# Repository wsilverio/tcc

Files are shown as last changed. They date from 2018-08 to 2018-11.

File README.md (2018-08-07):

# tcc

#### Desenvolvimento de Mesa de Luz Interativa para Experimento de Ciências para Crianças

#### Disposição do Projeto

- [tcc/changelog.md](changelog.md)
  - Registro de alterações
- [tcc/todo.md](todo.md)
  - Lista de tarefas
- [tcc/hardware](hardware/)
  - Arquivos de esquemático
  - Arquivos de leiaute e de produção (gerber)
  - Bibliotecas CAD
  - Cálculos
  - Datasheets
- [tcc/source](source/)
  - Códigos-fonte
  - Bibliotecas
  - Scripts
- [tcc/cad](cad/)
  - Arquivos CAD
  - Documentação da mecânica
- [tcc/documentos](documentos/)
  - Relatórios
  - Burocracia

------

Universidade Federal do Paraná, Setor de Tecnologia, Departamento de Engenharia Elétrica

Autores e Autora: Wendeurick Emerick Silverio, James Alexandre Baraniuk e Maristela Mitsuko Ono.

Curitiba 2018

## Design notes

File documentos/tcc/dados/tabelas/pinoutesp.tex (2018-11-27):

\begin{table}[H]
    \centering
    \caption[Pinagem do módulo ESP-12]{Pinagem do módulo ESP-12.
    \label{tab:pinoutesp}}
\begin{tabular}{|l|l|}
\hline
\textbf{Pino} & \textbf{Descrição} \\ \hline
$V_{CC}$ & Alimentação 3,3\ V \\ \hline
GPIO 13 & Também usada pela SPI \\ \hline
GPIO 12 & Também usada pela SPI \\ \hline
GPIO 14 & Também usada pela SPI \\ \hline
GPIO 16 & Deve ser conectada ao RESET no modo \emph{Deep Sleep} \\ \hline
$CH_{PD}$ & \emph{Chip enable}: (0) desabilitado; (1) habilitado \\ \hline
ADC & Entrada do ADC \\ \hline
RESET & \emph{Reset} externo: (0) - \emph{reset}; (1) - normal \\ \hline
TXD & Transmissão da UART \\ \hline
RXD & Recepção da UART \\ \hline
GPIO 4 & GPIO regular \\ \hline
GPIO 5 & GPIO regular \\ \hline
GPIO 0 & Modo \emph{flah} se em nível baixo durante a inicialização \\ \hline
GPIO 2 & Deve estar em nível alto durante a inicialização \\ \hline
GPIO 15 & Deve estar em nível baixo durante a inicialização e gravação \\ \hline
GND & Terra \\ \hline
\end{tabular}
    \fonte{\cite{book-esp}}
\end{table}

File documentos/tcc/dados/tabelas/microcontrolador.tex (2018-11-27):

\begin{table}[H]
    \centering
    \caption[Especificação do ESP8266]{Especificação do ESP8266.
    \label{tab:espec-microcontrolador}}
    \begin{tabular}{|l|l|}
    \hline
    Alimentação & 3,3\ V \\ \hline
    Consumo & $10\ \mu A - 170\ mA$ \\ \hline
    Memória Flash (externa) & 16\ MB máx. (512\ kB normal) \\ \hline
    CPU & Tensilica L106 32 bits \\ \hline
    \emph{Clock} & $80 - 160\ MHz$ \\ \hline
    RAM & $32\ kB - 80\ kB$ \\ \hline
    GPIOs & 17 (compartilhadas com outras funções) \\ \hline
    ADC & 1 canal (10 \emph{bits} de resolução) \\ \hline
    \emph{Wireless} & Estação, ponto de acesso ou ambos \\ \hline
    \end{tabular}
    \fonte{\cite{book-esp}}
\end{table}

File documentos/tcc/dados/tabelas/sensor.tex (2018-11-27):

\begin{table}[H]
    \centering
    \caption[Principais características do sensor TCRT5000]{Principais características do sensor TCRT5000.
    \label{tab:sensor}}
    \begin{tabular}{|l|l|l|l|l|l|l|}
        \hline
        \textbf{Parâmetro} & \textbf{Condição} & \textbf{Símb.} & \textbf{Mín.} & \textbf{Típ.} & \textbf{Máx.} & \textbf{Unidade} \\     \hline
        \emph{LED} - Corrente direta &  & $I_{F}$ &  & 60 &  & mA \\ \hline
        \emph{LED} - Queda direta de tensão & $I_{F} = 60\ mA$ & $V_{F}$ &  & 1,25 & 1,5 & V \\ \hline
        \emph{LED} - Comprimento de onda & $I_{F} = 100\ mA$ & $\lambda_{P}$ & 940 &  &  & nm \\ \hline
        Sensor - Corrente de coletor & \begin{tabular}[c]{@{}l@{}}$@5\ V$,\\ $I_{F} = 10\ mA$,\\ $D=12\ mm$\end{tabular} & $I_{C}$ & 0,5 & 1 & 2,1 & mA \\ \hline
        \begin{tabular}[c]{@{}l@{}}Sensor - Queda de tensão entre\\ coletor-emissor na saturação\end{tabular} & \begin{tabular}[c]{@{}l@{}}$I_{F} = 10\ mA$, \\ $I_{C}=0,1\ mA$,\\ $D=12\ mm$\end{tabular} & $V_{CE_{sat}}$ &  &  & 0,4 & V \\ \hline
    \end{tabular}
    \fonte{\citeonline{datasheet-sensor}}
\end{table}

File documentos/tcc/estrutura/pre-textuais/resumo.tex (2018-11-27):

% RESUMO--------------------------------------------------------------------------------

\begin{resumo}[RESUMO]
\begin{SingleSpacing}

% Não altere esta seção do texto--------------------------------------------------------
\imprimirautorcitacao. \imprimirtitulo. \imprimirdata. \pageref {LastPage} f. \imprimirprojeto\ – \imprimirprograma, \imprimirinstituicao. \imprimirlocal, \imprimirdata.\\
%---------------------------------------------------------------------------------------

O presente trabalho refere-se ao desenvolvimento do protótipo de uma matriz de LED que será parte da exposição interativa ``Luz, Ciência e Emoção'', idealizada pela arquiteta Dra. Maristela Mitsuko Ono e pelo engenheiro Dr. James Alexandre Baraniuk. A matriz, chamada de ``Mesa de Bolinhas'', se enquadra no setor artístico da exposição, que traz experimentos envolvendo os conceitos de luz trabalhados nos ensinos pré-escolar e fundamental, e proporcionará uma experiência tangível-visual impactante aos observadores, causando deslumbramento e entusiamos através da interação com arte e tecnologia.

O projeto conta com técnicas de \emph{software} e \emph{hardware} para endereçar 129 LEDs RGBs e controlar seus 387 canais de PWM, mapear 128 sensores reflexivos e submetê-los a rotinas de \emph{debouncing}, implementar máquina de estados finita em \emph{firmware}, desenvolver um teclado analógico com apenas uma GPIO, projetar um conversor de nível lógico não-inversor com um único transistor, entre outras funcionalidades.\\

\textbf{Palavras-chave}: Matriz de LED. Matriz de sensores. Arte generativa.

\end{SingleSpacing}
\end{resumo}

% OBSERVAÇÕES---------------------------------------------------------------------------
% Altere o texto inserindo o Resumo do seu trabalho.
% Escolha de 3 a 5 palavras ou termos que descrevam bem o seu trabalho

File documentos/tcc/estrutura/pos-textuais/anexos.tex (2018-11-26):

% ANEXO------------------------------------------------------------------------

\begin{anexosenv}
%\partanexos

%% Primeiro anexo---------------------------------------------------------------
%\chapter{Nome do anexo}     % edite para alterar o título deste anexo
%\label{chap:anexoA}
%
%Lembre-se que a diferença entre apêndice e anexo diz respeito à autoria do texto e/ou material ali colocado.

%Caso o material ou texto suplementar ou complementar seja de sua autoria, então ele deverá ser colocado como um apêndice. %Porém, caso a autoria seja de terceiros, então o material ou texto deverá ser colocado como anexo.

%Caso seja conveniente, podem ser criados outros anexos para o seu trabalho acadêmico. Basta recortar e colar este trecho %neste mesmo documento. Lembre-se de alterar o "label"{} do anexo.

%Organize seus anexos de modo a que, em cada um deles, haja um único tipo de conteúdo. Isso facilita a leitura e compreensão %para o leitor do trabalho. É para ele que você escreve.
%
%% Novo anexo-------------------------------------------------------------------
%\chapter{Nome do outro anexo}
%\label{chap:anexoB}
%
%conteúdo do outro anexo

\end{anexosenv}

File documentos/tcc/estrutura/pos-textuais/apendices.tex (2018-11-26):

% APÊNDICES--------------------------------------------------------------------

\begin{apendicesenv}
\partapendices

%\chapter{application.cpp} 
%\inputminted{cpp}{dados/algoritmos/application.cpp}

%\chapter{user_config.h} 
%\label{chap:user-config}
%\inputminted{cpp}{dados/algoritmos/user_config.h}

\chapter{plomodefs.h} 
\inputminted{cpp}{dados/algoritmos/plomodefs.h}

\chapter{plomotypes.h} 
\inputminted{cpp}{dados/algoritmos/plomotypes.h}

\chapter{tabmask8.h} 
\inputminted{cpp}{dados/algoritmos/tabmask8.h}

\chapter{sensors.h} 
\inputminted{cpp}{dados/algoritmos/sensors.h}

\chapter{hardware.h} 
\inputminted{cpp}{dados/algoritmos/hardware.h}

\chapter{application.cpp} 
\inputminted{cpp}{dados/algoritmos/application.cpp}

\chapter{hardware.cpp} 
\inputminted{cpp}{dados/algoritmos/hardware.cpp}

\chapter{sensors.cpp} 
\inputminted{cpp}{dados/algoritmos/sensors.cpp}

\end{apendicesenv}

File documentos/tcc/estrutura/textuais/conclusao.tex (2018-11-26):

% CONCLUSÃO--------------------------------------------------------------------

\chapter{CONCLUSÃO}
\label{chap:conclusao}

O principal objetivo deste trabalho era apresentar um protótipo funcional para a Mesa de Bolinhas. Embora não tenha sido atingido em sua totalidade, o projeto se encontra em uma etapa avançada. Entre os objetivos específicos apresentados, foram finalizadas as etapas do mapeamento da matriz de saída (LEDs), do mapeamento da matriz de entrada (sensores da matriz e do seletor de cores), do leiaute da placa de interface, do leiaute da placa de controle, do \emph{firmware} gerenciador da matriz de entrada, da montagem das placas de interface, sendo ainda pendente a montagem da placa de controle, a integração com a mecânica e a finalização das rotinas da máquina de estados finita.

Para o autor, o projeto serviu de grande aprendizado de técnicas e ferramentas não abordadas durante a graduação, tais como: projeto de leiaute de placa de circuito impresso a nível intermediário, programação do microcontrolador ESP8266, programação orientada a eventos temporais, implementação de fila (FIFO), implementação de técnica de \emph{debouncing} para múltiplas entradas, implementação de máquina de estados finita em \emph{software}, entre outras.

\section{TRABALHOS FUTUROS}
\label{sec:trabalhosFuturos}

Para que o projeto continue avançando, pretende-se, além de finalizar a montagem proposta neste trabalho, implementar novas funcionalidades, funções estas que não necessitam de alteração de \emph{hardware}, visto que já foram consideradas no projeto dos circuitos:

\begin{itemize}
    \item Gravação OTA (\emph{over-the-air}): com essa funcionalidade, o microcontrolador poderá ser reprogramado sem a necessidade do adaptador USB: a gravação será via Wi-Fi, dispensando a remoção do tampo acrílico todas as vezes que uma atualização for necessária;
    \item Protocolo ArtNet: permitirá que a mesa seja comandada remotamente através de programas de mapeamento de luz (via Wi-Fi, sobre a camada de UDP). Assim, a matriz poderá servir como tela para animações e exibição de textos e imagens;
    \item Fita de LED externa: foi implementado em \emph{hardware} uma saída para fitas de LED com suporte ao protocolo NRZ. Dessa forma, a mesa também poderá controlar outras instalações, sem a necessidade de um circuito dedicado
    
\end{itemize}

Além disso, o \emph{hardware} e o código serão documentados e disponibilizados à comunidade, para que o projeto possa ser estudado, replicado e modificado conforme suas necessidades.

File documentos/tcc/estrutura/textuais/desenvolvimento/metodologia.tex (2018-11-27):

% METODOLOGIA------------------------------------------------------------------

\chapter{DESENVOLVIMENTO}
\label{chap:metodologia}

Este capítulo aborda o desenvolvimento do \emph{hardware} do projeto, desde a concepção do projeto eletrônico, levantamento do circuito elétrico, até as técnicas de roteamento das placas de circuito impresso.

\section{CONCEPÇÃO DO PROJETO}
\label{sec:concepcao}

Com base no projeto arquitetônico e a partir do levantamento das tecnologias disponíveis e viáveis (sobretudo pelo custo e pela difusão no mercado), foram definidos os componentes e técnicas a serem utilizadas no projeto eletrônico, cujo diagrama geral é apresentado na \autoref{fig:diagramageral}.

\begin{figure}[H]
    \centering
    \caption{Diagrama geral do projeto eletrônico}
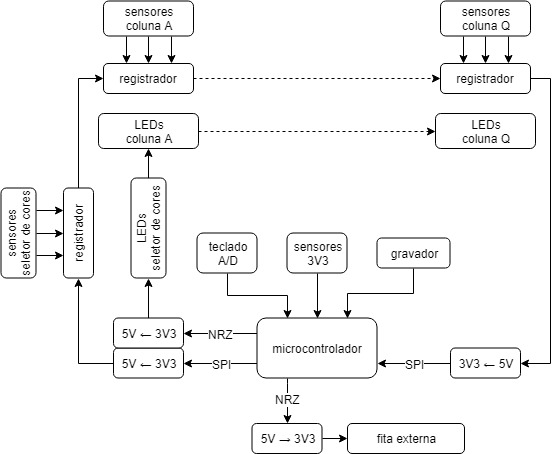
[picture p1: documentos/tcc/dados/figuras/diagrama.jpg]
    
    \fonte{(O AUTOR, 2018)}
    \label{fig:diagramageral}
\end{figure}

A partir do projeto arquitetônico (\autoref{fig:mesa-sup}), que é segmentado em duas partes: Matriz (interação) e Controle (seletor de cores), o projeto eletrônico também foi organizado em 3 subdivisões: Matriz, Interface e Controlador, apresentadas na \autoref{fig:subsecoes}. Dessa forma, pôde-se dar andamento ao projeto por meio de etapas, onde cada fase pode ser considerada um projeto íntegro por si só.

\begin{figure}[H]
    \centering
    \caption{As 3 subseções principais do projeto eletrônico}
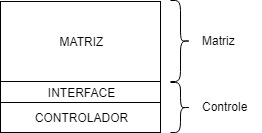
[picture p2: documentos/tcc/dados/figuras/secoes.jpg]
    
    \fonte{(O AUTOR, 2018)}
    \label{fig:subsecoes}
\end{figure}

As subdivisões têm funções bem definidas, apresentadas logo abaixo, e serão discutidas neste mesmo capítulo nos tópicos a seguir.

\begin{itemize}
    \item \textbf{Matriz:} é o setor que pode ser ``pintado com luz'', que contém os LEDs e os sensores de interação. É inteiramente comandada pelo Controlador, através da Interface;
    \item \textbf{Interface:} interliga as subseções Matriz e Controlador: captura e propaga o sinal dos sensores, através dos registradores de deslocamento, e forma a ligação sequencial do barramento dos LEDs;
    \item \textbf{Controlador:} processa todos os LEDs e sensores da mesa. Contém também os LEDs e os sensores do seletor de cores, a parte de processamento, os conversores de nível lógico e os periféricos de gravação e depuração.
\end{itemize}

%\textcolor{red}{TODO: especificações, tensão}

%\textcolor{red}{TODO: software}

\section{PROJETO DA MATRIZ}
\label{sec:matriz}

O projeto da Matriz foi concebido durante o Programa de Iniciação Científica do qual o autor participou. Nele, o desafio foi o de contemplar todas as 118 bolinhas de \emph{ping-pong} desta seção (e seus respectivos pares sensor-LED), visando robustez e o menor custo.

Para tal, foi definido que a matriz seria arranjada em 17 colunas verticais, conforme apresentado na \autoref{fig:placas-matriz-colunas}. Consequentemente, devido à disposição dos objetos (determinada pelo projeto arquitetônico), essas colunas poderiam conter 5, 6, 7 ou 8 bolinhas e, para abrangê-las da maneira mais proveitosa, as colunas foram combinadas por módulos (placas) de 2 ou 3 bolinhas.

Em geral, as empresas fabricantes de placas de circuito impresso consideram cada modelo de placa como um projeto, devido ao corte do painel, procedimento para os testes elétricos, etc. Assim, se utilizando de apenas 2 modelos de placa, foi possível reduzir o custo do projeto sem dispensar a robustez que as PCIs proporcionam.

\begin{figure}[H]
    \centering
    \caption{Disposição das placas da Matriz}
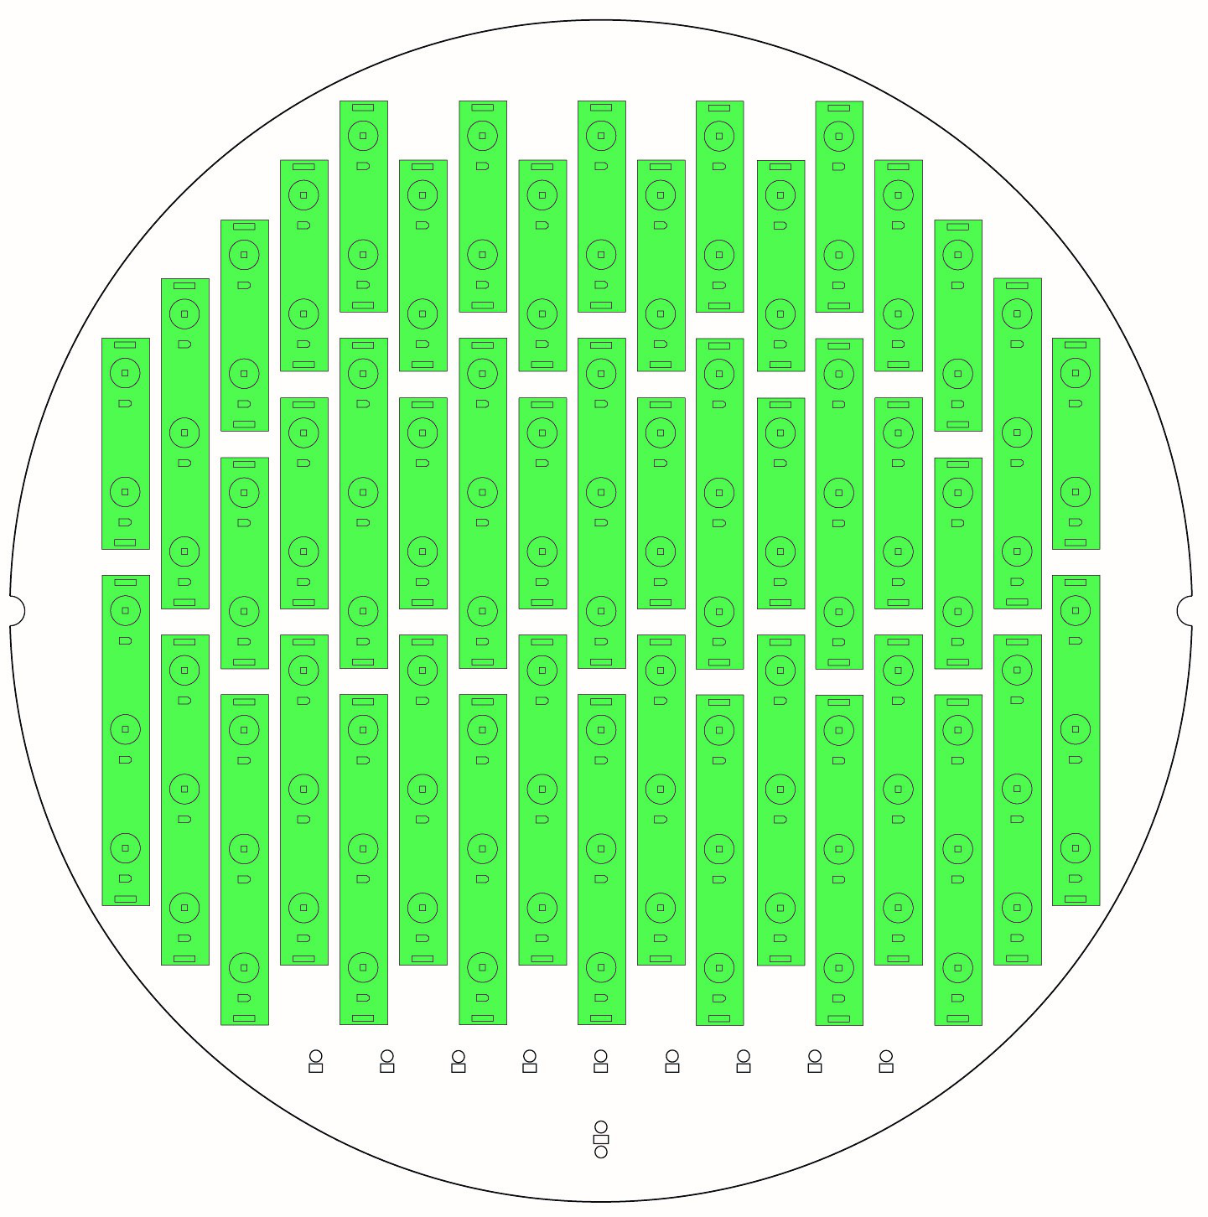
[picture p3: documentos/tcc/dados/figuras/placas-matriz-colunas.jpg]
    
    \fonte{adaptado de (MITSUKO, 2016)}
    \label{fig:placas-matriz-colunas}
\end{figure}

Uma vez definido que a matriz seria composta por placas com 2 ou 3 bolinhas, iniciaram-se os testes de conceito com o protótipo artesanal, apresentado na \autoref{fig:matriz-prototipo}, produzido no Laboratório de Corrosão de Placas do Departamento de Engenharia Elétrica da UFPR. Nesses ensaios, foram testados os conceitos de endereçamento do LED WS2812, a leitura do nível lógico dos sensores através dos registradores de deslocamento e também o modo de conexão entre as placas.

\begin{figure}[H]
    \centering
    \caption{Protótipo das placas da matriz}
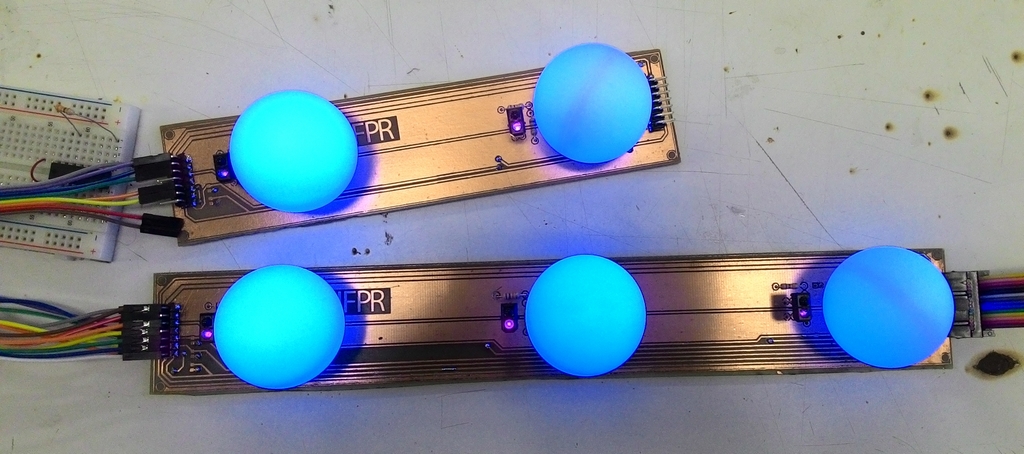
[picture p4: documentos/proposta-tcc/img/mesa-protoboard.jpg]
    
    \fonte{(O AUTOR, 2017)}
    \label{fig:matriz-prototipo}
\end{figure}

Todos os conceitos propostos foram validados e as 47 placas que compõem a matriz foram confeccionadas em produção industrial. A \autoref{fig:placa2} e a \autoref{fig:placa3} apresentam as faces superior e inferior dos módulos.

\begin{figure}[H]
    \centering
    \caption{Faces da PCI do módulo de 2 bolinhas}
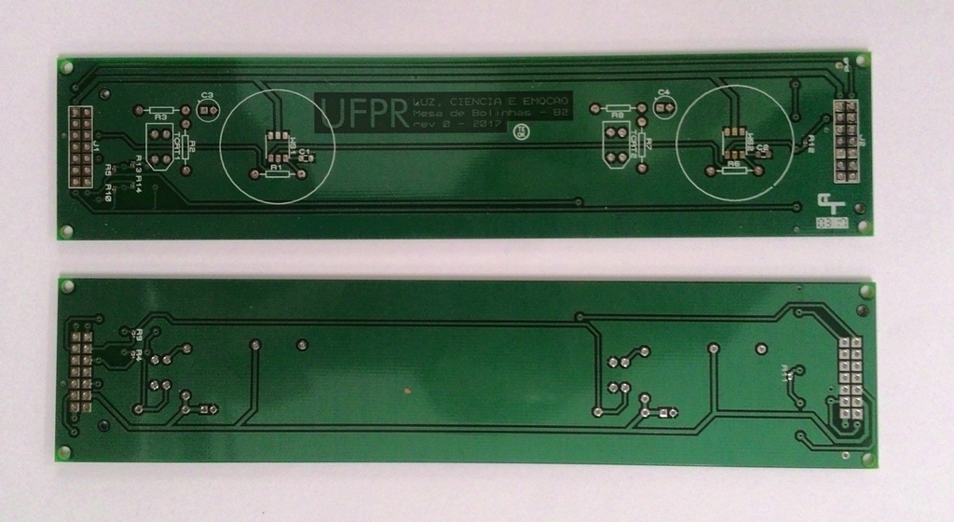
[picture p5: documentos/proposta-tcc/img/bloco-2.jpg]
    
    \fonte{(O AUTOR, 2017)}
    \label{fig:placa2}
\end{figure}

\begin{figure}[H]
    \centering
    \caption{Faces da PCI do módulo de 3 bolinhas}
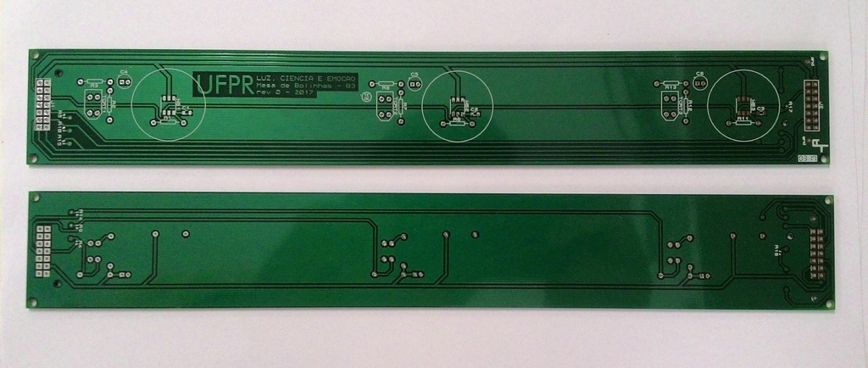
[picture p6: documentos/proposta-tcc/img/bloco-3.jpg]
    
    \fonte{(O AUTOR, 2017)}
    \label{fig:placa3}
\end{figure}

\section{PROJETO DA INTERFACE}
\label{sec:interface}

Como já brevemente introduzido pela \autoref{sec:concepcao} (Concepção do Projeto), a Interface tem a função de interligar as seções Matriz e Controlador. Contudo, deve-se atentar a algumas questões:

\begin{enumerate}[label=\Roman*.]
    \item Tanto o barramento dos sensores, quanto o barramento dos LEDs devem seguir a sequência da esquerda para a direita; de baixo para cima;
    \item Por integrar barramentos de frequências razoáveis - NRZ {@800\ kHz} e SPI {@4\ MHz} dos LEDs e sensores, respectivamente - deve-se evitar construir trilhas com quinas abruptas, em função da reflexão do sinal;
    %\item As trilhas de potência devem ser adequadas para suportarem a corrente no caso mais extremo.
\end{enumerate}

A questão (I) foi trabalhada visando a redução de custo, decidiu-se que Interface também seria um projeto modular, isto é, esta seção seria dividida em placas do mesmo modelo. Isso é em razão do valor das placas de circuito impresso ser calculado em função de sua área e que cada projeto possui um pedido mínimo. Em outras palavras, quanto maior a área de uma PCI, maior será o seu custo, e quanto mais modelos de placa, maior será a quantidade a ser adquirida, pois cada modelo possui um pedido mínimo para produção. Sendo assim, a Interface foi projetada para abranger todas as colunas da Matriz em duas ``metades'', como é apresentado na \autoref{fig:colunas}. No caso, uma placa teria a função de operar as primeiras 9 colunas (de A a I) e a outra, as 8 colunas restantes (de J a Q).

\begin{figure}[H]
    \centering
    \caption{Divisão das colunas para conexão com a Interface}
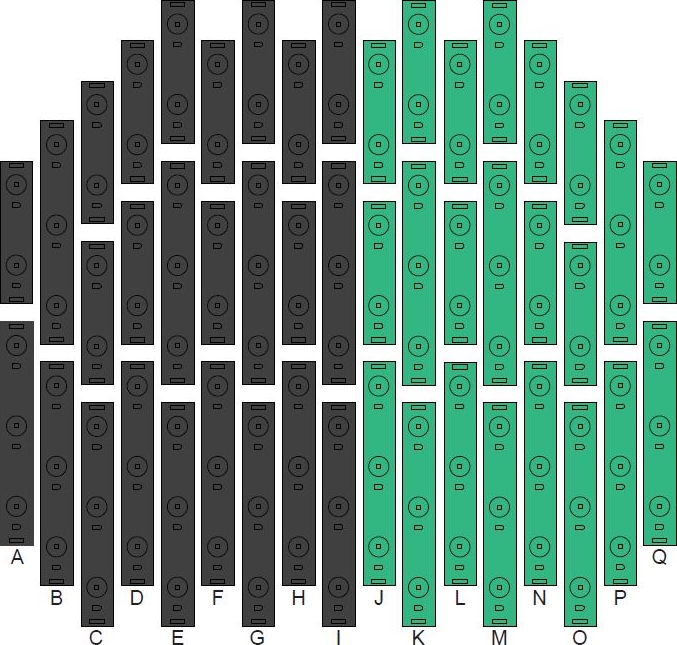
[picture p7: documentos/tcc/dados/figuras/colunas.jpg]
    
    \fonte{adaptado de (MITSUKO, 2016)}
    \label{fig:colunas}
\end{figure}

A \autoref{fig:diagrama-interface} apresenta o diagrama da formação do barramento dos sensores. Nele, cada coluna da Matriz é conectada a um registrador de deslocamento, em forma sequencial (A:1, ..., I:9; J:1, ..., Q:8). Nota-se também que o último registrador da segunda placa não possui conexão, dado que todas as colunas já foram abrangidas pelos registradores precedentes.

\begin{figure}[H]
    \centering
    \caption{Diagrama do barramento da Interface}
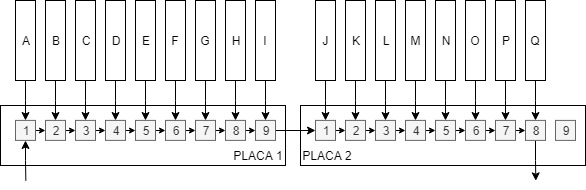
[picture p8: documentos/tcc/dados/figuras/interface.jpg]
    
    \fonte{(O AUTOR, 2018)}
    \label{fig:diagrama-interface}
\end{figure}

Esse direcionamento do barramento é dado por um resistor de {$0\ \Omega$}, como apresentado na \autoref{fig:direcionamento-shift} (componente ``R2''). Se montado, o sinal é diretamente conduzido ao conector de saída (``P11''), ignorando o último registrador (``U9'') que, neste caso, não seria montado.

\begin{figure}[H]
    \centering
    \caption{Direcionamento do barramento dos sensores}
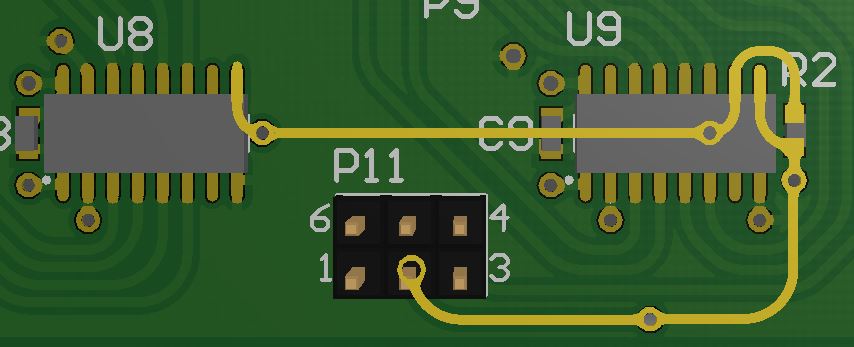
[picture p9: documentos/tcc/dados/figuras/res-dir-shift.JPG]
    
    \fonte{(O AUTOR, 2018)}
    \label{fig:direcionamento-shift}
\end{figure}

De iguais modos, o barramento dos LEDs foi projetado para seguir a mesma sequência (\autoref{fig:sentido-leds}) e o direcionamento entre a última coluna (``P9'') ou o conector de saída (``P11'') também é dado através de um resistor de {$0\ \Omega$} (``R1''), como apresentado na \autoref{fig:direcionamento-leds}.

\begin{figure}[H]
    \centering
    \caption{Sentido do barramento dos LEDs}
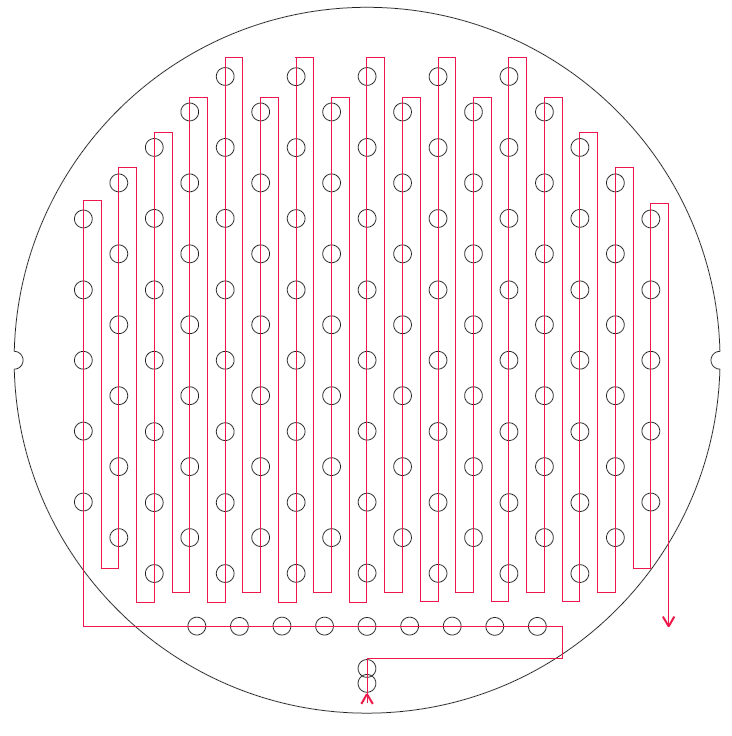
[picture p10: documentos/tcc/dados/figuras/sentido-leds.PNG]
    
    \fonte{adaptado de (MITSUKO, 2016)}
    \label{fig:sentido-leds}
\end{figure}

\begin{figure}[H]
    \centering
    \caption{Direcionamento do barramento dos LEDs}
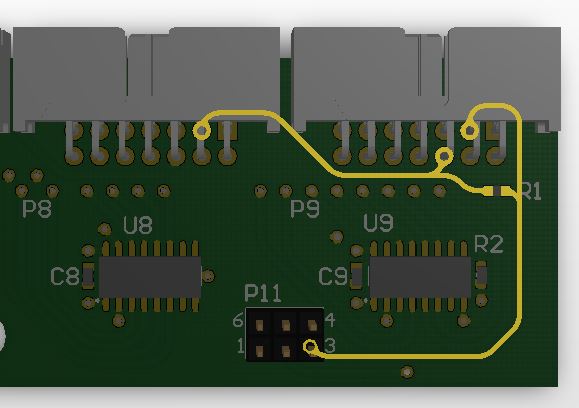
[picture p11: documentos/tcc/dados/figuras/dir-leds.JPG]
    
    \fonte{(O AUTOR, 2018)}
    \label{fig:direcionamento-leds}
\end{figure}

Já em relação à questão (II), sobre a possibilidade de reflexão de sinais devido à perturbação da capacitância e auto-indutância da trilha, seguiu-se a recomendação de leiaute de \cite{datasheet-ti}, apresentada na \autoref{fig:leiaute-ti}.

\begin{figure}[H]
    \centering
    \caption{Recomendação de leiaute para as trilhas de sinal}
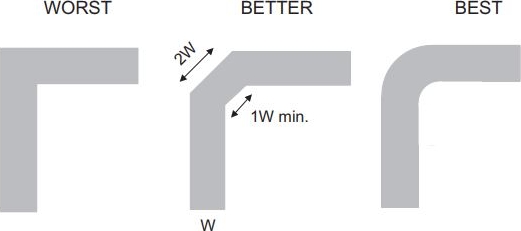
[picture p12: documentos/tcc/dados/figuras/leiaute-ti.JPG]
    
    \fonte{\citeonline{datasheet-ti}}
    \label{fig:leiaute-ti}
\end{figure}

Tal técnica foi aplicada não só nas trilhas de sinais, mas também em todas as ocasiões possíveis, como apresentado na \autoref{fig:trilhas-arredondadas}.

\begin{figure}[H]
    \centering
    \caption{Trilhas arredondadas}
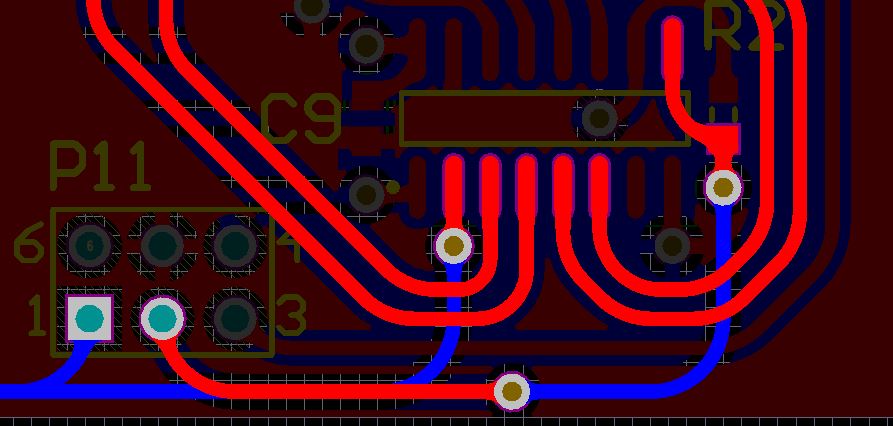
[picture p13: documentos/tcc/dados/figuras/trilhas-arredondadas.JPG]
    
    \fonte{(O AUTOR, 2018)}
    \label{fig:trilhas-arredondadas}
\end{figure}

Além disso, para evitar a propagação do ruído da parte de potência, a alimentação do circuito lógico (``VCC5V'') foi separada da alimentação dos LEDs (``VLED'') e da dos sensores (``VSENSOR''), conforme apresentado na \autoref{fig:interface-alimentacao}. Ademais, a conexão física entre as massas (terra) é feita somente em um único ponto, assim, o retorno da alimentação de potência ("GND\_MATRIX") permanece confinado, não circulando sobre o plano de terra ("GND"). Essa técnica é conhecida por \emph{``net-tie''} e está destacada na \autoref{fig:interface-nettie}.

\begin{figure}[H]
    \centering
    \caption{Separação das alimentações da Interface}
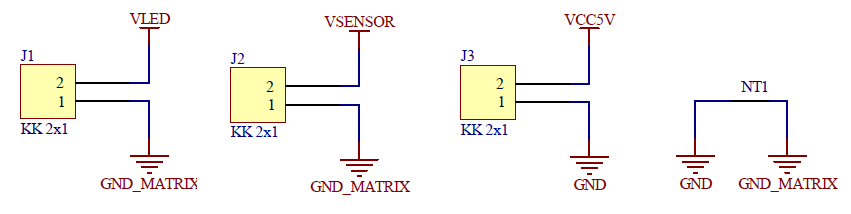
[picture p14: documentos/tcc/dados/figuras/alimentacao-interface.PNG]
    
    \fonte{(O AUTOR, 2018)}
    \label{fig:interface-alimentacao}
\end{figure}

\begin{figure}[H]
    \centering
    \caption{Separação física das massas}
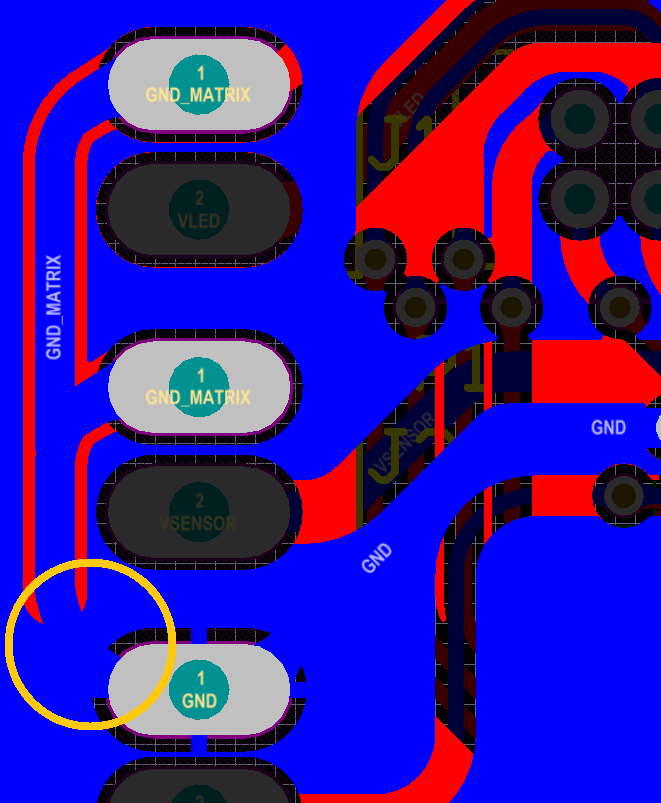
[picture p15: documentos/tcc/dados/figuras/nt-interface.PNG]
    
    \fonte{(O AUTOR, 2018)}
    \label{fig:interface-nettie}
\end{figure}

Por fim, a \autoref{fig:3d-interface} apresenta o modelo 3D da placa de interface. Trata-se de uma PCI face-dupla, {245\ mm} x {32,76\ mm}. Os conectores de alimentação (à esquerda da placa) são da série KK Molex\textsuperscript{\textregistered}, que impedem a inversão de polaridade na conexão com fonte de alimentação externa, e os conectores das colunas (parte superior da placa) são do padrão \emph{Latch-header}, recomendado para aplicações com limitação de espaço. Cada placa suporta até 9 colunas de até 8 sensores, e as PCIs podem ser ligadas em série para compartilharem o mesmo barramento.

\begin{figure}[H]
    \centering
    \caption{Modelo 3D da Interface}
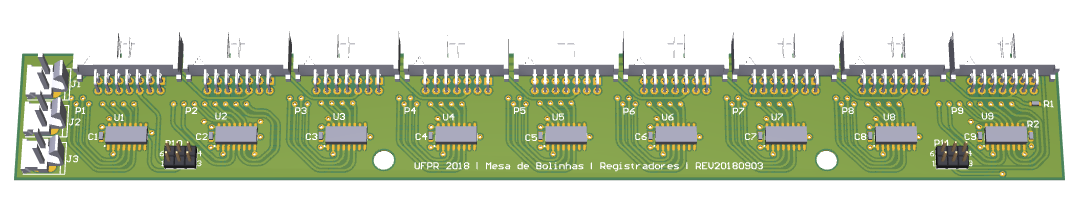
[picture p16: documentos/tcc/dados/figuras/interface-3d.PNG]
    
    \fonte{(O AUTOR, 2018)}
    \label{fig:3d-interface}
\end{figure}

\section{PROJETO DO CONTROLADOR}
\label{sec:controlador}

O Controlador é responsável por comandar os eventos de interação, através da Interface, da seção Matriz. Ademais, engloba também o seletor de cores, circuito de gravação, teclado para depuração e suporte para um barramento externo. A \autoref{fig:diagrama-controlador} apresenta seu diagrama simplificado.

\begin{figure}[H]
    \centering
    \caption{Diagrama da seção Controlador}
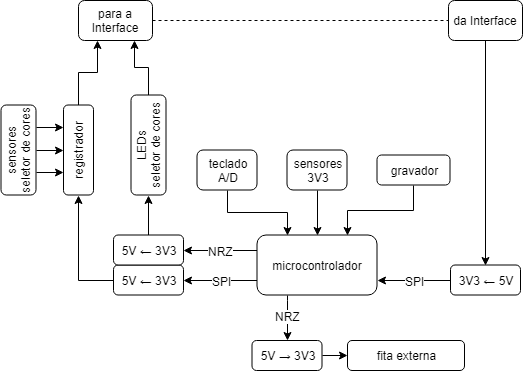
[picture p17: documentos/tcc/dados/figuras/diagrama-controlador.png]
    
    \fonte{(O AUTOR, 2018)}
    \label{fig:diagrama-controlador}
\end{figure}

\subsection{ALIMENTAÇÃO  E CONVERSÃO DE NÍVEL LÓGICO}
\label{subsec:alimentacao}

Da mesma forma que na Interface, a alimentação do Controlador também foi dividida, separando os circuitos de potência (``VLED'') e lógico (``VCC5V''), inclusive com \emph{net-tie} isolando fisicamente as massas. Porém, diferente da Matriz, onde a quantidade de LEDs e sensores é muito maior que a do seletor de cores do Controlador, esses circuitos compartilham a mesma alimentação de potência neste projeto. A \autoref{fig:alimentacao-controlador} apresenta o circuito de entrada de alimentação.

Como o microcontrolador operar em {3,3\ V}, houve a necessidade de incluir um regulador para a faixa especificada. Por se tratar de um circuito de carga simples, isto é, de baixo consumo, optou-se por um regulador linear de saída fixa (componente ``U2''). Para protegê-lo da descarga das capacitâncias conectadas à sua saída (por exemplo, o capacitor ``C23''), foi incluído um diodo de \emph{bypass} (``D27'') para desviar a corrente reversa sobre regulador, no caso da fonte externa ser desconectada e a tensão de saída resultar em um potencial mais alto que o de entrada. Esse diodo também possui a função de proteger o regulador caso o desenvolvedor queira alimentar a placa diretamente através do circuito de gravação, a ser discutido mais adiante.

\begin{figure}[H]
    \centering
    \caption{Entrada de alimentação do Controlador}
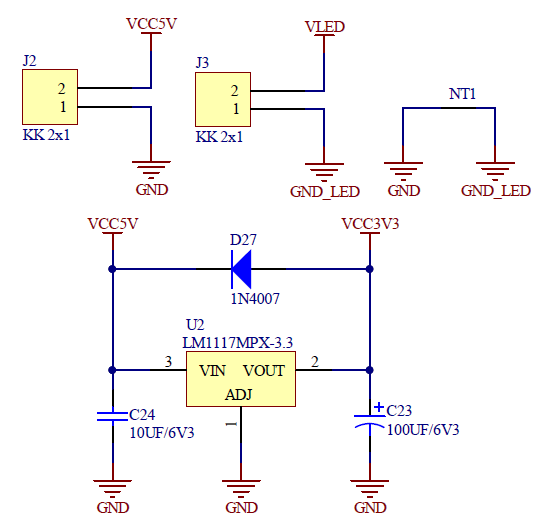
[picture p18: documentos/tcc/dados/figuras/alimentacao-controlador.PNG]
    
    \fonte{(O AUTOR, 2018)}
    \label{fig:alimentacao-controlador}
\end{figure}

\subsection{SELETOR DE CORES}
\label{subse:seletor}

O seletor de cores forma a primeira etapa dos barramentos, seja dos LEDs endereçáveis ou dos registradores de deslocamento. É composto por 10 sensores reflexivos e 11 LEDs endereçáveis, como apresentado na \autoref{fig:seletor-cores}, e a \autoref{fig:diagrama-seletor-cores} apresenta seu diagrama.

\begin{figure}[H]
    \centering
    \caption{Vista do seletor de cores}
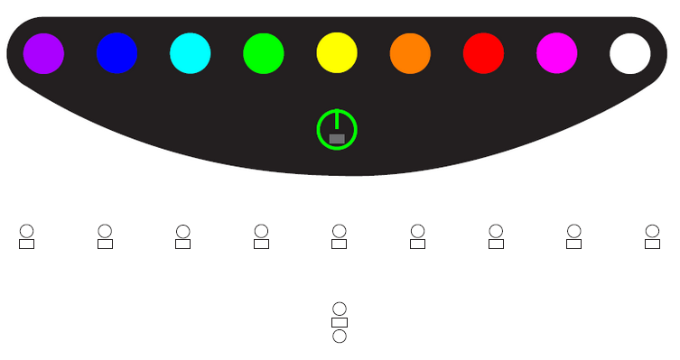
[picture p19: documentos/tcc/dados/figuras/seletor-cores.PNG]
    
    \fonte{adaptado de (MITSUKO, 2016)}
    \label{fig:seletor-cores}
\end{figure}

\begin{figure}[H]
    \centering
    \caption{Vista do seletor de cores}
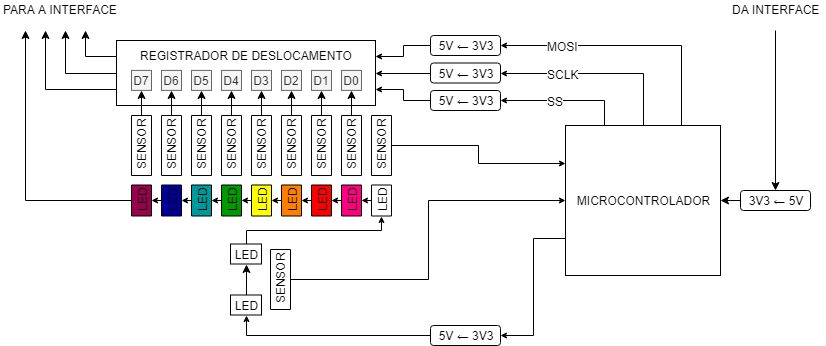
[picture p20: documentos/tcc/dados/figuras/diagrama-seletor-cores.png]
    
    \fonte{(O AUTOR, 2018)}
    \label{fig:diagrama-seletor-cores}
\end{figure}

Assim como feito com as colunas da Matriz, por meio das placas da Interface, o registrador de deslocamento é responsável por coletar os níveis lógicos de 8 dos 10 sensores do seletor de cores, restando 2 sensores fora do barramento. Assim, optou-se por conectá-los diretamente aos pinos do microcontrolador, visto que haviam GPIOs livres.

Devido aos LEDs e registradores de deslocamento serem alimentados em {5\ V}, enquanto que o microcontrolador é alimentado em {3,3\ V}, foi necessário adequar os sinais dos barramentos através de conversores de nível lógico. Essa conversão se deu de duas formas, nos seguintes sinais:

\begin{itemize}
    \item De {3,3\ V} para {5\ V}:
        \begin{itemize}
            \item Saída de dados do barramento NRZ (LEDs WS2812)
            \item Saída de dados do barramento SPI (MOSI)
            \item Saída de clock do barramento SPI (SCLK)
            \item Sinal de seleção de periférico do barramento SPI (SS)
        \end{itemize}
    \item De {5\ V} para {3,3\ V}:
        \begin{itemize}
            \item Entrada de dados do barramento SPI (MISO)
        \end{itemize}
\end{itemize}

Os conversores de nível de {3,3\ V} para {5\ V} foram projetados na topologia não-inversora, com transistor NPN operando nas regiões de corte e saturação: mantêm-se base e coletor polarizados - base em {3,3\ V} e coletor em {5\ V} - enquanto que a polarização da junção base-emissor ($V_{BE}$) é dada pela aplicação do sinal no emissor.

A \autoref{fig:3v3-5v} apresenta o esquemático do conversor para o sinal de \emph{clock} do barramento SPI. Nota-se que, quando o sinal ``ESP\_CLOCK'' (saída SCLK do microcontrolador ESP8266) vai a 1-lógico ({3,3\ V}), não há diferença de potencial entre a base e o emissor ({$V_{BE}=0\ V$}), portanto, o transistor está em corte, logo a saída ``SHIFT\_CLK'' (entrada de \emph{clock} do \emph{shift-register}) vai a {5\ V} (1-lógico).

No caso da aplicação de {0\ V} (0-lógico) por ``ESP\_CLOCK'', a junção base-emissor estará diretamente polarizada, o que, neste caso, levará o transistor à saturação. Com isso, a tensão em ``SHIFT\_CLK'' será a diferença de potencial entre coletor e emissor ($V_{CE}$) somada à queda de tensão sobre o \emph{mosfet} interno da GPIO do microcontrolador, resultando em um potencial relativamente próximo a {0\ V} (0-lógico).

Cabe aqui ressaltar inclusão do diodo de \emph{Baker clamping} para minimizar os efeitos das capacitâncias parasitas do transistor.

\begin{figure}[H]
    \centering
    \caption{Conversor de nível lógico da linha de \emph{clock} do barramento SPI}
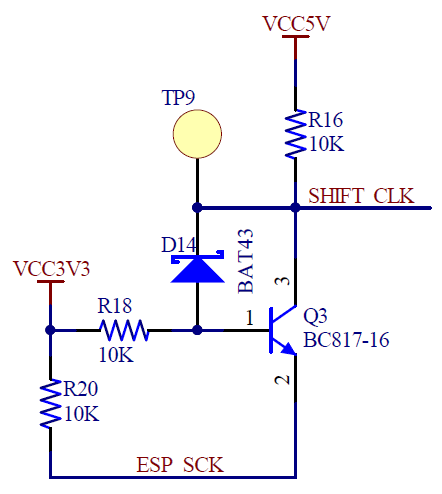
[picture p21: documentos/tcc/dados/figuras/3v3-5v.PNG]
    
    \fonte{(O AUTOR, 2018)}
    \label{fig:3v3-5v}
\end{figure}

Já para a situação de transformação de {5\ V} para {3,3\ V}, como é o caso do retorno do sinal dos registradores de deslocamento das placas de interface (sinal MISO), a implementação do conversor de nível lógico foi dada por um simples divisor resistivo, como apresentado na \autoref{fig:5v-3v3}.

\begin{figure}[H]
    \centering
    \caption{Conversor de nível lógico da linha MISO do barramento SPI}
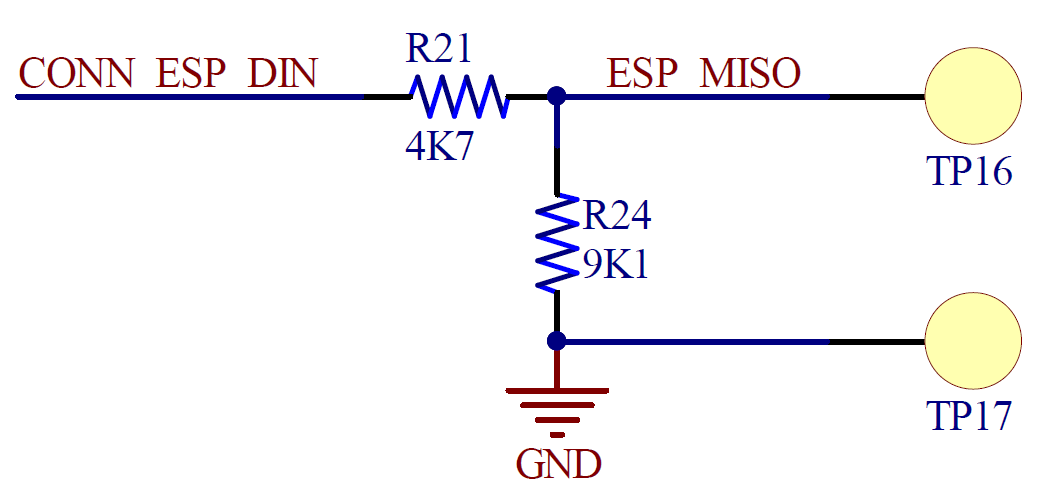
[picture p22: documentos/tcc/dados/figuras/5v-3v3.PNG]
    
    \fonte{(O AUTOR, 2018)}
    \label{fig:5v-3v3}
\end{figure}

Quando aplicado {5\ V} (1-lógico) em ``CONN\_ESP\_DIN'' (entrada de dados do conector, linha MISO do barramento SPI), a tensão em ``ESP\_MISO'' (linha MISO do microcontrolador) será aproximadamente {3,3\ V} (1-lógico), dado pela \autoref{eq:5v-3v3}. De mesmo modo, quando aplicado {0\ V} na entrada do conversor, não haverá queda de tensão sobre o resistor de saída (''`R24``), portanto a tensão em ``ESP\_MISO'' também será {0\ V} (0-lógico).

\begin{equation}
    V = {5\ V} \cdot \frac{9100\ \Omega}{9100\ \Omega+4700\ \Omega} = 3,297\ V
    \label{eq:5v-3v3}
\end{equation}

\subsection{GRAVADOR}
\label{subsec:gravador}

O microcontrolador ESP8266 possui alguns modos de operação, entre eles, o modo normal e o de gravação via UART, que são determinados pelo estado de alguns pinos durante a inicialização do sistema (\emph{boot}), como brevemente introduzido na \autoref{sec:microcontrolador}.

Além de fornecer uma via para a comunicação serial com um adaptador USB, o circuito apresentado a seguir (\autoref{fig:circuito-gravador}) também tem a função de forçar o microcontrolador a entrar em modo de gravação conforme os comandos de \emph{``reset''} e \emph{``data terminal ready''} (DTR) do adaptador. Dessa forma, não há a necessidade de uma operação manual para determinar os estados dos pinos de programação para carregar um novo \emph{firmware} no microcontrolador. Para tal, basta somente que o adaptador disponha de uma linha DTR, como o exemplo apresentado na \autoref{fig:ftdi}. Cabe aqui ressaltar que, assim como citado na \autoref{subsec:alimentacao}, todo o circuito de {3,3\ V} pode ser alimentado diretamente pelo adaptador USB (desde que seja {3,3\ V}), sem a necessidade de uma fonte externa. Isso simplifica o desenvolvimento e a depuração do projeto, quando não houver a necessidade de testar o restante do circuito.

\begin{figure}[H]
    \centering
    \caption{Exemplo de adaptador serial-USB com linha DTR}
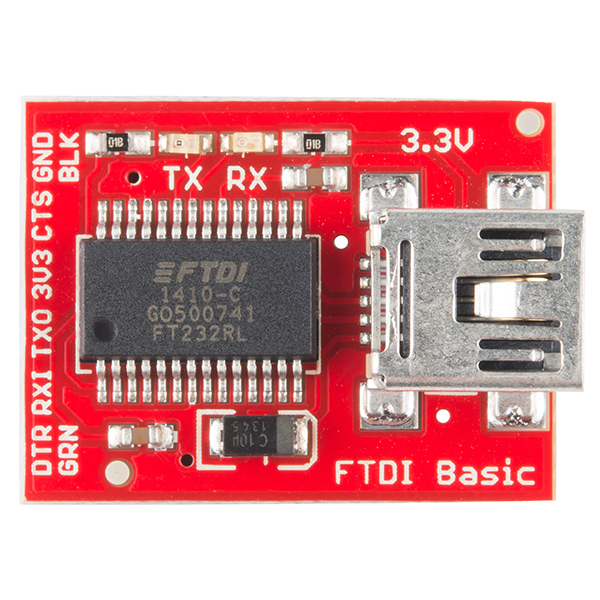
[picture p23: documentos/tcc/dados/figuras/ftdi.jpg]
    
    \fonte{\citeonline{adaptador-usb}}
    \label{fig:ftdi}
\end{figure}

Sobretudo, para que o microcontrolador entre em modo de gravação, o pino ``GPIO 0'' deve estar em 0-lógico durante a inicialização. Se estiver em 1-lógico durante o \emph{reset}, o ESP8266 inicializa em modo normal, executando o programa armazenado na memória interna.

\begin{figure}[H]
    \centering
    \caption{Esquemático do circuito de gravação}
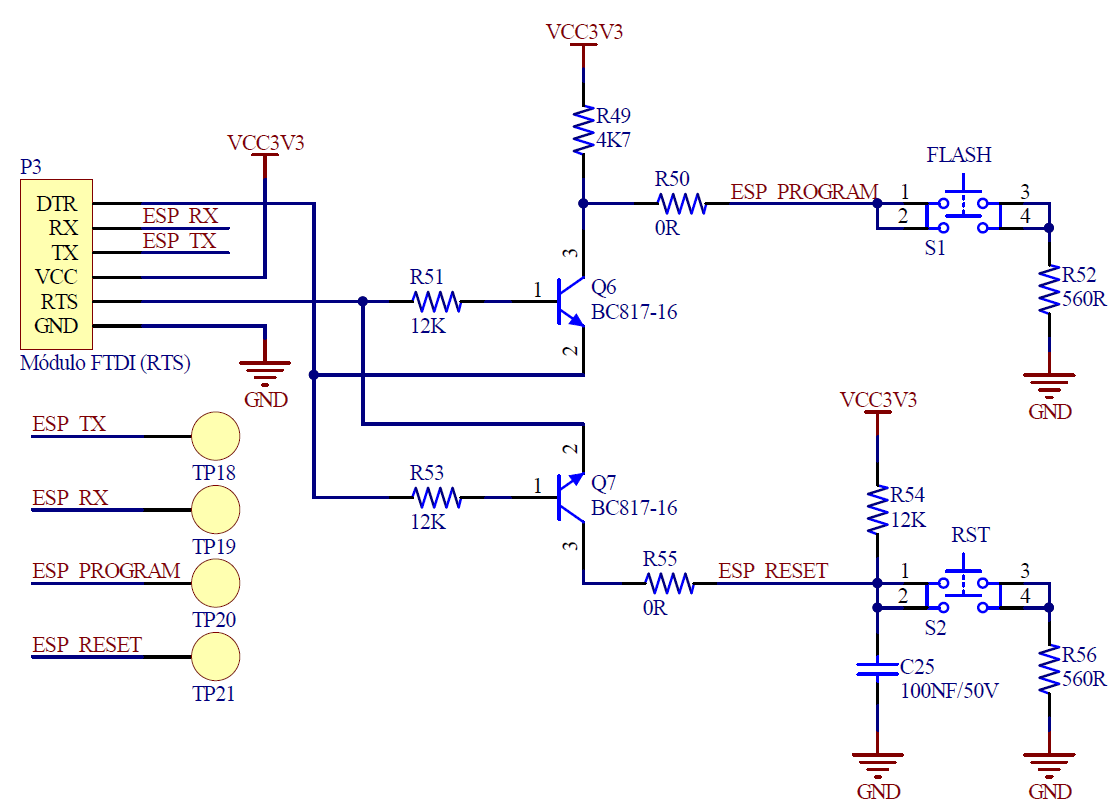
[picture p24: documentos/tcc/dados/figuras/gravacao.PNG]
    
    \fonte{(O AUTOR, 2018)}
    \label{fig:circuito-gravador}
\end{figure}

A \autoref{tab:gravador} apresenta os estados dos pinos do microcontrolador em função dos níveis do adaptador USB, através do circuito da \autoref{fig:circuito-gravador}. Contudo, se o desenvolvedor não dispor de um adaptador USB com sinal DTR, ainda há a possibilidade de pôr o microcontrolador em modo de gravação de maneira manual, através dos botões ``S1'' e ``S2''.

\input{./dados/tabelas/gravacao}

\subsection{TECLADO AD}
\label{subsec:tecladoad}

O ``Teclado AD'' (ou teclado analógico) tem a função de servir como interface durante as etapas de desenvolvimento/depuração. Com apenas um único pino do microcontrolador é possível ler diversas teclas, desde que seja um pino com função Conversor Analógico-Digital. A \autoref{fig:tecladoad} apresenta o esquemático do circuito.

\begin{figure}[H]
    \centering
    \caption{Esquemático do circuito do teclado analógico}
    
    \fonte{(O AUTOR, 2018)}
    \label{fig:tecladoad}
\end{figure}

Seu funcionamento se dá por meio da combinação de uma cadeia de resistores. Através da Lei de Ohm, pelas combinações série-paralelo, é possível estimar qual botão está sendo pressionado, limitando-se a um botão por vez.

A \autoref{tab:tecladoad} apresenta os valores de tensão e as unidades estimadas pelo conversor interno do microcontrolador, um ADC de 10 \emph{bits} de resolução, com faixa de operação de {0\ V} a {1\ V}.

\input{./dados/tabelas/tecladoad}

\subsection{PROJETO DA PCI DO CONTROLADOR}
\label{subsec:pcicontrol}

Em sua totalidade, não há um padrão de repetição de funcionalidades como nos outros setores (Interface e Matriz), então a placa do Controlador não foi projetada de maneira modular, senão em placa única que, inclusive, resultou em uma PCI relativamente grande (500 mm x 90 mm), a ser discutida na \autoref{chap:analise-resultados}.A \autoref{fig:controlador-top} apresenta a visão da face superior do modelo 3D da placa, e a \autoref{fig:controlador-bottom} apresenta a visão da face inferior.

\begin{figure}[H]
    \centering
    \caption{Visão superior do modelo 3D da placa do Controlador}
    
    \fonte{(O AUTOR, 2018)}
    \label{fig:controlador-top}
\end{figure}

\begin{figure}[H]
    \centering
    \caption{Visão inferior do modelo 3D da placa do Controlador}
    
    \fonte{(O AUTOR, 2018)}
    \label{fig:controlador-bottom}
\end{figure}

Assim como nos projetos anteriores, a placa do Controlador também foi projetada utilizando-se de técnicas para evitar a reflexão dos sinais, separação das alimentações dos circuitos de potência e utilização de conectores que impedem inversão de polaridade. Além disso, com exceção dos sensores e conectores, todos os componentes são de montagem em superfície (SMD), como apresentado na \autoref{fig:controlador-smd}.

\begin{figure}[H]
    \centering
    \caption{Visão inferior do modelo 3D da placa do Controlador - detalhe para os componentes SMDs}
    
    \fonte{(O AUTOR, 2018)}
    \label{fig:controlador-smd}
\end{figure}

%\section{PROJETO DO \emph{FIRMWARE}}
%\label{sec:firmware}

%\subsection{\emph{DEBOUNCE}}
%\label{subsec:debounce}

%\subsection{MÁQUINA DE ESTADOS FINITA}
%\label{subsec:fsm}

%\textcolor{red}{TODO: citar a referencia gang  of 4}

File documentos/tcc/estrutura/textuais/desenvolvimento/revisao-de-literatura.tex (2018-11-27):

% REVISÃO DE LITERATURA--------------------------------------------------------

\chapter{REVISÃO TEÓRICA}
\label{chap:fundamentacaoTeorica}

Este capítulo aborda alguns conceitos dos principais componentes e ferramentas utilizadas, bem como a especificação do projeto.

\section{PROJETO ARQUITETÔNICO}
\label{sec:matrizLed}

O projeto arquitetônico definiu a quantidade e a disposição de cada objeto. Ao todo, são 128 sensores e 129 pontos de luz, dispostos sob um tampo acrílico de {1 m} de diâmetro, conforme apresentado na \autoref{fig:tampo}.

\begin{figure}[H]
    \centering
    \caption{Disposição dos objetos na Mesa de Bolinhas}
    
    \fonte{(MITSUKO, 2016)}
    \label{fig:tampo}
\end{figure}

A arquiteta também especifica que o funcionamento da mesa deve ser orientado a eventos, provenientes das seções Controle e Matriz (\autoref{fig:mesa-sup}):

\begin{itemize}[noitemsep]
    \item A mesa sai do modo ocioso ao manter-se a mão sobre a bolinha \emph{Power} por mais de {1 s}: acende-se o seletor de cores e a mesa passa a interpretar os demais comandos;
    \item Escolhe-se uma cor ao manter-se a mão sobre uma determinada bolinha do seletor de cores por mais de {1 s};
    \item Ao passar a mão sobre uma determinada bolinha da seção Matriz, a mesma deve responder com a última cor escolhida;
    \item Uma bolinha da seção Matriz pode ser apagada se a ``cor'' escolhida tiver sido a da bolinha \emph{Power};
    \item Ao manter-se a mão por mais de {3 s} sobre a bolinha \emph{Power}, todas as bolinhas da seção Matriz devem ser apagadas; e
    \item Ao manter-se a mão por mais de {5 s} sobre a bolinha \emph{Power}, a mesa entra em modo ocioso: as bolinhas do seletor de cores são apagadas e a mesa passa a ignorar os comandos sobre a Matriz.
\end{itemize}

A partir da especificação acerca do funcionamento, notam-se alguns desafios do ponto de vista do eletrônico/lógico, tais como:

\begin{itemize}
    \item A disposição dos objetos e o tamanho da mesa;
    \item A capacidade de comandar individualmente 129 \emph{LEDs} coloridos (\emph{RGB}), ou seja $129 \times 3 = 387$ canais de cor;
    \item A capacidade de interpretar os níveis lógicos dos 128 sensores;
    \item A capacidade de responder, simultaneamente, aos comandos temporais provenientes de cada sensor.
\end{itemize}

A seleção dos componentes e das ferramentas foi baseada na especificação e nos desafios acima citados e será discutida a seguir nas demais seções deste capítulo.

\section{SENSOR}
\label{sec:sensor}

A função do sensor é identificar a posição de um objeto, no caso, a mão do espectador, sobre o tampo acrílico, e para manter-se centrado nos objetivos do projeto arquitetônico, a definição do tipo de sensor foi baseada em dois pontos essenciais:

\begin{enumerate}[label=\Roman*.]
    \item O elemento principal do projeto é a luz que flui da bolinha de \emph{ping-pong};
    \item A exposição pode ser levada a diversos lugares e ser instalada nos mais variados ambientes, como museus, escolas, saguões, etc.
\end{enumerate}

A questão (I) implica que o sensor não deve irradiar ondas eletromagnéticas dentro do espectro visível, que vai de {400 nm} a {700 nm} \cite{fundafisica}. Já a questão (II) implica que a instalação será submetida a locais com diferentes graus de iluminação, portanto os sensores devem ser imunes à variação luminosa do ambiente.

Assim sendo, optou-se pelo sensor óptico reflexivo \emph{TCRT5000L}, apresentado na \autoref{fig:sensor}, cujas características relevantes para o projeto são apresentadas na \autoref{tab:sensor}.

\begin{figure}[H]
    \centering
    \caption{Sensor TCRT5000}
    
    \fonte{\citeonline{datasheet-sensor}}
    \label{fig:sensor}
\end{figure}

\input{./dados/tabelas/sensor}

Trata-se de um sensor reflexivo infravermelho ($\lambda_{P}$), ou seja, opera fora do espectro visível, o que contorna a implicação da questão (I) apresentada anteriormente. Além disso, diferentemente de um sensor passivo, por exemplo um LDR, o TCRT5000 opera irradiando luz e, ademais, também contém filtro óptico embutido, absorvendo somente comprimentos de onda próximas a ($\lambda_{P}$). Essa duas características contornam a implicação da questão (II).

A saída transistorizada permite que o sensor seja interpretado de forma lógica. Sua aplicação (\autoref{fig:sensoraplicacao}) vai desde sensoriamento de \emph{encoders} e posições de ``fim de curso'' até detecção de papéis, cartões, fitas, etc. Foi escolhida a variante ``L'' (\emph{TCRT5000\textbf{L}}) por ser a versão com terminais estendidos.

\begin{figure}[H]
    \centering
    \caption{Aplicação do sensor TCRT5000}
    
    \fonte{\citeonline{datasheet-sensor}}
    \label{fig:sensoraplicacao}
\end{figure}

\section{REGISTRADORES DE DESLOCAMENTO}
\label{sec:registradores}

A necessidade de interpretar individualmente os 128 sensores implica na mesma quantidade de entradas do circuito de processamento. Então, optou-se por lidar com entradas virtuais, através de um barramento serial, por meio de registradores de deslocamento. Dessa forma, com poucas GPIOs, o microcontrolador pode interpretar os níveis lógicos de todos os sensores conectados ao barramento.

Devido sua grande difusão no mercado, o registrador de deslocamento escolhido foi o 74HC165. A \autoref{fig:shift-register} apresenta o diagrama funcional do circuito integrado.

\begin{figure}[H]
    \centering
    \caption{Diagrama funcional do 74HC165}
    
    \fonte{\citeonline{datasheet-shift-register}}
    \label{fig:shift-register}
\end{figure}

Trata-se de um registrador de deslocamento com 8 entradas em paralelo ($D_{N}$) e saídas complementares ($Q_{7}$ e $\overline{Q_{7}}$) em serial. Basicamente, seu funcionamento (\autoref{fig:shift-temporal}) constitui-se na captura instantânea do nível lógico de suas entradas (borda de descida da Entrada Assíncrona de Carga Paralela, $\overline{P_{L}}$) e na transmissão desses valores através de deslocamento ordenado ($D_{7} \rightarrow D_{0}$) na saída serial ($Q_{7}$), nos eventos de borda de subida na entrada de \emph{clock} ($C_{P}$).

\begin{figure}[!htb]
    \centering
    \caption{Diagrama temporal do 74HC165}
    
    \fonte{\citeonline{datasheet-shift-register}}
    \label{fig:shift-temporal}
\end{figure}

%\section{TECLADO ADC}
%\label{sec:tecladoAD}

\section{LED}
\label{sec:led}

Para formar a matriz de saída, optou-se pelo LED WS2812S (\autoref{fig:ws2812}), um dispositivo em encapsulamento SMD5050 com controlador interno, o WS2811: um \emph{driver} especial para LEDs, com 3 saídas de 8 \emph{bits} de resolução, ou seja, pode-se gerar até 16777216 cores do padrão RGB. Esse controlador é muito utilizado em fitas de LEDs endereçáveis (\autoref{fig:strip}), pois permite a conexão de vários controladores em um mesmo barramento serial (protocolo NRZ), podendo-se controlar cada LED individualmente.

O fato de possuir um controlador embutido no próprio encapsulamento implica diretamente sobre o valor do LED, custando um pouco mais que o dobro do valor médio de outros LEDs RGBs mais simples. Apesar disso, o custo acaba sendo compensado pelos benefícios que o \emph{driver} proporciona.

\begin{figure}[!htb]
    \centering
    \caption{Vista aproximada do LED WS2812 e seu controlador interno}
    
    \fonte{\citeonline{adafruit}}
    \label{fig:ws2812}
\end{figure}

O modelo do LED já havia sido selecionada durante o Programa de Iniciação Científica que o autor participou, já sendo utilizado no circuito da matriz. No projeto aqui proposto, eles serão utilizados no seletor de cores, discutido no \autoref{chap:metodologia}.

\begin{figure}[H]
    \centering
    \caption{Fita de LED endereçável utilizando o WS2812}
    
    \fonte{\citeonline{adafruit}}
    \label{fig:strip}
\end{figure}

\section{BAKER CLAMP}
\label{sec:backerclamp}

Segundo \citeonline{theartofelectronics}, os mesmos efeitos que limitam o desempenho de amplificadores lineares em altas frequências (a combinação de capacitância de junção, capacitância de retorno e capacitância parasita) também impõem limitações de velocidade em circuitos digitais de alta frequência. A \autoref{fig:tjb} apresenta um amplificador ``emissor comum'', que pode atuar como uma chave inversora quando operado em corte e saturação, alimentado por uma fonte de pulsos com tempos de subida e descida extremamente curtos, e a \autoref{fig:curvatjb} apresenta uma curva típica sobre a carga ($R_{C}$) desse tipo de amplificador ao considerar as componentes parasitas. 

\begin{figure}[H]
    \centering
    \caption{Representação de uma chave inversora com TJB}
    
    \fonte{\cite{theartofelectronics}}
    \label{fig:tjb}
\end{figure}

\begin{figure}[H]
    \centering
    \caption{Forma de onda da chave inversora com TJB}
    
    \fonte{\cite{theartofelectronics}}
    \label{fig:curvatjb}
\end{figure}

Nota-se que, assim que a fonte estabelece o pulso em nível baixo, o transistor leva um certo tempo ($t_r$) para sair da saturação e alcançar o estado de corte. Esse comportamento deriva-se do acúmulo de carga ($C_{cb}$) entre o coletor e a base. Dependendo das características físicas do transistor e da aplicação, esse tempo de subida pode vir a prejudicar o desempenho da finalidade do circuito, como é o caso do conversor de nível lógico elaborado para a Mesa de Bolinhas (discutido no \autoref{chap:metodologia}).

Para mitigar tal efeito, \citeonline{theartofelectronics} propõem a inclusão de um diodo de \emph{clamping} (também conhecido por  ``Baker \emph{clamp}''), entre a base e o coletor do TJB (\autoref{fig:bakerclamp}). Esse diodo irá desviar a corrente de base quando o transistor estiver se aproximando da saturação e evitará sua saturação, uma vez que a queda direta de tensão do diodo, no caso um diodo Schottky, é menor que a da junção coletor-base. Dessa forma, o TJB pode entrar em corte mais rapidamente, pois o mesmo não chega a entrar no ponto de saturação profunda.

\begin{figure}[H]
    \centering
    \caption{Chave inversora com o diodo de ``Baker \emph{clamping}''}
    
    \fonte{\cite{theartofelectronics}}
    \label{fig:bakerclamp}
\end{figure}

\section{MICROCONTROLADOR}
\label{sec:microcontrolador}

O ESP8266 é o microcontrolador de entrada para a família de 32 bits da fabricante chinesa Espressif Systems. Produzido em escala a partir de 2014, essa família ganhou espaço na área de Internet das Coisas por ser um microcontrolador de baixo custo, de baixo consumo e com suporte à rede 802.11 (\emph{Wi-Fi}). A \autoref{tab:espec-microcontrolador} apresenta as principais especificações do microcontrolador e a \autoref{fig:esp-funcional} apresenta seu diagrama funcional. Cabe aqui ressaltar que toda a parte de radio-frequência é implementada por \emph{hardware}, simplificando o desenvolvimento de aplicações com comunicação sem fio.

\input{./dados/tabelas/microcontrolador}

\begin{figure}[!htb]
    \centering
    \caption{Diagrama funcional do ESP8266}
    
    \fonte{\citeonline{datasheet-esp}}
    \label{fig:esp-funcional}
\end{figure}

Embora a comunicação sem fio não fizesse parte das especificações do projeto arquitetônico original, a equipe concordou com a possibilidade de implementá-la em uma aplicação futura. Esse foi o ponto decisivo para a escolha do ESP8266. Assim, a Mesa de Bolinhas poderá ganhar novas funcionalidades sem haver a necessidade de alteração no \emph{hardware}. Isso será discutido na \autoref{sec:trabalhosFuturos}.

Entre os diversos módulos que incluem o ESP8266, optou-se pelo ESP-12, por ser o que dispõe a maior quantidade de GPIOs (9 ao todo). A \autoref{fig:esp-12} apresenta sua placa. Convém salientar que este módulo já conta com memória \emph{Flash} (4\ MB) e antena \emph{microstrip}.

\begin{figure}[H]
    \centering
    \caption{Módulo ESP-12}
    
    \fonte{\cite{book-esp}}
    \label{fig:esp-12}
\end{figure}

Por serem compartilhados entre aplicações do usuário e funcionalidades internas, alguns pinos possuem certas particularidades. Os resistores  \emph{pull-up/pull-down} (\autoref{fig:esp-12}) garantem o nível lógico de alguns pinos, porém outros necessitam de uma atenção especial, sobretudo os que definem o modo de funcionamento: operação normal ou modo de gravação, que será discutido no \autoref{chap:metodologia}. A \autoref{tab:pinoutesp} apresenta a pinagem do módulo ESP-12 e também a função interna cada pino.

\input{./dados/tabelas/pinoutesp}

\section{\emph{FRAMEWORK}}
\label{sec:framework}

Sming é um \emph{framework} de código aberto, nativo para a família de microcontroladores ESP8266, desenvolvido na linguagem {C++} e com foco em alta eficiência em desempenho e em uso de memória.

Diferente de outros \emph{frameworks} baseados em laço-infinito, a estrutura do Sming é baseada em eventos temporais: as tarefas do usuário são escaladas em uma tabela de tempo. Isso o aproxima de uma das funcionalidades de um Sitema Operacional de Tempo Real, embora não haja, obviamente, um gerenciamento de recursos. Porém, o fato de poder-se escalar as tarefas em uma janela de tempo simplifica a implementação da especificação deste projeto, uma vez que, basicamente, sua funcionalidade também é baseada em eventos temporais, como apresentado no começo do capítulo (\autoref{sec:matrizLed}).

Por tratar-se de uma plataforma de código aberto, este \emph{framework} conta com uma vasta contribuição da comunidade, com uma API de \emph{hardware} robusta e diversas bibliotecas nativas, tais como \emph{bootloader}, sistema de arquivos (SPIFFS), atualização sem fio de \emph{firmware} (OTA) e uma extensa pilha assíncrona de rede (TCP, UDP, \emph{WebSockets}, etc). Esses recursos são úteis para a continuidade do projeto, discutida na \autoref{sec:trabalhosFuturos}.

%\section{FIFO}
%\label{sec:fifo}

%\textcolor{red}{TODO: revisão teórica FIFO}

\section{DEBOUNCE}
\label{sec:debounce}

Embora o funcionamento do sensor (\autoref{sec:sensor}) seja aparentemente simples - isto é, o transistor vai à saturação ao detectar um objeto; ou o transistor permanece em corte se não houver detecção - podem haver disparos falsos devido à oscilação do sinal durante a interação com a mesa. Essa oscilação é conhecida como \emph{bouncing}: trepidação do nível lógico durante a mudança de estado. A \autoref{fig:switch-bounce} apresenta um exemplo dessa oscilação, quando uma chave física passou do nível lógico alto para o baixo, ao ser pressionada.

\begin{figure}[H]
    \centering
    \caption{Oscilação do sinal de uma chave ao ser pressionada}
    
    \fonte{\citeonline{switch-debounce}}
    \label{fig:switch-bounce}
\end{figure}

Ainda que a Mesa de Bolinhas não conte com botões físicos, o efeito \emph{bouncing} pode vir a ocorrer em razão do limiar de detecção do sensor: o transistor de saída pode ficar operando, ainda que brevemente, no limite da interpretação do seu nível lógico. Para contornar tal situação, assim como nos casos de chaves físicas, será implementado um procedimento de \emph{debouncing}. \citeonline{debounceguide} cita diversas técnicas, desde descarte de tempo, filtros RC (resistor e capacitor), técnicas com \emph{latches} (\autoref{fig:srdebouncer}), entre outros, inclusive táticas via \emph{software}.

\begin{figure}[H]
    \centering
    \caption{Exemplo de circuito de \emph{debounce} com \emph{latches}}
    
    \fonte{\citeonline{debounceguide}}
    \label{fig:srdebouncer}
\end{figure}

No caso da Mesa de Bolinhas, não conviria implementar os modelos de  \emph{debouncing} por \emph{hardware}, pois implicaria diretamente no custo do projeto, não só pelo custo dos componentes, mas também pela área de placa ocupada, e também na complexidade do leiaute da PCI. Então, optou-se por implementar uma técnica de contorno via \emph{firmware}. Com isso, não há necessidade de adicionar componentes auxiliares ao circuito dos sensores e registradores de deslocamento. Trata-se de uma técnica baseada em ``histerese temporal'', onde a referência virtual altera-se de estado somente quando o nível de seu respectivo sensor já estiver estabilizado durante N milissegundos. A implementação dessa técnica será desenvolvida no \autoref{chap:metodologia}.

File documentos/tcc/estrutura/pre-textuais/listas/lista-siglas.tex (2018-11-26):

% LISTA DE ABREVIATURAS E SIGLAS----------------------------------------------------------
\begin{siglas}
    \item[ADC] do inglês \emph{Analog to Digital Converter}
    \item[API] do inglês \emph{Application Programming Interface}
    \item[CPU] do inglês \emph{Central Processing Unit}
    \item[FIFO] do inglês \emph{First In, First Out}
    \item[FSM] do inglês \emph{Finite-state Machine}
    \item[GPIO] do inglês \emph{General Purpose Input/Output}
    %\item[IC] Iniciação Científica
    %\item[IV] Radiação Infravermelha
    \item[LDR] do inglês \emph{Light Dependent Resistor}
    \item[LED] do inglês \emph{Light Emitting Diode}
    \item[MISO] do inglês \emph{Master Input Slave Output, or Master In Slave Out}
    \item[MOSI] do inglês \emph{Master Output Slave Input, or Master Out Slave In}
    \item[MuMa] Museu de Arte Municipal
    \item[NRZ] do inglês \emph{Non-return-to-zero}
    \item[OTA] do inglês \emph{Over-the-air}
    \item[PCI] Placa de Circuito Impresso
    \item[PIBIC] Programa Institucional de Bolsas de Iniciação Científica
    \item[PWM] do inglês \emph{Pulse Width Modulation}
    \item[RAM] do inglês \emph{Random Access Memory}
    \item[RGB] Sistema de cores aditivas, do inglês \emph{Red}, \emph{Green} e \emph{Blue}
    \item[SCLK] do inglês \emph{Serial Clock}
    \item[SMD] do inglês \emph{Surface Mounting Device}
    \item[SPIFFS] do inglês \emph{SPI Flash File System}
    \item[SS] do inglês \emph{Slave Select}
    \item[TCP] do inglês \emph{Transmission Control Protocol}
    \item[TJB] Transistor de Junção Bipolar
    %\item[TTL] do inglês \emph{Transistor-Transistor Logic}
    \item[UART] do inglês \emph{Universal Asynchronous Receiver-Transmitter}
    \item[UDP] do inglês \emph{User Datagram Protocol}
    \item[UFPR] Universidade Federal do Paraná
    \item[UNESCO] Organização das Nações Unidas para a Educação, a Ciência e a Cultura
    \item[USB] do inglês \emph{Universal Serial Bus}
\end{siglas}

% OBSERVAÇÕES-----------------------------------------------------------------------------
% Altere a lista acima para definir os acrônimos e siglas utilizados neste trabalho

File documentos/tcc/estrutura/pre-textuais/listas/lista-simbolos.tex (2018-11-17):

% LISTA DE SÍMBOLOS------------------------------------------------------------

\begin{simbolos}
    \item[$ \Omega $] Unidade de medida da resistência elétrica
    \item[$ \lambda $] Comprimento de onda
\end{simbolos}

% OBSERVAÇÕES-------------------------------------------------------------------
% Altere a lista acima para definir os símbolos utilizados no trabalho

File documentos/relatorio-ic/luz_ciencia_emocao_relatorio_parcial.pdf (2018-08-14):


MINISTERIO DA EDUCAÇ ´ | AÕ
UNIVERSIDADE FEDERAL DO PARANÁ
PRO-REITORIA DE PESQUISA E P ´ | OS-GRADUAÇ ´ | AÕ
COORDENADORIA DE INICIAÇ AO CIENT ˜ | ÍFICA E INTEGRAÇ AO ACAD ˜ | EMICA ˆ
PROGRAMA DE INICIAÇ AO CIENT ˜ | ÍFICA E EM DESENVOLVIMENTO
TECNOLOGICO E INOVAÇ ´ | AÕ

## Wendeurick Emerick Silverio

### RELATORIO PARCIAL ´

INICIAÇ AO CIENT ˜ | ÍFICA:
PIBIC CNPq ( ), PIBIC CNPq Açoes Afirmativas ( ), PIBIC UFPR TN ( ), PIBIC Fundaç ˜ | aõ
Araucaria ( ), PIBIC Volunt ´ | aria (x), PIBIC Aç ´ | oes Afirmativas Volunt ˜ | aria ( ) ou PIBIC EM. ´

01/08/2016 a 31/12/2016

## Desenvolvimento de Matriz de LED Interativa em Plataforma de Hardware Livre

Relatorio apresentado ´ | a Coordenadoria de `
Iniciaçao Cient ˜ | ífica e Integraçao Acad ˜ | emica ˆ
da Universidade Federal do Parana por ´
ocasiao da conclus ˜ | ao das atividades de ˜
Iniciaçao Cient ˜ | ífica - Edital 2016/2017.

Orientador: James Alexandre Baraniuk / Departamento de Engenharia Eletrica ´

Projeto de pesquisa: Luz, Ciencia e Emoç ˆ | ao: Exposiç ˜ | ao Interativa para Crianç as / ˜
2016019080
| CURITIBA
| 2017

## Sumario ´

1 RESUMO | 2
2 INTRODUÇ AO | 3 ˜
3 MATERIAIS E METODOS | 5 ´
4 CONCLUSOES/CONSIDERAÇ ˜ | OES FINAIS | 10 ˜
5 REFERENCIAS | 11 ˆ

## 1 RESUMO

Inspirada na proclamaçao do Ano Internacional da Luz pela Oganizaç ˜ | ao das Naç ˜ | oes ˜
Unidas, a exposiçao interativa “Luz, Ci ˜ | encia e Emoç ˆ | ao” prop ˜ | oe mais de vinte experimentos ˜
tendo a luz como tema principal. O seguinte trabalho apresenta o desenvolvimento de um desses experimentos.
Assim, o relatorio parcial aborda a elaboraç ´ | ao e a prototipagem do circuito da matriz de ˜
LED interativa chamada “Mesa de Bolinhas”, proposta pela arquiteta Dra. Maristela Mitsuko Ono.

## 2 INTRODUÇ AÕ

A luz exerce um papel essencial no nosso cotidiano e esta presente das mais diversas ´
formas: iluminaçao, medicina, pesquisas cient ˜ | íficas, geraçao de energia, telecomunicaç ˜ | | oes, ˜
educaçao, arte, cultura e etc. Em 2013, a Assembleia Geral das Naç ˜ | oes Unidas proclamou ˜
o ano de 2015 como o Ano Internacional da Luz e das Tecnologias Baseadas na Luz [1],
a fim de reconhecer tal importancia para a vida dos cidad ˆ | aos e para o desenvolvimento ˜
futuro da sociedade mundial. No ano da celebraçao, a UNESCO promoveu uma s ˜ | erie de ´
eventos por varios pa ´ | íses [2], com o intuito de destacar que o aumento da consciencia ˆ
mundial e o fortalecimento do ensino da ciencia e das tecnologias da luz s ˆ | ao essenciais para ˜
abordar os desafios futuros e atuais, tais como o desenvolvimento sustentavel, a energia ´
e as comunicaçoes, assim como para melhorar a qualidade de vida dos pa ˜ | | | íses menos
desenvolvidos e dos em desenvolvimento.
Baseada em tal iniciativa, a exposiçao “Luz, Ci ˜ | encia e Emoç ˆ | ao” traz experimentos envol- ˜
vendo os conceitos de luz trabalhados nos ensinos pre-escolar e fundamental, cada um com ´
seu grau de impressao aos sentidos. A exposiç ˜ | ao proporciona uma experi ˜ | encia tang ˆ | ível-
visual impactante aos observadores, causando deslumbramento e entusiasmo atraves da ´ arte e interaçao. ˜
Um dos experimentos que forma parte da area art ´ | ística da exposiçaõ e a “Mesa de ´
Bolinhas”, uma matriz de LED (Diodo Emissor de Luz, sigla em ingle) interativa, elaborada ˆ
pela arquiteta Dra. Maristela Mitsuko Ono. A mesa, de 1m de diametro, ˆ | e composta por mais ´
de 100 bolinhas de ping-pong, cada uma correspondente a um par LED-sensor reflexivo. Ela permite que o visitante “pinte com luz” ao passar a mao sobre a mesa. A vista superior ˜ do projeto e apresentada na Figura 1. ´

Figura 1: Vista superior da mesa


Fonte: (MITSUKO, 2016)

Partindo do pressuposto que a instalaçao pode ser montada em outras exposiç ˜ | oes e ˜
que serao fornecidos materiais de apoio, tanto aos professores quanto aos alunos, de modo ˜ que possam realizar experimentos similares em suas escolas, foi optado por escrever seu firmware na linguagem de programaçaõ Wiring (Arduino) [3], plataforma aberta criada para
abstrair as complicaçoes da eletr ˜ | onica embarcada a fim de expandir a computaç ˆ | ao f ˜ | ísica
para as areas al ´ | em da engenharia, permitindo, assim, que pessoas de ´ | areas n ´ | ao-t ˜ | ecnicas ´
possam focar em seus objetivos [4].

## 3 MATERIAIS E METODOS ´

A primeira etapa foi testar o conceito de mapeamento, tanto do LED quanto do sensor reflexivo. Para este, utilizou-se o sensor TCRT5000 - par LED infravermelho e fototransistor -em conjunto com o registrador de deslocamento 74HC165 (protocolo SPI - Serial Peripheral Interface), e para aquele, o LED WS2812 - LED RGB (8 bits por cor) endereçavel (protocolo ´ NRZ - non return to zero). A Figura 2 apresenta o prototipo deste conceito, montado em ´ placa perfurada, com 6 pares LED-sensor reflexivo.

Figura 2: Primeiro prototipo - teste do conceito ´


Fonte: (O AUTOR, 2016)

Validado o conceito do mapeamento, elaborou-se a distribuiçao dos circuitos. Optou-se ˜
por faze-lo de forma modular: os 118 sensores reflexivos da seç ˆ | ao matriz foram separados ˜
em 17 colunas verticais em blocos de 2 e 3, cada uma a ser controlada por um registrador de deslocamento de 8 bits. A Figura 3 apresenta as 4 combinaçoes utilizadas, separadas ˜ por cor, descritas na lista a seguir. Essas configuraçoes s ˜ ao importantes pois definem a ˜ quantidade de bits a serem usados pelo registrador de deslocamento referente a tal coluna.
- Configuraçao “3/2” (verde): 1 bloco de 3 pares, 1 bloco de 2 pares ˜

– bloco “3”: bits{0, 1, 2}
– bloco “2”: bits{3, 4}
- Configuraçao “3/3” (amarela): 2 blocos de 3 pares ˜

– bloco “3”: bits{0, 1, 2}
– bloco “3”: bits{3, 4, 5}

- Configuraçao “3/2/2” (azul): 1 bloco de 3 pares, 2 blocos de 2 pares ˜

– bloco “3”: bits{0, 1, 2}

– bloco “2”: bits{3, 4}

– bloco “2”: bits{5, 6}

- Configuraçao “3/3/2” (violeta): 2 blocos de 3 pares, 1 bloco de 2 pares ˜

– bloco “3”: bits{0, 1, 2}

– bloco “3”: bits{3, 4, 5}

– bloco “2”: bits{6, 7}

Figura 3: Agrupamento dos blocos


Fonte: Adaptado (MITSUKO, 2016)


De maneira artesanal, foram feitas placas de circuito impresso para testar esse conceito modular. As Figuras 4, 5 e 6 apresentam os prototipos. ´

Figura 4: Prototipo dos blocos ´

Fonte: (O AUTOR, 2017)

Figura 5: Teste dos blocos

Fonte: (O AUTOR, 2017)


Figura 6: Conexao entre os blocos ˜

Fonte: (O AUTOR, 2017)

Atraves de ´ jumpers seletores, elege-se a configuraçao descrita na lista anterior. As- ˜ sim, o sinal do sensor pode ser direcionado a entrada do bit desejado no registrador de ` deslocamento.

Figura 7: Jumpers seletores

Fonte: (O AUTOR, 2017)


Validados esses conceitos, o projeto foi enviado a uma empresa de confecçao de placas ˜ de circuito impresso. Ao todo, sao 23 placas de 2 pares e 24 de 3 pares. As Figuras 8 e 9 ˜ apresentam as placas confeccionadas pela empresa.

Figura 8: Duas faces da placa de 2 pares

Fonte: (O AUTOR, 2017)

Figura 9: Duas faces da placa de 3 pares

Fonte: (O AUTOR, 2017)

4 CONCLUSOES/CONSIDERAÇ ˜ | OES FINAIS ˜

Os conceitos da seçao matriz foram validados e suas placas foram produzidas. As ˜
proximas etapas s ´ | ao a montagem dos componentes dessas placas, a elaboraç ˜ | ao e monta- ˜
gem do circuito da seçao controle e o ˜ | firmware do projeto.

## 5 REFERENCIAS ˆ

## Referencias ˆ

[1] United Nations. 68/221. International Year of Light and Light-based Technologies, 2015.
2014. URL: http://www.light2015.org/dam/About/Resources/Resolution/
Resolution_EN.pdf (acesso em 18/02/2017).
[2] UNESCO. International Year of Light. 2015. URL: http://www.light2015.org/
Home/Event-Programme.html (acesso em 18/02/2017).
[3] Arduino. URL: https://www.arduino.cc/ (acesso em 18/02/2017).
[4] Hernando Barragan. “Wiring: Prototyping Physical Interaction Design”. Diss. de mes- ´ trado. Interaction Design Institute Ivrea, jun. de 2004.

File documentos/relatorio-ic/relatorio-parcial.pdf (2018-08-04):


MINISTERIO DA EDUCAC¸ ´ | AO˜
UNIVERSIDADE FEDERAL DO PARANA´
PRO-REITORIA DE PESQUISA E P ´ | OS-GRADUAC¸ ´ | AO˜
COORDENADORIA DE INICIAC¸ AO CIENT ˜ | ´IFICA E INTEGRAC¸ AO ACAD ˜ | EMICA ˆ
PROGRAMA DE INICIAC¸ AO CIENT ˜ | ´IFICA E EM DESENVOLVIMENTO
TECNOLOGICO E INOVAC¸ ´ | AO˜

## Wendeurick Emerick Silverio

### RELATORIO PARCIAL ´

INICIAC¸ AO CIENT ˜ | ´IFICA:
PIBIC CNPq ( ), PIBIC CNPq Ac¸oes Afirmativas ( ), PIBIC UFPR TN ( ), PIBIC Fundac¸ ˜ | ao˜
Araucaria (x), PIBIC Volunt ´ | aria ( ), PIBIC Ac¸ ´ | oes Afirmativas Volunt ˜ | aria ( ) ou PIBIC EM. ´

01/01/2017 a 31/07/2017

## Desenvolvimento de Matriz de LED Interativa em Plataforma de Hardware Livre

Relatorio apresentado ´ | a Coordenado- `
| | ria de Iniciac¸ao Cient ˜ | ´ıfica e Integrac¸ao˜

### Academica da Universidade Federal ˆ

do Parana por ocasi ´ | ao da conclus ˜ | ao˜
das atividades de Iniciac¸ao Cient ˜ | ´ıfica
- Edital 2016/2017.

Orientador: James Alexandre Baraniuk / Departamento de Engenharia Eletrica ´

Projeto de pesquisa: Luz, Ciencia e Emoc¸ ˆ | ao: Exposic¸ ˜ | ao Interativa para Crianc¸ as / ˜
2016019080
| CURITIBA
| 2017

## Sumario ´

1 RESUMO | 2
2 INTRODUC¸ AO | 3 ˜
3 REVISAO DA LITERATURA | 4 ˜
4 MATERIAIS E METODOS | 5 ´
5 REFERENCIAS | 6 ˆ

## 1 RESUMO

O seguinte trabalho apresenta o desenvolvimento de um dos vinte experimentos que
possuem a luz como tema principal, reunidos na exposic¸ao interativa ”Luz, Ci ˜ | encia e Emoc¸ ˆ | ao”, ˜
no Museu Municipal de Arte (MuMA), em Curitiba, Parana. O projeto engloba a elaborac¸ ´ | | ao˜
do circuito e software embarcado de uma matriz de LED interativa, chamada ”Mesa de Bolinhas”.

## 2 INTRODUC¸ AO˜

## 3 REVISAO DA LITERATURA ˜

## 4 MATERIAIS E METODOS ´

## 5 REFERENCIAS ˆ

## Referencias ˆ

[1] Shahin Farahani. ZigBee Wireless Networks and Transceivers. Corporate Drive, Suite 400, Burlington: Newnes, 2008. ISBN: 978-0-7506-8393-7.
[2] LAN/MAN Standards Committee. IEEE Std 802.11-2012 (Revision of IEEE Std 802.11-2007). Part 11: Wireless LAN Medium Access Control (MAC) and Physical Layer (PHY) Specifications. IEEE Computer Society. 3 Park Avenue New York, NY 10016-5997, mar. de 2012.
[3] Stefania Sesia. LTE – The UMTS Long Term Evolution. The Atrium Southern Gate Chichester, West Sussex: Wiley, 2011. ISBN: 9780470660256.
[4] Favero Santos, Bernardo Leite e Andre Mariano. “2.4 GHz CMOS Digitally Programmable Power Amplifier for Power Back-off Operation”. Em: (fev. de 2016). LASCAS2016, Florianopolis-SC, Brasil. ´
[5] Edson Leonardo Dos Santos. “Amplificador De Potencia CMOS De Baixo Consumo ˆ
Com Controle De Ganho”. Programa de pos-graduac¸ ´ | ao em engenharia el ˜ | etrica. Diss. ´
de mestrado. UFPR, jul. de 2015.
[6] Patrick Reynaert. RF Power Amplifiers For Mobile Communications. Netherlands: Springer, 2006. ISBN: 1-4020-5116-6.
[7] Steve C. Cripps. RF Power Amplifiers for Wireless Communications. 685 Canton Street: Artech House, 1999. ISBN: 1-59693-018-7.

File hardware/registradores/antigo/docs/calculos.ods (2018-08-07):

 | Index | Qtde
Arduino 1 | 0 | 5 | Total pinos | 67 | Corrente Opto | 0.0605
 | 1 | 6 | Total Optos | 63
 | 2 | 7
 | 3 | 7 | Corrente Optos | 3.8115
 | 4 | 8 | Corrente LED 5mm | 0.01
 | 5 | 7
 | 6 | 8
 | 7 | 7
 | 8 | 8
 | Serial | 2 | Total Corrente | 3.8215
 | LED DBG | 1
 | BOT DBG | 1
Arduino 2 | 9 | 7 | Total pinos | 70
 | 10 | 8 | Total Optos | 65
 | 11 | 7
 | 12 | 8 | Corrente Optos | 3.9325
 | 13 | 7 | Corrente LED 5mm | 0.01
 | 14 | 7
 | 15 | 6
 | 16 | 5
 | Controle | 10
 | Serial | 2 | Total Corrente | 3.9425
 | WS2812 | 1
 | LED DBG | 1
 | BOT DBG | 1

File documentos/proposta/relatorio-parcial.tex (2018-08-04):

\documentclass[a4paper,12pt]{article}
\usepackage[utf8]{inputenc}
\usepackage[brazil]{babel}
\usepackage[margin = 2cm]{geometry}
\usepackage{amsmath}
\usepackage{graphicx}
\usepackage{subfigure}
\usepackage{listings}
\usepackage{amssymb}
\usepackage{array}
\usepackage{indentfirst}
\usepackage{textcomp}
\usepackage{pdfpages}
\usepackage[backend=biber, sorting=none]{biblatex}
\usepackage{helvet}
\usepackage{palatino}
%\usepackage[table,xcdraw]{xcolor}

\usepackage{caption}
% \usepackage{floatrow}
\usepackage[capposition=top]{floatrow}

% aspas
\usepackage{csquotes}
\MakeOuterQuote{"}

\renewcommand{\familydefault}{\sfdefault}

\bibliography{bibliografia.bib}

%aspell --lang=pt_BR --master=pt_BR --mode=tex -c relatorio-parcial.tex

\begin{document}

  \begin{titlepage}
    \begin{center}
    \begin{minipage}[t]{0.74\textwidth}
    \vspace{0pt}
    \begin{center}
     UNIVERSIDADE FEDERAL DO PARANÁ \\
     SETOR DE TECNOLOGIA \\
     DEPARTAMENTO DE ENGENHARIA ELÉTRICA
    \end{center}
    \end{minipage}\\[1.5cm]

    {{WENDEURICK EMERICK SILVERIO\\GRR20134722}}\\[3cm]

    {\Large{Proposta do Projeto de Graduação}}\\[1cm]
    {\Large \textbf{Desenvolvimento de Mesa de Luz Interativa para Experimento de Ciências para Crianças}}\\[2.5cm]

      \hspace{.45\textwidth} %posiciona a minipage
       \begin{minipage}{.5\textwidth}
       Plano do Trabalho de Conclusão de Curso, apresentado como requisito parcial para a obtenção do grau de Engenheiro Eletricista, no programa de graduação em Engenharia Elétrica (ênfase em Eletrônica e Telecomunicações) da Universidade Federal do Paraná.\\
       \\
       Orientador: Prof. Dr. James Alexandre Baraniuk
       
      \end{minipage}
      \\[6.5cm]

      {\textbf{CURITIBA}}\\
      {2018}

    \end{center}
  \end{titlepage}

  \tableofcontents

  \clearpage
  \section{Contextualização e Resumo}
  
  A luz exerce um papel essencial no nosso cotidiano e está presente das mais diversas formas: iluminação, medicina, pesquisas científicas, geração de energia, telecomunicações, educação, arte, cultura e etc. A Assembleia Geral das Nações Unidas proclamou o ano de 2015 como o Ano Internacional da Luz e das Tecnologias Baseadas na Luz \cite{resolucao-onu}, a fim de reconhecer tal importância para a vida dos cidadãos e para o desenvolvimento futuro da sociedade mundial. No ano da celebração, a UNESCO promoveu uma série de eventos por vários países \cite{eventos-unesco}, com o intuito de destacar que o aumento da consciência mundial e o fortalecimento do ensino da ciência e das tecnologias da luz são essenciais para abordar os desafios futuros e atuais, tais como o desenvolvimento sustentável, a energia e as comunicações, assim como para melhorar a qualidade de vida dos países menos desenvolvidos e dos em desenvolvimento.
  
  Baseada em tal iniciativa, a exposição "Luz, Ciência e Emoção", idealizada pela arquiteta Dra. Maristela Mitsuko Ono e pelo engenheiro Dr. James Alexandre Baraniuk, traz experimentos envolvendo os conceitos de luz trabalhados nos ensinos pré-escolar e fundamental, cada um com seu grau de impressão aos sentidos. A exposição proporciona uma experiência tangível-visual impactante aos observadores, causando deslumbramento e entusiasmo através da arte e interação.
  
  O trabalho aqui proposto trata-se do desenvolvimento do \emph{hardware} e \emph{firmware} embarcado de um dos mais de 20 experimentos dessa exposição. A \textbf{Mesa de Bolinhas}, que se enquadra na área artística da mostra, é uma matriz de \emph{LEDs} interativa, elaborada pela arquiteta Dra. Maristela Mitsuko Ono, composta por mais de 100 bolinhas de ping-pong, cada uma correspondente a um par LED-sensor reflexivo. Ela permite que o visitante "pinte com luz" ao passar a mão sobre a mesa. Sua vista superior do projeto é apresentada na Figura \ref{fig:mesa-sup}.
  	
  \begin{figure}[H]
    \caption{Vista superior da mesa}
    \label{fig:mesa-sup}
    \centering
    
    \floatfoot{Fonte: (MITSUKO, 2016)}
  \end{figure}	

  \clearpage
  
  \section{Proposta de Trabalho}
  
  \subsection{Título}
  
  \emph{Desenvolvimento de Mesa de Luz Interativa para Experimento de Ciências para Crianças}.
  
  \subsection{Objetivos}
  \subsubsection{Objetivo Geral}
  
  Desenvolver o \emph{hardware} e o \emph{firmware} embarcado da "Mesa de Bolinhas", apresentando o protótipo funcional do projeto. Serão 128 LEDs programáveis, controlados por seus respectivos sensores de presença.
  
  \subsubsection{Objetivos Específicos}
  \begin{itemize}
      \item Desenvolvimento de uma matriz mapeável, onde cada \emph{LED} possa ser controlado individualmente;
      \item Desenvolvimento de uma matriz de entrada, onde cada sensor reflexivo possa ser lido individualmente;
      \item \emph{Software} microcontrolado que gerencie a interface humano-máquina;
      \item Leiaute e montagem das Placas de Circuito Impresso (PCI);
      \item Integração da eletrônica com a mecânica do projeto.
  \end{itemize}
  
  \subsection{Público Alvo}
  A serventia do projeto é destinada ao mesmo público alvo da exposição: crianças e adolescentes dos ensinos fundamental e médio. Além disso, o projeto pode ser de interesse de designers e artistas, uma vez que abrange áreas de tecnologia, interação e arte generativa.
  
  \subsection{Diferencial do Projeto}
  Além de ser uma matriz interativa autônoma, a Mesa de Bolinhas terá uma interface que possibilitará o controle através de outros dispositivos (computador, por exemplo). Isso possibilitará a integração com programas de \emph{led-mapping} e geradores de visuais.
  
  Tratando-se de uma proposta inovadora, pretende-se solicitar a patente do projeto.
  
  \subsection{Metodologia de desenvolvimento do estudo}
  A metodologia se dará por meio de protótipos, servindo de prova de conceito. Logo após, passa-se à implementação e execução do projeto.
  
\subsection{Recursos necessários}

Os materiais (mesa, tampa acrílica e demais partes mecânicas) já foram adquiridos pelo curso de Engenharia Elétrica, através do prof. James Baraniuk, e estão no Laboratório de Eficiência Energética. O projeto encontra-se sem o dispositivo eletrônico, cuja proposta deste trabalho é de desenvolvê-lo e integrá-lo à parte mecânica. Para isso, serão necessários:

\begin{itemize}
    \item \emph{Software CAD} para o leiaute das placas;
    \item Material para fabricação dos protótipos (PCIs, LEDs programáveis (WS2812) e demais componentes eletrônicos);
    \item Plataforma de desenvolvimento (microcontrolador da família ESP8266);
\end{itemize}

\subsection{Resultados fundamentais a serem atingidos}
Protótipo funcional da Mesa de Bolinhas, montagem das PCIs e integração com a mecânica do projeto.

\subsection{Contribuição esperada para a ênfase}
A nível geral, o projeto contribui no quesito integração com a área artística e de design. A nível técnico, o projeto trará recursos/implementações de mapeamento de \emph{pixels}, sistema de \emph{debouncing} para vários sensores, implementação de \emph{software} desenvolvido em topologia de Máquina de Estados Finita e etc.

\subsection{Cronograma a ser seguido indicando os marcos para avaliação, seguindo o cronograma divulgado pela Comissão Permanente do TCC}

\begin{table}[H]
\begin{tabular}{|l|c|c|c|c|}
\hline
\textbf{Atividade/Mês}        & \textbf{Agosto} & \textbf{Setembo} & \textbf{Outubro} & \textbf{Novembro} \\ \hline
\textbf{Atividade 1}          & X               & X                &                  &                   \\ \hline
\textbf{1ª Avaliação}         &                 & X                &                  &                   \\ \hline
\textbf{Atividade 2}          &                 & X                & X                &                   \\ \hline
\textbf{Banca}                &                 &                  & X                &                   \\ \hline
\textbf{Atividade 3}          &                 &                  & X                & X                 \\ \hline
\textbf{Entrega do Relatório} &                 &                  &                  & X                 \\ \hline
\textbf{Apresentação Final}   &                 &                  &                  & X                 \\ \hline
\end{tabular}
\end{table}

\begin{itemize}
    \item Atividade 1: desenvolvimento da seção "Matriz" 
    \item Atividade 2: desenvolvimento da seção "Controle"
    \item Atividade 3: finalização e integração com a mecânica
\end{itemize}

\subsection{Importância do Projeto para a formação dos autores}
Para o aluno, o conhecimento aqui adquirido é de fundamental importância para sua formação e interdisciplinaridade, uma vez que abrange resolução de problemas no campo da engenharia eletrônica / sistemas embarcados e o intercâmbio com outras áreas.

Para os idealizadores, o projeto passará a ser parte da exposição "Luz, Ciência e Emoção", proporcionando uma experiência tangível-visual impactante aos observadores, causando deslumbramento e entusiasmo através da arte e interação, não só das crianças e adolescente, mas também de pessoas que se interessem pela integração entre tecnologia, arte e design.

\subsection{Bibliografia a ser utilizada}

\begin{itemize}
    \item GAMMA, Erich et al. \textbf{Design Patterns}: Elements of Reusable Object-Oriented Software. 10. ed. Mountain View: Addison-Wesley Professional, 1994. 416 p.
    
    \item WAGNER, Ferdinand et al. \textbf{Modeling Software with Finite State Machines}. 1. ed. Boston: Auerbach Publications, 2006. 390 p.
\end{itemize}

 \clearpage

  \clearpage
  \section{Referências}
  \printbibliography

\end{document}

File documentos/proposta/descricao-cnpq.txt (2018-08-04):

James Alexandre Baraniuk
COORDENADOR(A)
OUTRA
Divulgação Científica

Título do Projeto:luz, ciência e emoção: exposição interativa para crianças

Resumo: De modo a comemorar o ano internacional da luz, o presente projeto propõe o desenvolvimento e a montagem de uma exposição interativa com experimentos de luzes, a ser visitada por estudantes na faixa etária de 4 a 10 anos de idade. Serão desenvolvidos 4 conjuntos de experimentos voltados à faixa etária de 4 a 6 anos de idade, 4 experimentos para a faixa de 7 a 10 anos de idade e 2 experimentos que contemplem as duas faixas etárias. A exposição será composta por experimentos interativos que causem deslumbramento e entusiasmo, que envolvam conceitos de luz trabalhados no ensino pré-escolar e fundamental, tendo todo o cuidado nos aspectos de segurança, de modo a não oferecerem riscos às crianças. Os conceitos a serem trabalhados na exposição envolvem os principais temas encontrados nos livros de ciências destinados a esta faixa etária: fontes de luz; propagação da luz, características da luz, reflexão da luz, características dos materiais e olho humano. A exposição será concebida para o recebimento de visitas de grupos de crianças provenientes de escolas do município, que serão acompanhadas por monitores que explicarão os princípios e curiosidades relacionados a cada experimento, sendo estimado um tempo de visita de 2 horas para cada grupo. Optamos pela realização de um pequeno número de experimentos de modo a explorar por mais tempo e com maior interação cada tema. Para o projeto da exposição serão considerados os pressupostos de que a mesma possa ser desmontada e montada em outros municípios, que seja oferecido material de apoio em texto e em vídeo, tanto para o professor quanto para os estudantes, de modo que possam realizar experimentos similares em suas escolas. Estes materiais de apoio serão disponibilizados em portal de recursos educacionais abertos (REA, 2015). A exposição será montada em sala de evento a ser selecionada, da própria UFPR ou da Prefeitura Municipal, em local que permita o fácil acesso e o estacionamento de ônibus com as crianças visitantes, devendo permanecer aberta por um período mínimo de 4 meses, podendo ser ampliado. A atividade de monitoria será realizada por meio de monitores bolsistas do curso de graduação de Engenharia Elétrica e por monitores bolsistas de colégios de ensino médio do município. Os professores participantes do projeto possuem vasta experiência em projetos de integração entre a universidade e escolas, domínio em eletrônica para o desenvolvimento de protótipos interativos, contando também com uma profissional da área de design para auxiliar na elaboração das atividades. Acreditamos que a realização desta exposição despertará o interesse de visita por várias escolas do município, podendo, ao final de uma temporada, ser remontada em outro município que tenha interesse em realizar o evento. 

Integrantes: James Alexandre Baraniuk - Coordenador / Maristela Mitsuko Ono - Integrante / Ivan Eidt Colling - Integrante / Ewaldo Luiz de Mattos Mehl - Integrante.

Financiador(es): Conselho Nacional de Desenvolvimento Científico e Tecnológico - Auxílio financeiro.

Instituição/UF/País: Universidade Federal do Paraná - PR - Brasil
Vigência: 12/12/2015-31/12/2017

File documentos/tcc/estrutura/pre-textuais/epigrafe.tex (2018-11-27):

% EPÍGRAFE---------------------------------------------------------------------

\renewcommand{\epigraphname}{EPÍGRAFE}

\begin{epigrafe}

\textit{Gosto que tudo seja real e que tudo esteja certo;\\
E gosto porque assim seria, mesmo que eu não gostasse.\\
Por isso, se morrer agora, morro contente,\\
Porque tudo é real e tudo está certo.\\
(CAEIRO, Alberto (Fernando Pessoa), 1915).}

\end{epigrafe}

% OBSERVAÇÕES------------------------------------------------------------------
% Altere o texto para inserir a epígrafe do seu trabalho

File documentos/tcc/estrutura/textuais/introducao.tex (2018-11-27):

% INTRODUÇÃO-------------------------------------------------------------------

\chapter{INTRODUÇÃO}
\label{chap:introducao}

  A luz exerce um papel essencial no nosso cotidiano e está presente das mais diversas formas: iluminação, medicina, pesquisas científicas, geração de energia, telecomunicações, educação, arte, cultura, etc. A Assembleia Geral das Nações Unidas proclamou o ano de 2015 como o Ano Internacional da Luz e das Tecnologias Baseadas na Luz \cite{resolucao-onu}, a fim de reconhecer tal importância para a vida dos cidadãos e para o desenvolvimento futuro da sociedade mundial. No ano da celebração, a UNESCO promoveu uma série de eventos por vários países \citeonline{eventos-unesco}, com o intuito de destacar que o aumento da consciência mundial e o fortalecimento do ensino da ciência e das tecnologias da luz são essenciais para abordar os desafios futuros e atuais, tais como o desenvolvimento sustentável, a energia e as comunicações, assim como para melhorar a qualidade de vida dos países menos desenvolvidos e dos em desenvolvimento.
  
  Baseada em tal iniciativa, a exposição Luz, Ciência e Emoção, idealizada pela arquiteta Dra. Maristela Mitsuko Ono e pelo engenheiro Dr. James Alexandre Baraniuk, traz experimentos envolvendo os conceitos de luz trabalhados nos ensinos pré-escolar e fundamental, cada um com seu grau de impressão aos sentidos. A (\autoref{fig:expo}) apresenta uma parte da mostra que ocorreu entre março e junho de 2017, no Museu de Arte Municipal, em Curitiba.
  
  \begin{figure}[H]%[!htb]
    \centering
    \caption{Parte da exposição ``Luz, Ciência e Emoção'', no MuMa}
    
    \fonte{(UFPR, 2017)}
    \label{fig:expo}
\end{figure}
  
  Dentre outros projetos que participou durante o Programa de Iniciação Científica \footnote{Projeto de Pesquisa: Luz, Ciência e Emoção: Exposição Interativa para Crianças (PIBIC Voluntária: 2016019080)}, o autor trabalhou na seção Matriz da Mesa de Bolinhas (\autoref{fig:mesa-sup}), projeto este que ocupará uma posição de destaque dentro da área artística da mostra. Trata-se de uma matriz de \emph{LEDs} interativa, composta por mais de 100 bolinhas de \emph{ping-pong}, cada uma sobre um correspondente par \emph{LED}-sensor reflexivo. Ela permite que o espectador ``pinte com luz'' ao passar a mão sobre a mesa, proporcionando uma experiência tangível-visual impactante, causando deslumbramento e entusiasmo através da arte e interação.
  
  O trabalho aqui proposto trata do desenvolvimento do \emph{hardware} e \emph{firmware} embarcado da seção Controle da mesa. Tal setor é responsável pela identificação e tratamento dos sinais de entrada e pelo acionamento da matriz de saída.

\begin{figure}[H]%[!htb]
    \centering
    \caption{Vista superior da mesa de Bolinhas}
    
    \fonte{(MITSUKO, 2016)}
    \label{fig:mesa-sup}
\end{figure}

\section{JUSTIFICATIVA}
\label{sec:justificativa}

  Sendo parte da exposição Luz, Ciência e Emoção, espera-se que o projeto fomente o envolvimento com a arte generativa e com as tecnologias envolvendo luz. Além de poder ser prestigiado durante a mostra, trata-se também de um projeto de código e \emph{hardware} abertos, que serão disponibilizados à comunidade para que possam ser estudados e adaptados às suas necessidades.

  Ademais, temas pouco explorados durante a graduação serão implementados, tais como técnica de contorno (\emph{debounce}, identificação de comandos reais sob contextos com ruído), padrão de \emph{design} em \emph{software} (FSM, máquina de estados finita) e geração de múltiplos canais de PWM.

\section{OBJETIVOS}
\label{sec:objetivos}

\subsection{OBJETIVO GERAL}
Finalizar o \emph{hardware} (seção Controle) e desenvolver o \emph{firmware} embarcado da Mesa de Bolinhas, apresentando um protótipo funcional do projeto.

\subsubsection{OBJETIVOS ESPECÍFICOS}
  \begin{itemize}
      \item Mapeamento da matriz de saída, onde cada \emph{LED} possa ser controlado individualmente;
      \item Mapeamento da matriz de entrada, onde cada sensor possa ser lido individualmente;
      \item \emph{Software} microcontrolado que gerencie a interface humano-máquina;
      \item Leiaute e montagem das Placas de Circuito Impresso;
      \item Integração da eletrônica com a mecânica do projeto.
  \end{itemize}

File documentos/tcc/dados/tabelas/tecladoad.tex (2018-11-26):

\begin{table}[H]
    \centering
    \caption[Valores de tensão e unidades do teclado analógico]{Valores de tensão e unidades do teclado analógico.
    \label{tab:tecladoad}}
\begin{tabular}{|c|c|c|}
\hline
\textbf{Chave} & \textbf{Tensão (V)} & \textbf{Valor ADC} \\ \hline
\textbf{S3} & 0,94 & 960 \\ \hline
\textbf{S4} & 0,54 & 551 \\ \hline
\textbf{S5} & 0,37 & 379 \\ \hline
\textbf{S6} & 0,27 & 279 \\ \hline
\end{tabular}
    \fonte{(O AUTOR, 2018)}
\end{table}

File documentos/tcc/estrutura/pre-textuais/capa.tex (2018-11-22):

% CAPA---------------------------------------------------------------------------------------------------

% ORIENTAÇÕES GERAIS-------------------------------------------------------------------------------------
% Caso algum dos campos não se aplique ao seu trabalho, como por exemplo,
% se não houve coorientador, apenas deixe vazio.
% Exemplos: 
% \coorientador{}
% \departamento{}

% DADOS DO TRABALHO--------------------------------------------------------------------------------------
\titulo{Desenvolvimento de Mesa de Luz Interativa para Experimento de Ciências para Crianças}
\titleabstract{Title in English}
\autor{Wendeurick Emerick Silverio}
\autorcitacao{SILVERIO, Wendeurick} % Sobrenome em maiúsculo
\local{Curitiba}
\data{2018}

% NATUREZA DO TRABALHO-----------------------------------------------------------------------------------
% Opções: 
% - Trabalho de Conclusão de Curso (se for Graduação)
% - Dissertação (se for Mestrado)
% - Tese (se for Doutorado)
% - Projeto de Qualificação (se for Mestrado ou Doutorado)
\projeto{Trabalho de Conclusão de Curso}

% TÍTULO ACADÊMICO---------------------------------------------------------------------------------------
% Opções:
% - Bacharel ou Tecnólogo (Se a natureza for Trabalho de Conclusão de Curso)
% - Mestre (Se a natureza for Dissertação)
% - Doutor (Se a natureza for Tese)
% - Mestre ou Doutor (Se a natureza for Projeto de Qualificação)
\tituloAcademico{Engenheiro Eletricista}

% ÁREA DE CONCENTRAÇÃO E LINHA DE PESQUISA---------------------------------------------------------------
% Se a natureza for Trabalho de Conclusão de Curso, deixe ambos os campos vazios
% Se for programa de Pós-graduação, indique a área de concentração e a linha de pesquisa
\areaconcentracao{}
\linhapesquisa{}

% DADOS DA INSTITUIÇÃO-----------------------------------------------------------------------------------
% Se a natureza for Trabalho de Conclusão de Curso, coloque o nome do curso de graduação em "programa"
% Formato para o logo da Instituição: \logoinstituicao{<escala>}{<caminho/nome do arquivo>}
\instituicao{Universidade Federal do Paraná}
\departamento{DELT - Departamento de Engenharia Elétrica}
\programa{Curso de Engenharia Elétrica}
\logoinstituicao{0.2}{dados/figuras/logo-instituicao.jpg} 

% DADOS DOS ORIENTADORES---------------------------------------------------------------------------------
\orientador{Dr. James Alexandre Baraniuk}
%\orientador[Orientadora:]{Nome da orientadora}
\instOrientador{DELT - Departamento de Engenharia Elétrica}

\coorientador{}
%\coorientador[Coorientadora:]{Nome da coorientadora}
\instCoorientador{}

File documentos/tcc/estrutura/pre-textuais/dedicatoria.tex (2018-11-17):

% DEDICATÓRIA------------------------------------------------------------------

\renewcommand{\dedicatorianame}{DEDICATÓRIA}

\begin{dedicatoria}

À memória de Thiago Borges Fonseca. 

\end{dedicatoria}

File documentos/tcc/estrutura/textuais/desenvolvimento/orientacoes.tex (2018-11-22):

% ORIENTAÇÕES GERAIS------------------------------------------------------------

% SOBRE AS ILUSTRAÇÕES----------------------------------------------------------
\chapter{SOBRE AS ILUSTRAÇÕES}
\label{chap:apSobreIlust}

A seguir exemplifica-se como inserir ilustrações no corpo do trabalho. As ilustrações serão indexadas automaticamente em suas respectivas listas. A numeração sequencial de figuras, tabelas e equações também ocorre de modo automático.

Referências cruzadas são obtidas através dos comandos \verb|\label{}| e \verb|\ref{}|. Sendo assim, não é necessário por exemplo, saber que o número de certo capítulo é \ref{chap:fundamentacaoTeorica} para colocar o seu número no texto. Outra forma que pode ser utilizada é esta: \autoref{chap:fundamentacaoTeorica}, facilitando a inserção, remoção e manejo de elementos numerados no texto sem a necessidade de renumerar todos esses elementos.

% FIGURAS-----------------------------------------------------------------------
\chapter{FIGURAS}
\label{chap:figuras}

Exemplo de como inserir uma figura. A \autoref{fig:figura-exemplo1} aparece automaticamente na lista de figuras. Para saber mais sobre o uso de imagens no \LaTeX{} consulte literatura especializada \cite{Goossens2007}.

Os arquivos das figuras devem ser armazenados no diretório de "/dados".

\begin{figure}[!htb]
    \centering
    \caption{Exemplo de Figura}
    
    \fonte{\citeonline{IRL2014}}
    \label{fig:figura-exemplo1}
\end{figure}

% QUADROS E TABELAS---------------------------------------------------------------
\chapter{QUADROS E TABELAS}
\label{chap:tabelas}

Exemplo de como inserir o 
%\autoref{qua:quadro-exemplo1} e a \autoref{tab:tabela-exemplo1}. Ambos aparecem automaticamente nas suas respectivas listas. Para saber mais informações sobre a construção de tabelas no \LaTeX{} consulte literatura especializada \cite{Mittelbach2004}.

Ambos os elementos (Quadros e Tabelas) devem ser criados em arquivos separados para facilitar manutenção e armazenados no diretório de "/dados".

%\input{./dados/quadros/quadro1}

A diferença entre quadro e tabela está no fato que um quadro é formado por linhas horizontais e verticais. Deve ser utilizado quando o conteúdo é majoritariamente não-numérico. O número do quadro e o título vem acima do quadro, e a fonte, deve vir abaixo. E Uma tabela é formada apenas por linhas verticais. Deve ser utilizada quando o conteúdo é majoritariamente numérico. O número da tabela e o título vem acima da tabela, e a fonte, deve vir abaixo, tal como no quadro.

\input{./dados/tabelas/tabela1}

% EQUAÇÕES-----------------------------------------------------------------------
\chapter{EQUAÇÕES}
\label{chap:equacoes}

Exemplo de como inserir a \autoref{eq:equacao-exemplo1} e a Eq. \ref{eq:equacao-exemplo2} no corpo do texto \footnote{Deve-se atentar ao fato de a formatação das equações ficar muito boa esteticamente.}. Observe que foram utilizadas duas formas distintas para referenciar as equações.

\begin{equation}
    X(s) = \int\limits_{t = -\infty}^{\infty} x(t) \, \text{e}^{-st} \, dt
    \label{eq:equacao-exemplo1}
\end{equation}

\begin{equation}
    F(u, v) = \sum_{m = 0}^{M - 1} \sum_{n = 0}^{N - 1} f(m, n) \exp \left[ -j 2 \pi \left( \frac{u m}{M} + \frac{v n}{N} \right) \right]
    \label{eq:equacao-exemplo2}
\end{equation}

% ALGORITMOS-----------------------------------------------------------------------
\chapter{ALGORITMOS}
\label{chap:algoritmos}

Exemplo de como inserir um algoritmo. Para inserção de algoritmos utiliza-se o pacote {\ttfamily algorithm2e} que já está devidamente configurado dentro do template.

Os algoritmos devem ser criados em arquivos separados para facilitar manutenção e armazenados no diretório de "/dados".\\
\\

\input{./dados/algoritmos/algoritmo1}

% SOBRE AS LISTAS--------------------------------------------------------------------
\chapter{SOBRE AS LISTAS}
\label{chap:apSobreLista}

Para construir listas de "\textit{bullets}"{} ou listas enumeradas, inclusive listas aninhadas, é utilizado o pacote \verb|paralist|.

Exemplo de duas listas não numeradas aninhadas, utilizando o comando \verb|\itemize|. Observe a indentação, bem como a mudança automática do tipo de "\textit{bullet}"{} nas listas aninhadas.

\begin{itemize}
    \item item não numerado 1
    \item item não numerado 2
    \begin{itemize}
        \item subitem não numerado 1
        \item subitem não numerado 2
        \item subitem não numerado 3
    \end{itemize}
    \item item não numerado 3
\end{itemize}

Exemplo de duas listas numeradas aninhadas, utilizando o comando \verb|\enumerate|. Observe a numeração progressiva e indentação das listas aninhadas.

\begin{enumerate}
    \item item numerado 1
    \item item numerado 2
    \begin{enumerate}
        \item subitem numerado 1
        \item subitem numerado 2
        \item subitem numerado 3
    \end{enumerate}
    \item item numerado 3
\end{enumerate}

% SOBRE AS CITAÇÕES E CHAMADAS DE REFERÊNCAS----------------------------------------------
\chapter{SOBRE AS CITAÇÕES E CHAMADAS DE REFERÊNCAS}
\label{chap:apSobreCita}

Citações são trechos de texto ou informações obtidas de materiais consultadss quando da elaboração do trabalho. São utilizadas no texto com o propósito de esclarecer, completar e embasar as ideias do autor. Todas as publicações consultadas e utilizadas (por meio de citações) devem ser listadas, obrigatoriamente, nas referências bibliográficas, para preservar os direitos autorais. São classificadas em citações indiretas e diretas.

% CITAÇÕES INDIRETAS-----------------------------------------------------------------------
\chapter{CITAÇÕES INDIRETAS}
\label{chap:citacoesLivres}

É a transcrição, com suas próprias palavras, das idéias de um autor, mantendo-se o sentido original. A citação indireta é a maneira que o pesquisador tem de ler, compreender e gerar conhecimento a partir do conhecimento de outros autores. Quanto à chamada da referência, ela pode ser feita de duas maneiras distintas, conforme o nome do(s) autor(es) façam parte do seu texto ou não. Exemplo de chamada fazendo parte do texto:\\
\\Enquanto \citeonline{Maturana2003} defendem uma epistemologia baseada na biologia. Para os autores, é necessário rever \ldots.\\

A chamada de referência foi feita com o comando \verb|\citeonline{chave}|, que produzirá a formatação correta.

A segunda forma de fazer uma chamada de referência deve ser utilizada quando se quer evitar uma interrupção na sequência do texto, o que poderia, eventualmente, prejudicar a leitura. Assim, a citação é feita e imediatamente após a obra referenciada deve ser colocada entre parênteses. Porém, neste caso específico, o nome do autor deve vir em caixa alta, seguido do ano da publicação. Exemplo de chamada não fazendo parte do texto:\\
\\Há defensores da epistemologia baseada na biologia que argumentam em favor da necessidade de \ldots \cite{Maturana2003}.\\

Nesse caso a chamada de referência deve ser feita com o comando \verb|\cite{chave}|, que produzirá a formatação correta.

% CITAÇÕES DIRETAS-----------------------------------------------------------------------
\chapter{CITAÇÕES DIRETAS}
\label{chap:citacoesLiterais}

É a transcrição ou cópia de um parágrafo, de uma frase, de parte dela ou de uma expressão, usando exatamente as mesmas palavras adotadas pelo autor do trabalho consultado.

Quanto à chamada da referência, ela pode ser feita de qualquer das duas maneiras já mencionadas nas citações indiretas, conforme o nome do(s) autor(es) façam parte do texto ou não. Há duas maneiras distintas de se fazer uma citação direta, conforme o trecho citado seja longo ou curto.

Quando o trecho citado é longo (4 ou mais linhas) deve-se usar um parágrafo específico para a citação, na forma de um texto recuado (4 cm da margem esquerda), com tamanho de letra menor e espaçamento entrelinhas simples. Exemplo de citação longa:
\\\begin{citacao}
    Desse modo, opera-se uma ruptura decisiva entre a reflexividade filosófica, isto é a possibilidade do sujeito de pensar e de refletir, e a objetividade científica. Encontramo-nos num ponto em que o conhecimento científico está sem consciência. Sem consciência moral, sem consciência reflexiva e também subjetiva. Cada vez mais o desenvolvimento extraordinário do conhecimento científico vai tornar menos praticável a própria possibilidade de reflexão do sujeito sobre a sua pesquisa \cite[p.~28]{Silva2000}.
\end{citacao}

Para fazer a citação longa deve-se utilizar os seguintes comandos:
\begin{verbatim}
\begin{citacao}
<texto da citacao>
\end{citacao}
\end{verbatim}

No exemplo acima, para a chamada da referência o comando \verb|\cite[p.~28]{Silva2000}| foi utilizado, visto que os nomes dos autores não são parte do trecho citado. É necessário também indicar o número da página da obra citada que contém o trecho citado.

Quando o trecho citado é curto (3 ou menos linhas) ele deve inserido diretamente no texto entre aspas. Exemplos de citação curta:\\
\\A epistemologia baseada na biologia parte do princípio de que "assumo que não posso fazer referência a entidades independentes de mim para construir meu explicar" \cite[p.~35]{Maturana2003}.\\
\\A epistemologia baseada na biologia de \citeonline[p.~35]{Maturana2003} parte do princípio de que "assumo que não posso fazer referência a entidades independentes de mim para construir meu explicar".

% DETALHES SOBRE AS CHAMADAS DE REFERÊNCIAS---------------------------------------------------------
\chapter{DETALHES SOBRE AS CHAMADAS DE REFERÊNCIAS}
\label{chap:referUtilizadas}

Outros exemplos de comandos para as chamadas de referências e o resultado produzido por estes:\\
\\\citeonline{Maturana2003} \ \ \  \verb|\citeonline{Maturana2003}|\\
\citeonline{Barbosa2004} \ \ \   \verb|\citeonline{Barbosa2004}|\\
\cite[p.~28]{Silva2000} \ \ \  \verb|\cite[p.~28]{Silva2000}|\\
\citeonline[p.~33]{Silva2000} \ \ \   \verb|\citeonline[p.~33]{v}|\\
\cite[p.~35]{Maturana2003} \ \ \   \verb|\cite[p.~35]{Maturana2003}|\\
\citeonline[p.~35]{Maturana2003} \ \ \   \verb|\citeonline[p.~35]{Maturana2003}|\\
\cite{Barbosa2004,Maturana2003} \ \ \   \verb|\cite{Barbosa2004,Maturana2003}|\\

% SOBRE AS REFERÊNCIAS BIBLIOGRÁFICAS-------------------------------------------------------
\chapter{SOBRE AS REFERÊNCIAS BIBLIOGRÁFICAS}
\label{chap:apSobreRefer}

A bibliografia é feita no padrão \textsc{Bib}\TeX{}. As referências são colocadas em um arquivo separado. Neste template as referências são armazenadas no arquivo "base-referencias.bib".

Existem diversas categorias documentos e materiais componentes da bibliografia. A classe abn\TeX{} define as seguintes categorias (entradas):

\begin{verbatim}
@book
@inbook
@article
@phdthesis
@mastersthesis
@monography
@techreport
@manual
@proceedings
@inproceedings
@journalpart
@booklet
@patent
@unpublished
@misc
\end{verbatim}

Cada categoria (entrada) é formatada pelo pacote \citeonline{abnTeX22014d} de uma forma específica. Algumas entradas foram introduzidas especificamente para atender à norma \citeonline{NBR6023:2002}, são elas: \verb|@monography|, \verb|@journalpart|,\verb|@patent|. As demais entradas são padrão \textsc{Bib}\TeX{}. Para maiores detalhes, refira-se a \citeonline{abnTeX22014d}, \citeonline{abnTeX22014b}, \citeonline{abnTeX22014c}.

% NOTAS DE RODAPÉ--------------------------------------------------------------------------
\chapter{NOTAS DE RODAPÉ}
\label{chap:notasRodape}

As notas de rodapé pode ser classificadas em duas categorias: notas explicativas\footnote{é o tipo mais comum de notas que destacam, explicam e/ou complementam o que foi dito no corpo do texto, como esta nota de rodapé, por exemplo.} e notas de referências. A notas de referências, como o próprio nome ja indica, são utilizadas para colocar referências e/ou chamadas de referências sob certas condições.

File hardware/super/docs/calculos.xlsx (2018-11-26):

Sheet: Vin min 74HC165
Vcc | Vin
2 | 1.5
4.5 | 3.15
6 | 4.2
VIN | 1.500 | 3.150 | 4.200 | 3.495
VCC | 2 | 4.5 | 6 | 5

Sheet: Divisor TCRT5000
Vcc | 5
Vout | 3.3
Vhmin | 2.475
Vlmax | 0.825
Rsup | 10000
Rinf | 18000
Vout | 3.214285714

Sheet: Teclado ADC
S3 | 0.94 | 959.6379863
S4 | 0.54 | 550.955666
S5 | 0.37 | 378.708495
S6 | 0.27 | 278.5279435
 |  |  | 3.3
 |  |  | 430 | 397.1580817 | 0.9380625477
 |  |  | 1000 | 390.0647948 | 0.5385685885
 |  |  | 1000 | 379.0633609 | 0.3701940323
 |  |  | 1000 | 359.6958175 | 0.2722658294
 |  |  | 1000
 |  |  | 2200

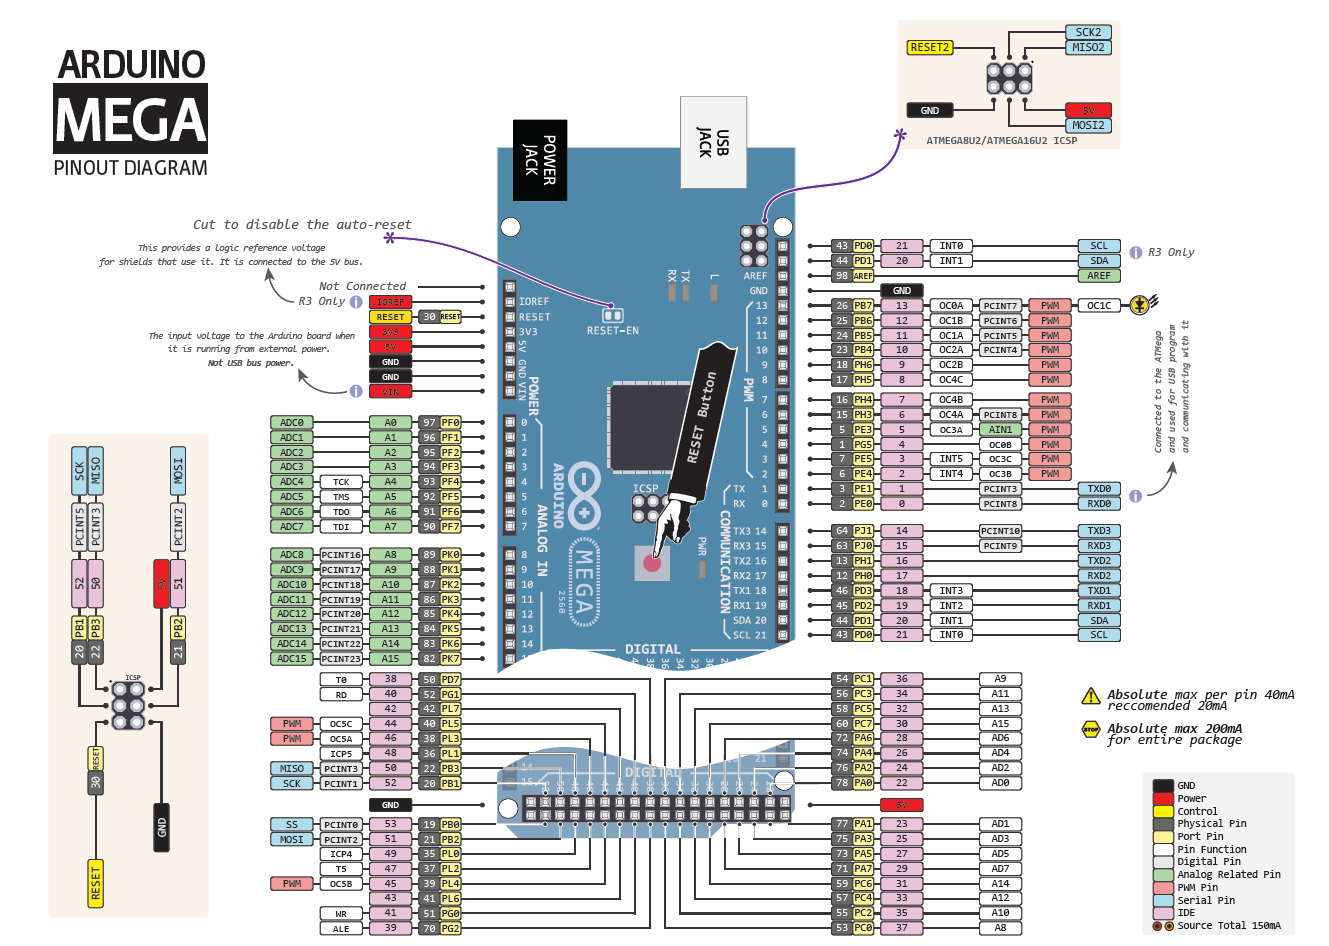
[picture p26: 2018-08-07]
hardware/datasheets/Arduino Mega Pinout.png

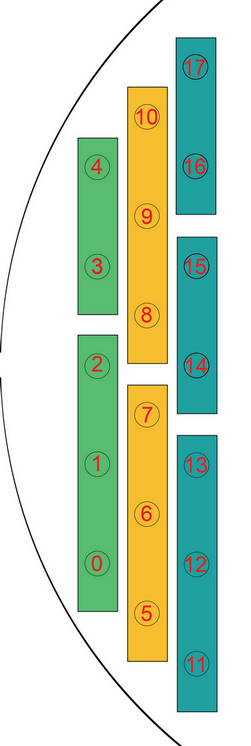
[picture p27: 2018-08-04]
documentos/proposta/img/mesa-leds.png

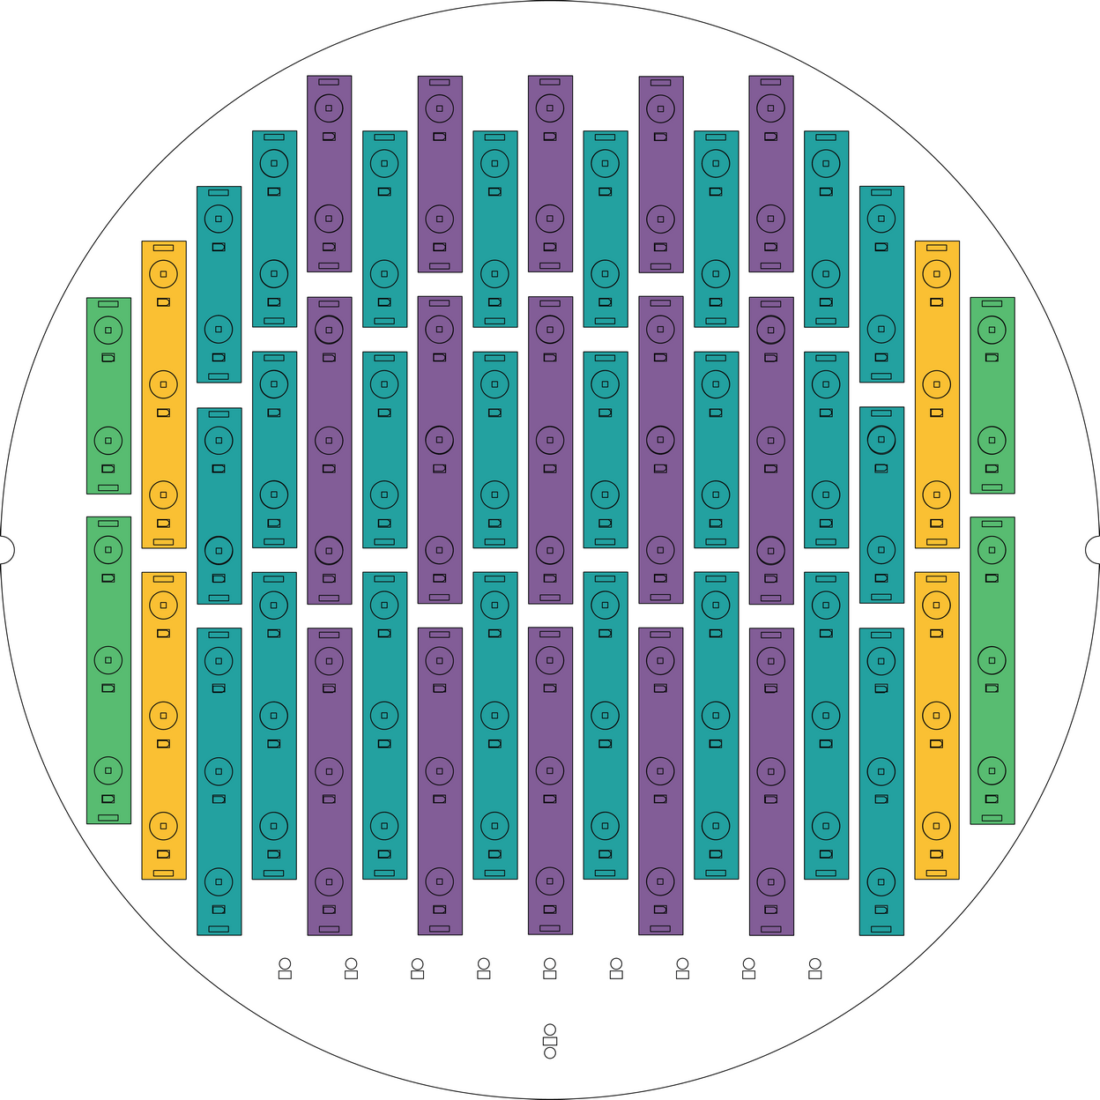
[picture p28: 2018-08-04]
documentos/proposta/img/mesa-placas.png

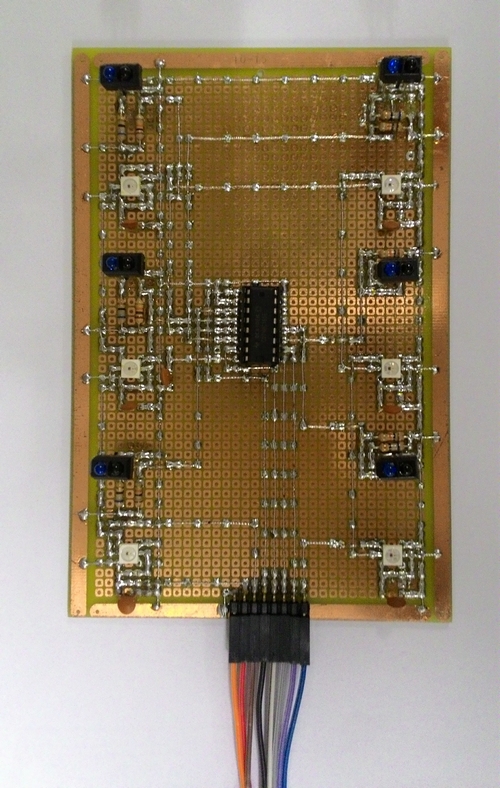
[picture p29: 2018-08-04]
documentos/proposta/img/p-proto-circ.jpg

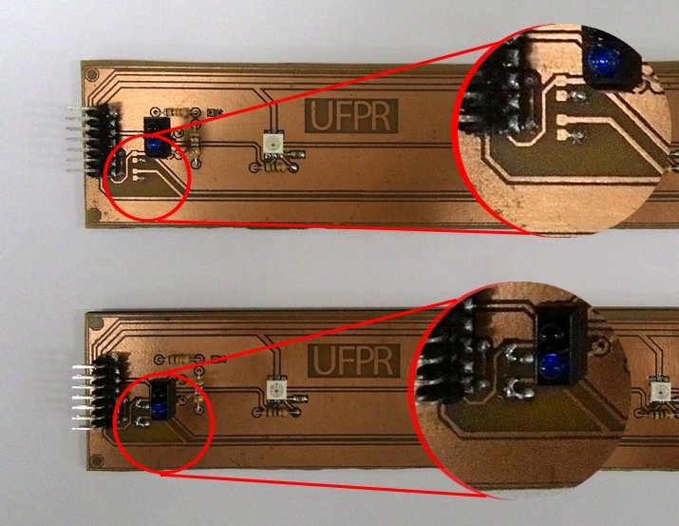
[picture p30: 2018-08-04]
documentos/proposta/img/mesa-jumpers.jpg

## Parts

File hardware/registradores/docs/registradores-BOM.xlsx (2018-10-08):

Comment | Description | Designator | Footprint | LibRef | Quantity
100NF/50V |  | C1, C2, C3, C4, C5, C6, C7, C8, C9 | CAP SMD 0603-N | CAP. CER., 100NF, 50V, SMD, 0603-N | 9
KK 2x1 |  | J1, J2, J3 | MOLEX KK 396 2 PINOS VERTICAL MACHO | KK Molex 2x1 Vertical Macho | 3
NT0603 |  | NT1 | RES SMD 0603-N | NET TIE SMD 0603 | 1
LATCH 7x2 | Header, 14-Pin, Dual row | P1, P2, P3, P4, P5, P6, P7, P8, P9 | Shrouded Header Latch 2x7 90º Male | LATCH 7x2 Macho Horizontal | 9
Header 3x2 | Header, 6-Pin, Dual row, Horizontal, Male | P10, P11 | HEADER 3X2 HORIZONTAL MACHO | Header 3x2 Horizontal Macho | 2
RES-US, 0R, SMD, 0603-N |  | R1, R2 | RES SMD 0603-N | RES-US, 0R, SMD, 0603-N | 2
74HC165D | 8-Bit Parallel-Load Shift Registers | U1, U2, U3, U4, U5, U6, U7, U8, U9 | SOIC16_N | 74HC165D | 9

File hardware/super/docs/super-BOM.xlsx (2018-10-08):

Comment | Description | Designator | Footprint | LibRef | Quantity
100NF/6V3 |  | C1, C2, C3, C4, C5, C6, C7, C8, C9, C10, C11, C12, C26 | CAP SMD 0603-N | CAP. CER., 100NF, 6V3, SMD, 0603-N | 13
10UF/6V3 |  | C13, C14, C15, C16, C17, C18, C19, C20, C21, C22, C24, C27 | CAP SMD 0603-N | CAP. CER., 2U2F, 6V3, SMD, 0603-N, CAP. CER., 2U2F, 6V3, SMD, 0603-N, CAP. CER., 2U2F, 6V3, SMD, 0603-N, CAP. CER., 2U2F, 6V3, SMD, 0603-N, CAP. CER., 2U2F, 6V3, SMD, 0603-N, CAP. CER., 2U2F, 6V3, SMD, 0603-N, CAP. CER., 2U2F, 6V3, SMD, 0603-N, CAP. CER., 2U2F, 6V3, SMD, 0603-N, CAP. CER., 2U2F, 6V3, SMD, 0603-N, CAP. CER., 2U2F, 6V3, SMD, 0603-N, CAP. CER., 10UF, 6V3, SMD, 0603-N, CAP. CER., 10UF, 6V3, SMD, 0603-N | 12
100UF/6V3 |  | C23 | CAP ALUM SMD 6.6MM | CAP. ALUM., 100UF, 6V3, SMD 6.6MM | 1
100NF/50V |  | C25 | CAP SMD 0603-N | CAP. CER., 100NF, 50V, SMD, 0603-N | 1
WS2812 | Intelligent control LED integrated light source | D1, D2, D3, D4, D5, D6, D7, D8, D9, D10, D11 | WS2812 | WS2812 | 11
BAT43 | Schottky Diode | D12, D13, D14, D15, D16 | MELF-D3516-1406 | DIODO SCHOTTKY BAT43 SMD MINIMELF | 5
TCRT5000L | Long lead version - Reflective Optical Sensor with Transistor Output | D17, D18, D19, D20, D21, D22, D23, D24, D25, D26 | TCRT5000L | TCRT5000L | 10
1N4007 | 1 Amp General Purpose Rectifier | D27 | DIODE SMA | DIODO 1N4007 SMD SMA DO-214AC | 1
KK 3x1 | KK 3x1 Molex 396 | J1 | MOLEX KK 396 3 PINOS HORIZONTAL MACHO | KK MOLEX 3X1 HORIZONTAL MACHO | 1
KK 2x1 | KK 2x1 Molex 396 | J2, J3 | MOLEX KK 396 2 PINOS VERTICAL MACHO | KK MOLEX 2X1 VERTICAL MACHO | 2
NT0603 |  | NT1 | RES SMD 0603-N | NET TIE SMD 0603 | 1
Header 3x2 | Header, 6-Pin, Dual row, Vertical, Male | P1, P2 | HEADER 3X2 VERTICAL MACHO | HEADER 3X2 VERTICAL MACHO | 2
FTDI (RTS) (3V3) | Header, 6-Pin, Horizontal, Male | P3 | HEADER 6X1 HORIZONTAL MACHO | HEADER MÓDULO FTDI (RTS) 6X1 H-M | 1
TRANSISTOR BC817-16 NPN SMD SOT23 | 45V NPN SMALL SIGNAL TRANSISTOR IN SOT23 | Q1, Q2, Q3, Q4, Q5, Q6, Q7 | SOT23-3N | TRANSISTOR BC817-16 NPN SMD SOT23 | 7
RES-US, 150R, 5%, SMD, 1206-N |  | R1, R2, R3, R4, R5, R6, R7, R8, R9, R10, R11 | RES SMD 1206-N | RES-US, 150R, 5%, SMD, 1206-N | 11
RES-US, 10K, 5%, SMD, 1206-N |  | R12, R13, R14, R15, R16, R17, R18, R19, R20, R22, R23, R25, R26, R27, R28 | RES SMD 1206-N | RES-US, 10K, 5%, SMD, 1206-N | 15
RES-US, 4K7, 5%, SMD, 1206-N |  | R21, R49 | RES SMD 1206-N | RES-US, 4K7, 5%, SMD, 1206-N | 2
RES-US, 9K1, 5%, SMD, 1206-N |  | R24 | RES SMD 1206-N | RES-US, 9K1, 5%, SMD, 1206-N | 1
RES-US, 68R, 5%, SMD, 1206-N |  | R29, R31, R33, R35, R37, R39, R41, R43, R45, R47 | RES SMD 1206-N | RES-US, 68R, 5%, SMD, 1206-N | 10
RES-US, 10K, 5%, SMD, 0805-N |  | R30, R32, R34, R36, R38, R40, R42, R44, R46, R48 | RES SMD 0805-N | RES-US, 10K, 5%, SMD, 0805-N | 10
RES-US, 0R, SMD, 0603-N |  | R50, R55 | RES SMD 0603-N | RES-US, 0R, SMD, 0603-N | 2
RES-US, 12K, 5%, SMD, 1206-N |  | R51, R53, R54 | RES SMD 1206-N | RES-US, 12K, 5%, SMD, 1206-N | 3
RES-US, 560R, 5%, SMD, 0805-N |  | R52, R56 | RES SMD 0805-N | RES-US, 560R, 5%, SMD, 0805-N | 2
RES-US, 1K, 1%, SMD, 0805-N |  | R57, R59, R60 | RES SMD 0805-N | RES-US, 1K, 1%, SMD, 0805-N | 3
RES-US, 100K, 1%, SMD, 0805-N |  | R58 | RES SMD 0805-N | RES-US, 100K, 1%, SMD, 0805-N | 1
RES-US, 2K2, 1%, SMD, 0805-N |  | R61 | RES SMD 0805-N | RES-US, 2K2, 1%, SMD, 0805-N | 1
MICRO CHAVE SMD 5X5MM | Tactile Micro Switch, SMD, 5x5mm | S1, S2, S3, S4, S5, S6 | TACTILE_SWITCH_SMD_5.2MM | MICRO CHAVE SMD 5X5MM | 6
TEST POINT 1.5MM |  | TP1, TP2, TP3, TP4, TP5, TP6, TP7, TP8, TP9, TP10, TP11, TP12, TP13, TP14, TP15, TP16, TP17, TP18, TP19, TP20, TP21, TP22, TP23, TP24 | TP-1.5MM | TEST POINT 1.5MM | 24
74HC165D | 8-Bit Parallel-Load Shift Registers | U1 | SOIC16_N | 74HC165D | 1
REG. LINEAR 3V3 SMD SOT-223 LM1117MPX-3.3 | 3V3 800-mA Low-Dropout Linear Regulator | U2 | SOT223-4N - LM1117 | REG. LINEAR 3V3 SMD SOT-223 LM1117MPX-3.3 | 1
ESP-12 Breakout |  | U3 | ENCAIXE ESP12-E ADAPTER | ESP-12 BREAKOUT | 1

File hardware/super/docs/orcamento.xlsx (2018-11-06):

Projeto | Mesa de Bolinhas - Super | Empresa | Localização | Contato | Prazo prod. | Qtde placas | Valor unitário | Adicional (?) | Sub-total | IPI | Frete | Valor total | Comentários
Versão | REV20181027 | RSCAD | Belenzinho -SP | pci@rscad.com.br
Dimensão (mm x mm) | 500 x 90 | VB Circuitos | São Paulo - SP | vbcircuitos@vbcircuitos.com.br |  |  |  |  |  |  |  |  | Não informou tamanho máximo
Tipo | FR4 dupla-face | NV Tecnologia | São Paulo - SP | nvtecnologia@plugnet.com.br ; altair@nvtecnologia.com.br |  | 5 | R$240.00 | R$0.00 | R$1200.00 | 0% | R$0.00 | R$1200.00
Espessura placa (mm) | 1.6 | TEC-CI | São Paulo - SP | vendas@tec-ci.com.br |  | 5 | R$148.10 | R$206.00 | R$946.50 |  |  | R$946.50
Espessura cobre (oz) | 1 | Digicart | Nova Trento - SC | vendas@digicart.com.br |  |  |  |  | R$0.00 |  |  | R$0.00
 |  | Circuitel | Pinhais - PR | vendas@circuitel.com.br |  |  |  |  | R$0.00 |  |  | R$0.00
 |  | Griffus | Cotia - SP | gvendas@griffus.com.br |  |  |  |  | R$0.00 |  |  | R$0.00
 |  | Tecnel | Taboão da Serra - SP | vendas@tecneleletronica.com.br |  | 5 | R$240.00 | R$0.00 | R$1200.00 | 0% | R$0.00 | R$1200.00
 |  | Rossi-Plac | São Paulo - SP | vendas@rossiplac.com |  |  |  |  | R$0.00 |  |  | R$0.00
 |  | Stick | Belo Horizonte - MG | stick@stick.ind.br |  | 1 | R$602.36 | R$0.00 | R$602.36 | 0% | R$0.00 | R$602.36
 |  | Cirvale | Sta Rita do Sapucaí - MG | orcamento@cirvale.com.br |  |  |  |  | R$0.00 |  |  | R$0.00
 |  | WF | Presidente Prudente - SP | wf@wf.ind.br |  |  |  |  | R$0.00 |  |  | R$0.00 | 292x393
 |  | Luchtec | Guarulhos - SP | contato@luchtec.com.br |  |  |  |  | R$0.00 |  |  | R$0.00
 |  | Printcir | Taboão da Serra - SP | print@printcir.com.br |  |  |  |  | R$0.00 |  |  | R$0.00
 |  | RB (Circuitel) | Pinhais - PR | vendas1@rbcircuitos.com.br |  |  |  |  | R$0.00 |  |  | R$0.00
 |  | UTFPR | Curitiba - PR | castaldo@utfpr.edu.br |  |  |  |  | R$0.00 |  |  | R$0.00 | 250x180
 |  | Casa do Circuito | Caxias do Sul - RS | franciele@casadocircuito.com.br |  | 4 | R$107.16 | R$100.00 | R$528.64 | 10% | R$0.00 | R$581.50

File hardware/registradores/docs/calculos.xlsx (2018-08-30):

 | qtde | I (A) | I sub-total
WS2812 | 128 | 0.06 | 7.68 | 3.84 | I VLED (A)
TCRT5000-P | 128 | 0.05560705882 | 7.12 | 3.56 | I VSENSOR (A)
 |  | Total mesa: | 14.80
TCRT5000-P
Vcc (V) | 5
Vf LED (V) | 1.25
Res LED | 68
I LED (A) | 0.05514705882 | 55.14705882 | mA
Vce sat (V) | 0.4
Res Coletor (Ohms) | 10000
I transistor (A) | 0.00046 | 0.46 | mA
Total TCRT5000 | 0.05560705882 | 55.607 | mA

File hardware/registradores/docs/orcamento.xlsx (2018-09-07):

Projeto | Mesa de Bolinhas - Registradores |  | Empresa | Localização | Prazo prod. | Qtde placas | Valor unitário | Adicional (?) | Sub-total | IPI | Frete | Valor total | Comentários
Versão | REV20180906 | ok | RSCAD | Belenzinho -SP |  | 8 |  |  | R$0.00 |  |  | R$700.00 | Tudo incluso
Dimensão (mm x mm) | 254 x 32.766 | ok | VB Circuitos | São Paulo - SP |  |  |  |  | R$0.00 |  |  | R$0.00
Tipo | FR4 dupla-face | ok | NV Tecnologia | São Paulo - SP |  |  |  |  | R$0.00 |  |  | R$0.00
Espessura placa (mm) | 1.6 | ok | TEC-CI | São Paulo - SP | 10 | 5 | R$98.08 | R$75.00 | R$565.40 |  | R$41.00 | R$606.40
Espessura cobre (oz) | 1 | ok | Digicart | Nova Trento - SC | 10 | 5 | R$31.90 | R$85.00 | R$244.50 | 20% |  | R$293.40
Menor pista (mil) | 20 | ok | Circuitel | Pinhais - PR |  |  |  |  | R$0.00 |  |  | R$0.00
Menor isolação (mil) | 15 | ok | Griffus | Cotia - SP |  |  |  |  | R$0.00 |  |  | R$0.00
Diâmetro do menor furo (mil) | 28 | ok | Tecnel | Taboão da Serra - SP |  | 20 | R$60.00 | R$0.00 | R$1200.00 |  |  | R$1200.00
 |  | ok | Rossi-Plac | São Paulo - SP |  |  |  |  | R$0.00 |  |  | R$0.00
 |  | ok | AMR Eletrônica | São Paulo - SP |  |  |  |  | R$0.00 |  |  | R$0.00 | Address not found
 |  | ok | Stick | Belo Horizonte - MG |  |  |  |  | R$0.00 |  |  | R$0.00
 |  | ok | Cirvale | Sta Rita do Sapucaí - MG | 12 | 3 | R$100.00 |  | R$300.00 | 10% |  | R$330.00
 |  | ok | WF | Presidente Prudente - SP | 7 |  |  |  | R$800.00 |  |  | R$800.00 | Acho que são 10 placas
 |  | ok | Luchtec | Guarulhos - SP | 13 | 5 | R$86.00 | R$90.00 | R$520.00 |  | R$25.00 | R$545.00
 |  | ok | RCI | Osasco - SP |  |  |  |  | R$0.00 |  |  | R$0.00 | Address not found
 |  | ok | Printcir | Taboão da Serra - SP |  |  |  |  | R$0.00 |  |  | R$0.00
 |  | ok | RB (Circuitel) | Pinhais - PR | 5 | 4 | R$75.00 | R$180.00 | R$480.00 | 0% | R$35.00 | R$515.00
https://curtacircuitos.com.br/

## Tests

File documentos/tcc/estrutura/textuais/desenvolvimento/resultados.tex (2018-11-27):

% RESULTADOS-------------------------------------------------------------------

\chapter{ANÁLISE E DISCUSSÃO DOS RESULTADOS}
\label{chap:analise-resultados}

Devido à complexidade dos circuitos, as placas desta etapa do projeto não foram produzidas como protótipos artesanais, como foi feito com as PCIs da Matriz durante o Programa de Iniciação Científica. As placas aqui projetadas possuem uma grande quantidade de vias (furos metalizados que interligam as faces), trilhas e isolação (separação mínima entre as trilhas) muito pequenas, o que tornaria inviável sua fabricação no Laboratório de Corrosão por falta de material adequado. Portanto, os projetos dessas PCIs foram enviados diretamente para a fabricação industrial.

A \autoref{fig:pci-interface} apresenta a placa de circuito impresso da Interface, já com seus componentes montados. Foi fabricada por uma empresa da região de Nova Trento, em Santa Catarina, a de orçamento mais acessível entre as quase 20 empresas contatadas. Trata-se de uma produção industrial, inclusive com a garantia de integridade por meio de testes elétricos.

\begin{figure}[H]
    \centering
    \caption{Placa de circuito impresso da Interface}
    
    \fonte{(O AUTOR, 2018)}
    \label{fig:pci-interface}
\end{figure}

Com relação à placa de circuito impresso da seção de controle, após contatar mais de 20 empresas, somente cerca de 3 delas teriam capacidade de produzir PCIs com tamanhas dimensões (500 mm x 90 mm), sendo que os valores ultrapassavam os R\$1000,00. Então, decidiu-se reprojetar a placa do Controlador, na verdade, separá-la em outras 3 PCIs, como apresentado na \autoref{fig:controlador-corte}. Dessa forma, as PCIs teriam as dimensões adequadas para produção na maioria das empresas. Ademais, as placas seriam conectadas por meio de resistores de $0\Omega$ (encapsulamento SMD 1206), dispensando o uso de fios. 

\begin{figure}[H]
    \centering
    \caption{Reprojeto da placa de controle, detalhe para os locais de corte e resistores de conexão}
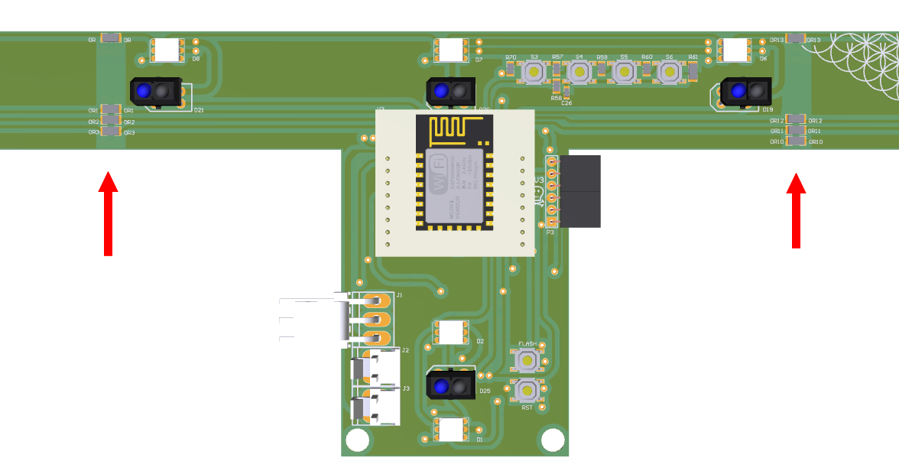
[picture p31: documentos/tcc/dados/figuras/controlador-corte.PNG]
    
    \fonte{(O AUTOR, 2018)}
    \label{fig:controlador-corte}
\end{figure}

Contudo, como mencionado no \autoref{chap:metodologia}, cada modelo de placa é considerado um projeto íntegro pelas fabricantes de PCIs e, em virtude do pedido mínimo, o valor total ainda seria alto. Então, as placas foram enviadas para a fabricação em uma universidade da região de Curitiba, que conta com um laboratório de produção de protótipos, inclusive com confecção de vias metalizadas. As Figuras \ref{fig:controlador-esq}, \ref{fig:controlador-dir} e \ref{fig:controlador-cen} apresentam os protótipos fabricados.

\begin{figure}[H]
    \centering
    \caption{Placa Esquerda do Controlador}
    
    \fonte{(O AUTOR, 2018)}
    \label{fig:controlador-esq}
\end{figure}

\begin{figure}[H]
    \centering
    \caption{Placa Direita do Controlador}
    
    \fonte{(O AUTOR, 2018)}
    \label{fig:controlador-dir}
\end{figure}

\begin{figure}[H]
    \centering
    \caption{Placa Central do Controlador, parcialmente montada}
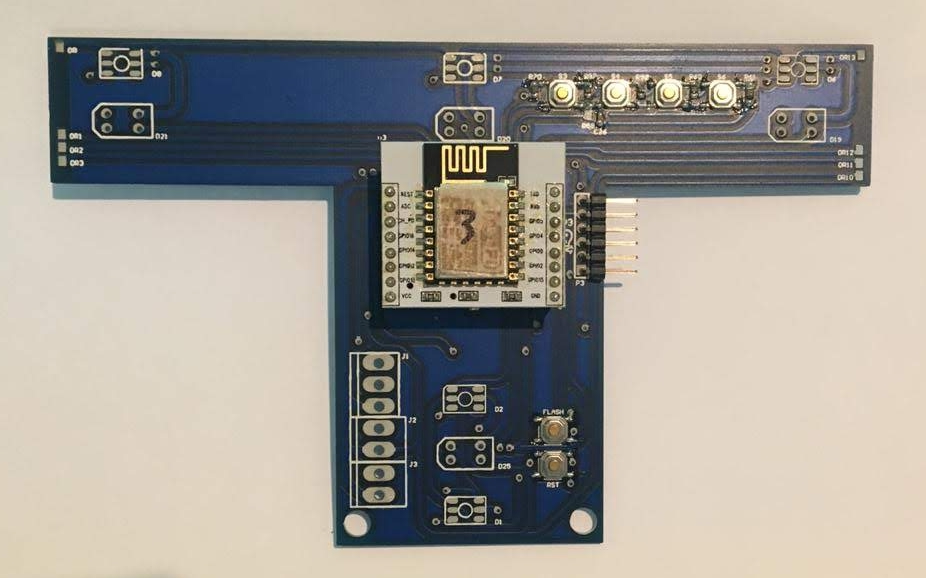
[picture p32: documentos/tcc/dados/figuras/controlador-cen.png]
    
    \fonte{(O AUTOR, 2018)}
    \label{fig:controlador-cen}
\end{figure}

Visto a carência de várias técnicas de roteamento do \emph{software} de leiaute utilizado durante o Programa de Iniciação Científica, o autor optou por usar um \emph{software} mais avançado para o desenvolvimento deste projeto (Interface e Controlador). Entretanto, devido à inexperiência com o novo programa e também à sua complexidade, maior que a do \emph{software} anterior, o andamento do projeto já vinha atrasado em relação ao cronograma. Além disso, houve dificuldade na montagem das placas do Controlador. Por se tratarem de protótipos produzidos de maneira semi-industrial, o acabamento da superfície exposta (terminais de cobre) é de qualidade muito inferior ao das placas fabricadas de forma industrial (PCIs da Interface). A \autoref{fig:comparacao-pads} \footnote{A imagem está distorcida devido à lente de aproximação.} apresenta a comparação dos dois modelos: à esquerda, o protótipo do Controlador, e à direita, a placa da Interface, produzida de forma industrial. Nota-se que o acabamento da placa do Controlador é mais fosco que o da Interface, mais granuloso. Esse material é de difícil aderência ao estanho através do ferro de solda. Talvez, o mais indicado seria a montagem por meio de uma estação de solda por ar quente, que alcança de maneira uniforme toda a área a ser soldada, além do fluxo especial da pasta de solda. Entretanto, nem o autor, nem a universidade dispõem desse equipamento.

\begin{figure}[H]
    \centering
    \caption{Comparação do acabamento dos terminais de solda}
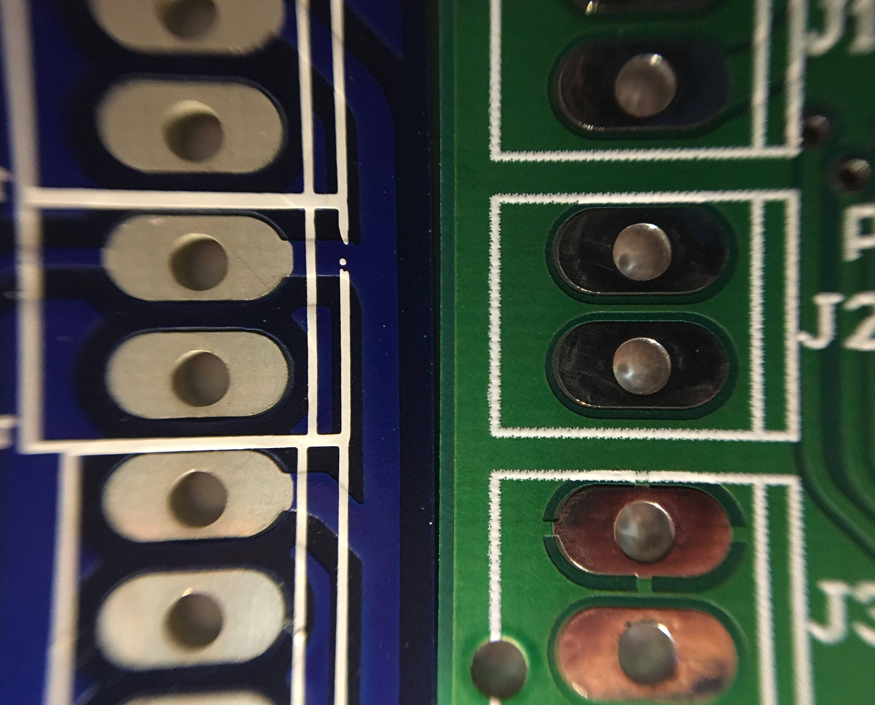
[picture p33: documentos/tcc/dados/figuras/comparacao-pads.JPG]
    
    \fonte{(O AUTOR, 2018)}
    \label{fig:comparacao-pads}
\end{figure}

Em função da placa de controle não ter sido finalizada dentro do período do cronograma, não foi possível testar o \emph{firmware} desenvolvido, que já estava em uma etapa avançada, porém ainda não havia sido testado, uma vez que dependia dos periféricos do Controlador. O código das implementações se encontram na seção de Apêndices, sendo: inicialização dos periféricos internos, inicialização dos periféricos externos, técnica de \emph{debounce} e fila de eventos. Faltando apenas a máquina de estados finita dos LEDs.

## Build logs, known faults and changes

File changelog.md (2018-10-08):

#### Registro de alterações

##### 07/08/2018

- Repositório e módulos para Github/Gitlab (readme, gitignore, changelog)
- Integração arquivos Iniciação Científica
- Iniciado o projeto no Altium Designer
  - registradores
    - shift-registers
  - super
    - seletor de cor
    - controlador

- Compra do NodeMcu (ESP8266 ESP-12E CH340G)

##### 14/08/2018
- Criação de componentes

##### 15/08/2018
- Reunião 1
  - Revisão teórica
    - [ ] WS2812 (1 ou 2 páginas)
    - [ ] Datasheet: apêndice
    - [ ] ESP8266 (2 páginas)
    - [ ] ArtNet
    - [ ] Descrição da mesa
    - [ ] Sensor reflexivo (1 página)
    - [ ] Outros objetos interativos (outras universidades) (1 ou 2 páginas)

  - Diagrama do projeto
    - LED
    - Sensor
    - CPU
    - PC

  - Etapas do projeto (como um todo)
    - App Xmind
    - Revisão teórica
    - Componentes

  - Primeira banca
    - Introdução (contextualização)
      - [x] IC
      - [x] Ensino de ciências
    - [x] Problema
    - [x] Objetivo Geral
    - [x] Objetivos específicos
    - [x] Revisão teórica
    - [x] Diagrama das Etapas
    - [x] Diagrama do projeto
      - Falar também sobre as tecnologias utilizadas
    - [x] Resultados esperados (o que será entregue)
    - [x] Relevância
      - Curso
      - Pessoal
    - [x] Cronograma
    - [x] Referências
    - [x] Agradecimentos

  Valorizar a complexidade, [x] falar das placas que já foram feitas, colocar que já estamos numa etapa avançada e que é difícil acatar as mudanças sugeridas pela banca.

##### 16/08/2018
- Criação de componentes

##### 20/08/2018
- Reunião 2
  - [ ] Cálculo do consumo
    - [ ] LEDs
    - [ ] Sensores
    - [ ] 74HC165
    - [ ] Placa micro
  - [ ] Cálculo do tempo de propagação LEDs e shift

##### 27/08/2018
- Reunião 3
  - [x] Remoção da proteção de entrada
  - [x] Compra BOM Registradores

##### 03/09/2018
- Finalização layout Registradores
- Design Rule Check

##### 04/08/2018
- Conferência do netlist Registradores

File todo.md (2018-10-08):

#### Lista de Tarefas

- [x] Comprar NodeMcu
- [x] Esquemático Registradores
- [x] Esquemático Super
- [x] Compra BOM Registradores
- [x] Compra BOM Super
- [ ] Conferência Footprints
- [x] Leiaute Registradores
- [ ] Leiaute Super
- [x] Conferência Netlist Registradores
- [ ] Conferência Netlist Super
- [x] Produção PCI Registradores
- [ ] Produção PCI Super
- [ ] Montagem Registradores
- [ ] Soldar resistores de 0R da última placa de cada coluna (entradas flutuantes)
- [ ] Montagem Super
- [ ] Código Debounce*
- [ ] Código Main Machine
- [ ] Código ArtNet
- [ ] Integração Mecânica
- [ ] Testes
- [ ] Relatório Atividade 1
- [ ] Relatório Atividade 2
- [x] Apresentação Parcial
- [ ] Apresentação Final
- [ ] Relatório Final

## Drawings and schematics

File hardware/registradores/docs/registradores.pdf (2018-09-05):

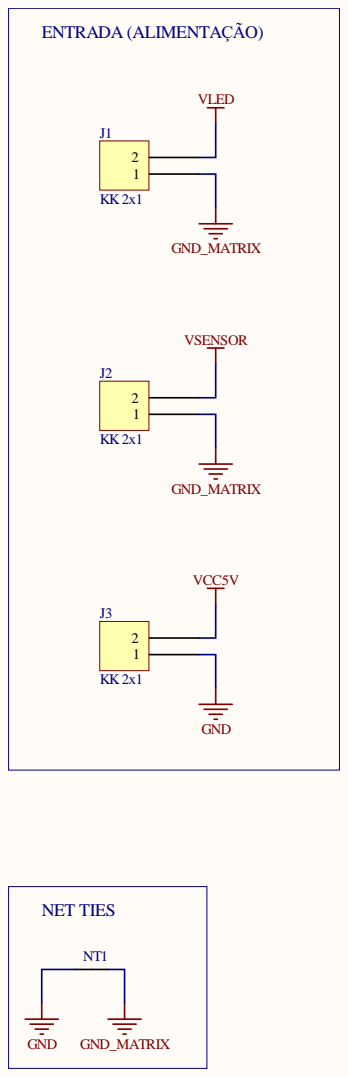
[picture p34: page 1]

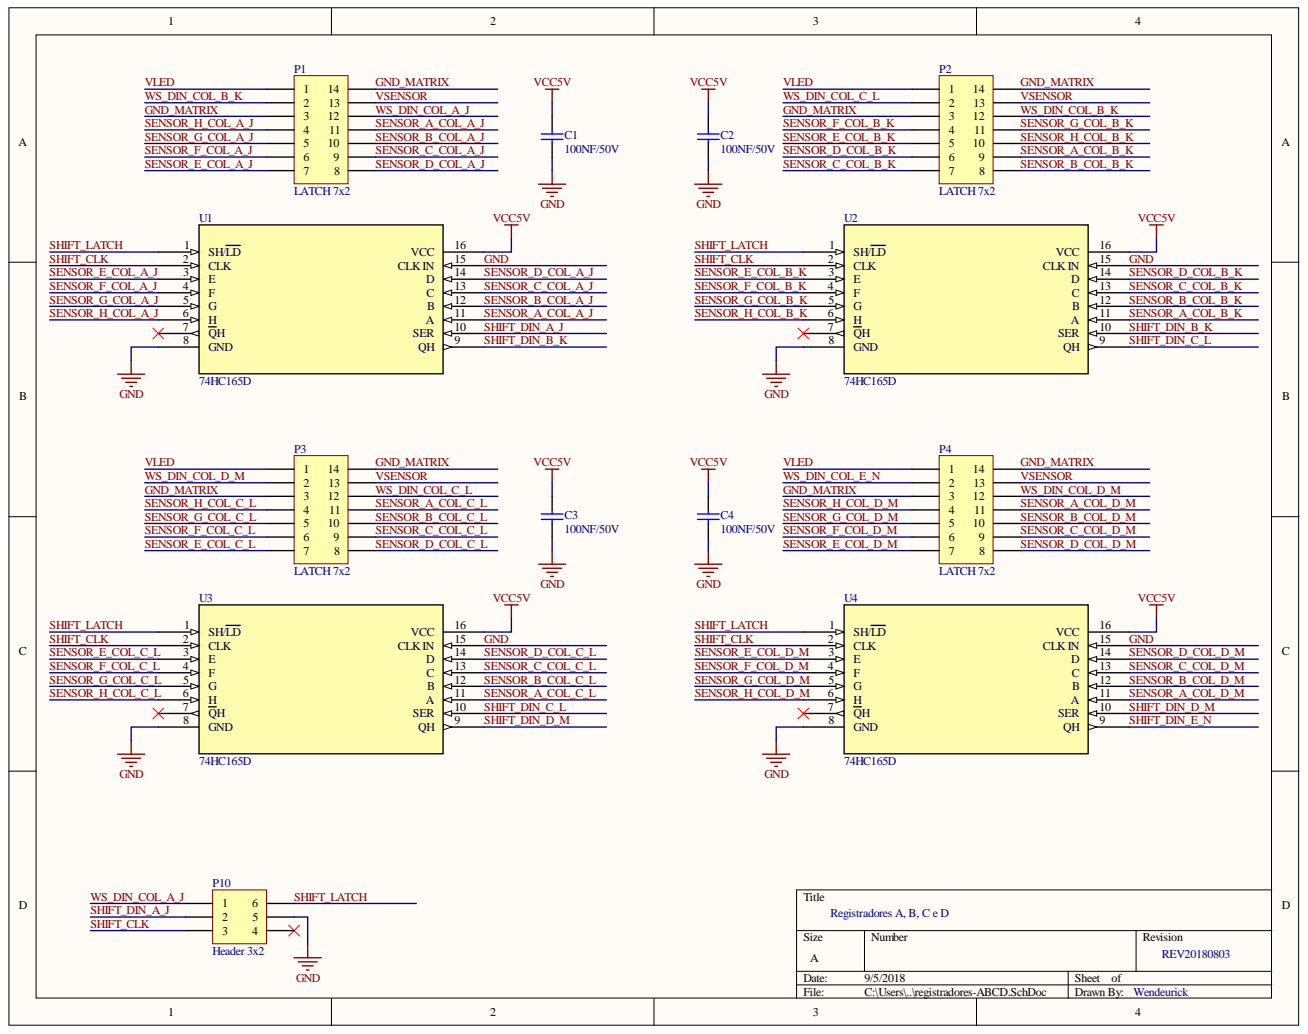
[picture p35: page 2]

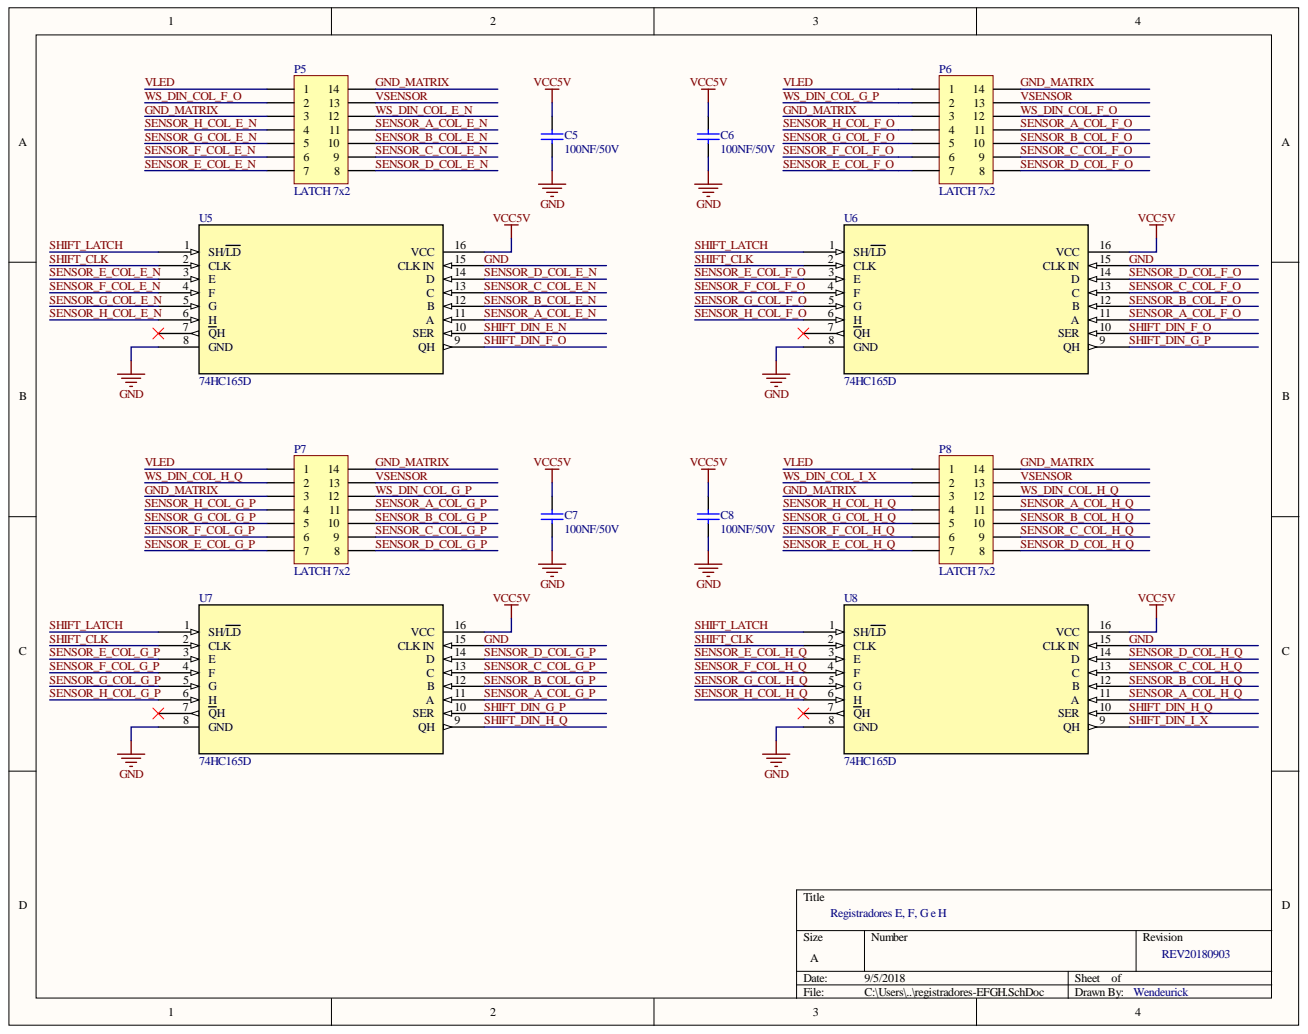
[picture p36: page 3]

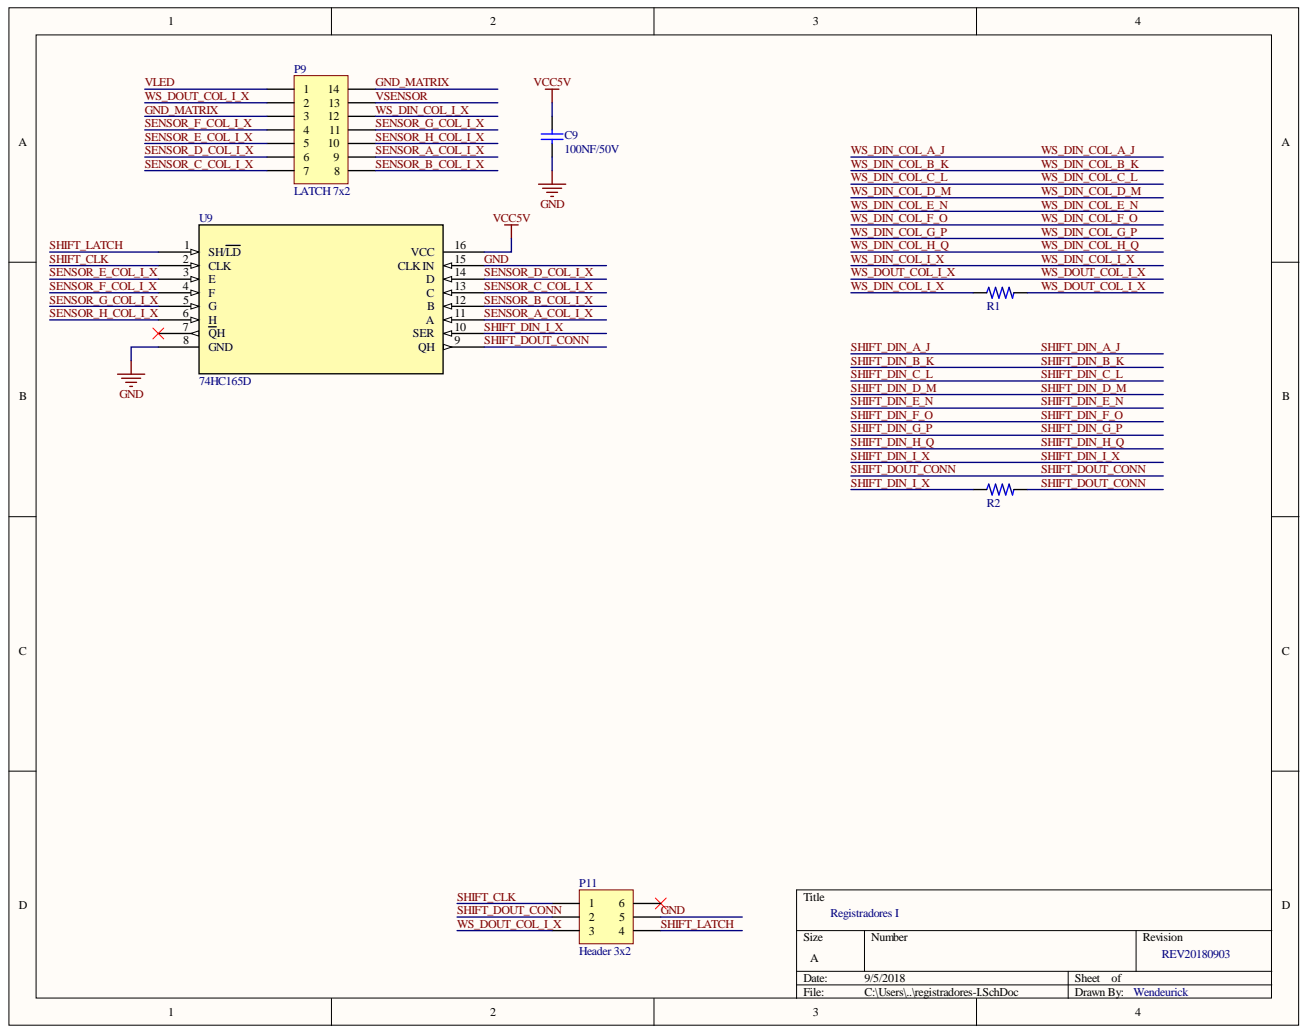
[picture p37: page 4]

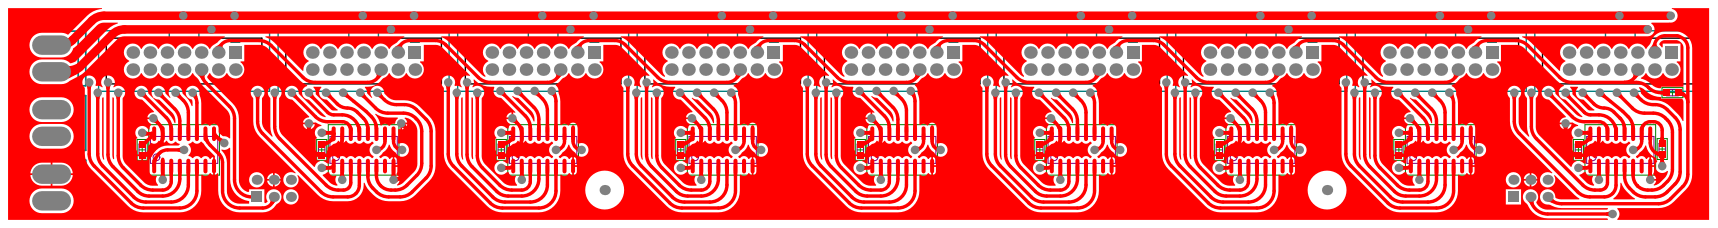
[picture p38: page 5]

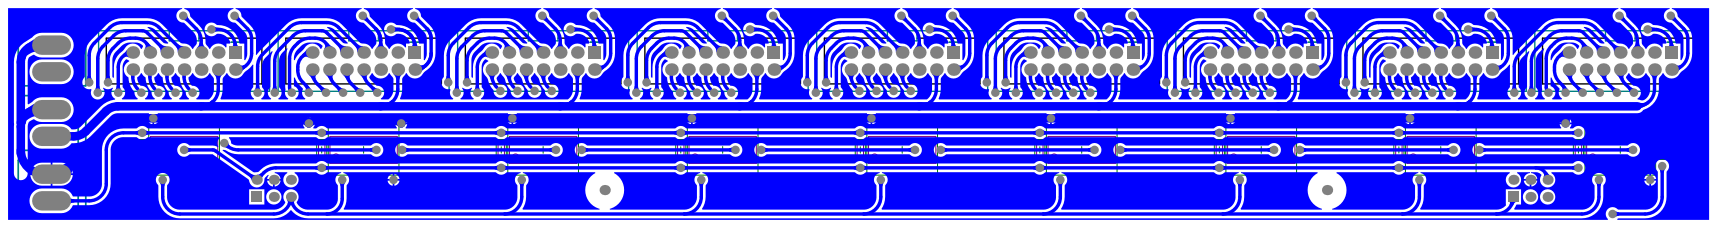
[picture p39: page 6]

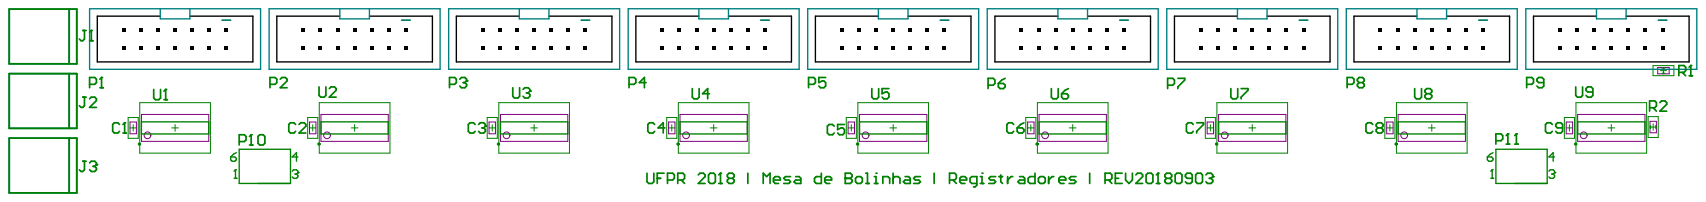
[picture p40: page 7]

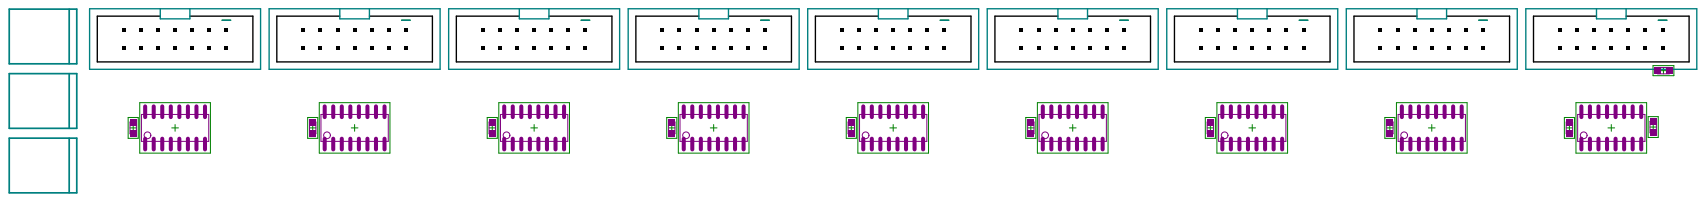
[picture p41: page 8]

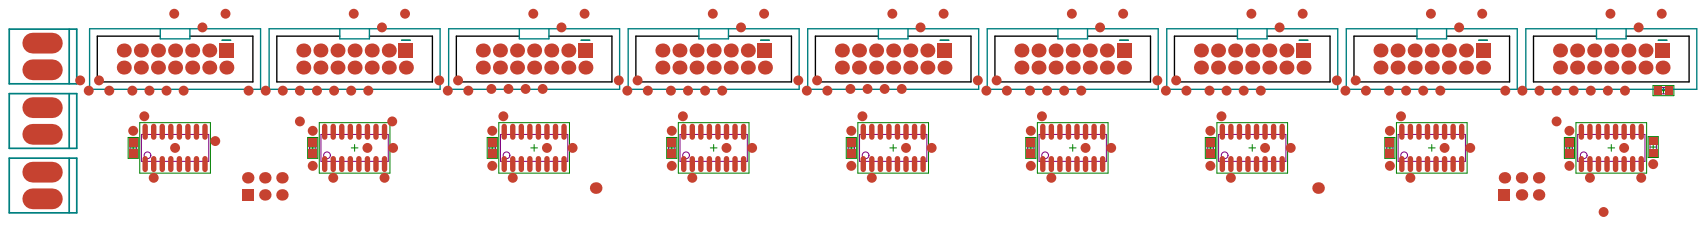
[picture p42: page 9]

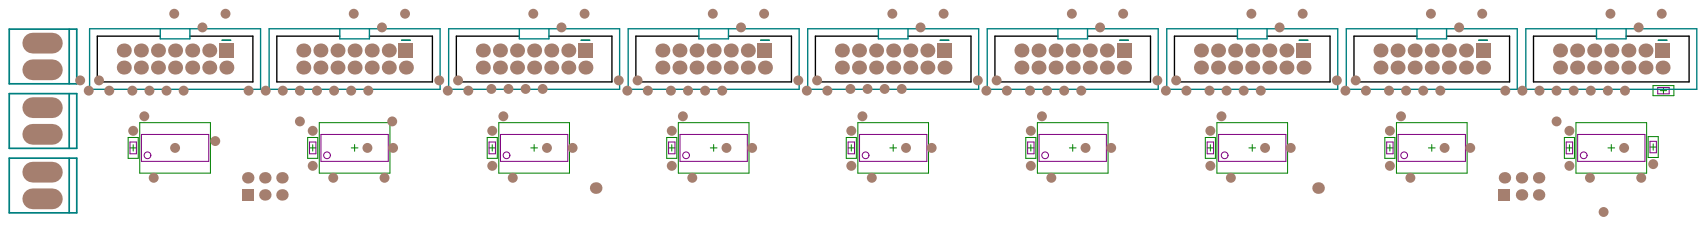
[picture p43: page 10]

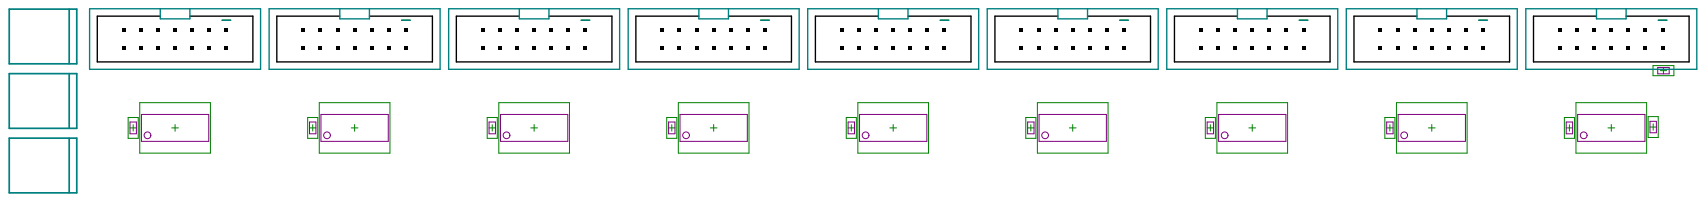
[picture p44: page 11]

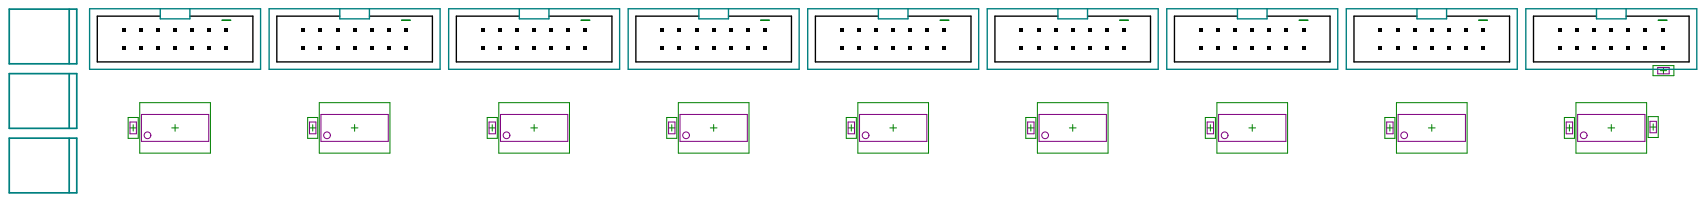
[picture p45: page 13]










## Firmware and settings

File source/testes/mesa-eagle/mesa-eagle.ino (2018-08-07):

// Add 300 - 500 Ohm resistor on first pixel's data input

//https://learn.sparkfun.com/tutorials/shift-registers

#include <Adafruit_NeoPixel.h>
#ifdef __AVR__
#include <avr/power.h>
#endif

#define IR_SENS   6

#define SHIFT_QH  11
#define SHIFT_INH 9
#define SHIFT_SH  8
#define SHIFT_CLK 12

#define LEDPIN    3
#define NLEDS     6

Adafruit_NeoPixel strip = Adafruit_NeoPixel(NLEDS, LEDPIN, NEO_GRB + NEO_KHZ800);

uint32_t color1 = 0xFF0000;
uint32_t color2 = 0x0000FF;

void setup() {
  pinMode(SHIFT_SH, OUTPUT);
  pinMode(SHIFT_INH, OUTPUT);
  pinMode(SHIFT_CLK, OUTPUT);
  pinMode(SHIFT_QH, INPUT);

  digitalWrite(SHIFT_CLK, HIGH);
  digitalWrite(SHIFT_SH, HIGH);

  strip.begin();
  strip.clear();
  strip.show();
}

void loop() {
  byte incoming = read_shift_regs();

  for (uint8_t i = 0; i < NLEDS; i++) {
    byte n = (incoming >> i) & 0x01;
    uint32_t ledColor = (n) ? (LerpColor(color1, color2, float(i) / NLEDS)) : (0x000000);
    strip.setPixelColor(i, ledColor);
  }
  strip.show();
}

byte read_shift_regs() {
  byte the_shifted = 0;  // An 8 bit number to carry each bit value of A-H

  // Trigger loading the state of the A-H data lines into the shift register
  digitalWrite(SHIFT_SH, LOW);
  delayMicroseconds(5); // Requires a delay here according to the datasheet timing diagram
  digitalWrite(SHIFT_SH, HIGH);
  delayMicroseconds(5);

  // Required initial states of these two pins according to the datasheet timing diagram
  digitalWrite(SHIFT_CLK, HIGH);
  digitalWrite(SHIFT_INH, LOW); // Enable the clock

  // Get the A-H values
  the_shifted = shiftIn(SHIFT_QH, SHIFT_CLK, MSBFIRST);
  digitalWrite(SHIFT_INH, HIGH); // Disable the clock

  return the_shifted;
}

uint32_t LerpColor(const uint32_t& from, const uint32_t& to, float amount) {
  if (amount < 0) amount = 0;
  if (amount > 1) amount = 1;

  float a1 = ((from >> 24) & 0xff);
  float r1 = (from >> 16) & 0xff;
  float g1 = (from >> 8) & 0xff;
  float b1 = from & 0xff;
  float a2 = (to >> 24) & 0xff;
  float r2 = (to >> 16) & 0xff;
  float g2 = (to >> 8) & 0xff;
  float b2 = to & 0xff;

  return ((round(a1 + (a2 - a1) * amount) << 24) |
          (round(r1 + (r2 - r1) * amount) << 16) |
          (round(g1 + (g2 - g1) * amount) << 8)  |
          (round(b1 + (b2 - b1) * amount)));
}

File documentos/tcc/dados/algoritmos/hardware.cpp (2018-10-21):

/////////////////////////////////////////////////////////////////
// bibliotecas
/////////////////////////////////////////////////////////////////
// nativas
#include <SmingCore/Digital.h>
#include <Wiring/WConstants.h>
// usuário
#include <hardware.h>
/////////////////////////////////////////////////////////////////
// definições
/////////////////////////////////////////////////////////////////

/////////////////////////////////////////////////////////////////
// dados personalizados, enumerações
/////////////////////////////////////////////////////////////////

/////////////////////////////////////////////////////////////////
// variáveis globais
/////////////////////////////////////////////////////////////////

/////////////////////////////////////////////////////////////////
// variáveis privadas do módulo
/////////////////////////////////////////////////////////////////

/////////////////////////////////////////////////////////////////
// macros
/////////////////////////////////////////////////////////////////

/////////////////////////////////////////////////////////////////
// protótipo das funções privadas
/////////////////////////////////////////////////////////////////

/////////////////////////////////////////////////////////////////
// implementação do módulo
/////////////////////////////////////////////////////////////////

/**
 * @brief Inicialização das portas.
 * @param None.
 * @return None.
 */
void init_gpio()
{
    // LEDs
    pinMode(GPIO_STRIP_DOUT, OUTPUT);
    pinMode(GPIO_LEDS_DOUT, OUTPUT);

    // Sensores
    pinMode(GPIO_POWER_SENSOR, INPUT);
    pinMode(GPIO_LEFTOVER_SENSOR, INPUT);

    // Demais portas não necessitam de inicialização.
}

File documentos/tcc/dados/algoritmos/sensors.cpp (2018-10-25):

/////////////////////////////////////////////////////////////////
// bibliotecas
/////////////////////////////////////////////////////////////////
// nativas
#include <SmingCore/SPI.h>
// usuário
#include <sensors.h>
#include <matrix.h>
#include <tabmask8.h>
#include <hardware.h>
/////////////////////////////////////////////////////////////////
// definições
/////////////////////////////////////////////////////////////////
// Configurações do SPI
#define SPI_FREQ_HZ 4000000
#define SPI_BYTE_ORDER MSBFIRST
#define SPI_MODE SPI_MODE2

// Recarga do timer de debounce: 10 x 10ms = 100ms.
#define DEBOUNCE_TIMER_RELOAD_VALUE ((uint16_t)(10))

// Cada registrador é responsável por 1 coluna. São 17 colunas (matriz) + 1 seletor de cor.
#define NUM_SHIFT_REGITERS (17+1)

// Quantidade de sensores individuais (power button, leftover).
#define NUM_SINGLE_SENSORS (1+1)

// Os bits de "sensorMask" são o espelho dos sensores.
// 128 sensores / 8 bits = 16 bytes
#define MASK_SIZE (16)

// Valor das entradas inválidas.
#define INVALID_INPUT ((uint8_t)0xFF)
/////////////////////////////////////////////////////////////////
// macros
/////////////////////////////////////////////////////////////////

/////////////////////////////////////////////////////////////////
// dados personalizados, enumerações
/////////////////////////////////////////////////////////////////

typedef struct tagSENSOR
{
    uint16_t timer;
    bool previousLevel;
} SENSOR;

/////////////////////////////////////////////////////////////////
// variáveis globais
/////////////////////////////////////////////////////////////////

/////////////////////////////////////////////////////////////////
// variáveis privadas do módulo
/////////////////////////////////////////////////////////////////

/**
 * Máscara dos sensores. Cada bit corresponde a um sensor da mesa.
 */
uint8_t sensorMask[MASK_SIZE];

/**
 * Estruturas de controle da máquina de estados do debounce.
 */
SENSOR sensors[NUM_SENSORS];

/**
 * Entradas mapeadas na máscara dos sensores.
 * Cada byte corresponde a uma entrada (entradas flutuantes, inclusive).
 */
const uint8_t mapped_inputs_in_sensor_mask[8*NUM_SHIFT_REGITERS+NUM_SINGLE_SENSORS] =
{
            // Power button
            0, // input 0

            // Leftover sensor
            1, // input 1

            // Seletor de cor
            2, // input 2
            3, // input 3
            4, // input 4
            5, // input 5
            6, // input 6
            7, // input 7
            8, // input 8
            9, // input 9

            // Coluna A
            10, // input 10
            11, // input 11
            12, // input 12
            13, // input 13
            14, // input 14
            INVALID_INPUT, // input 15
            INVALID_INPUT, // input 16
            INVALID_INPUT, // input 17

            // Coluna B
            15, // input 18
            16, // input 19
            17, // input 20
            18, // input 21
            19, // input 22
            20, // input 23
            INVALID_INPUT, // input 24
            INVALID_INPUT, // input 25

            // Coluna C
            21, // input 26
            22, // input 27
            23, // input 28
            24, // input 29
            25, // input 30
            26, // input 31
            27, // input 32
            INVALID_INPUT, // input 33

            // Coluna D
            28, // input 34
            29, // input 35
            30, // input 36
            31, // input 37
            32, // input 38
            33, // input 39
            34, // input 40
            INVALID_INPUT, // input 41

            // Coluna E
            35, // input 42
            36, // input 43
            37, // input 44
            38, // input 45
            39, // input 46
            40, // input 47
            41, // input 48
            42, // input 49

            // Coluna F
            43, // input 50
            44, // input 51
            45, // input 52
            46, // input 53
            47, // input 54
            48, // input 55
            49, // input 56
            INVALID_INPUT, // input 57

            // Coluna G
            50, // input 58
            51, // input 59
            52, // input 60
            53, // input 61
            54, // input 62
            55, // input 63
            56, // input 64
            57, // input 65

            // Coluna H
            58, // input 66
            59, // input 67
            60, // input 68
            61, // input 69
            62, // input 70
            63, // input 71
            64, // input 72
            INVALID_INPUT, // input 73

            // Coluna I
            65, // input 74
            66, // input 75
            67, // input 76
            68, // input 77
            69, // input 78
            70, // input 79
            71, // input 80
            72, // input 81

            // Coluna J
            73, // input 82
            74, // input 83
            75, // input 84
            76, // input 85
            77, // input 86
            78, // input 87
            79, // input 88
            INVALID_INPUT, // input 89

            // Coluna K
            80, // input 90
            81, // input 91
            82, // input 92
            83, // input 93
            84, // input 94
            85, // input 95
            86, // input 96
            87, // input 97

            // Coluna L
            88, // input 98
            89, // input 99
            90, // input 100
            91, // input 101
            92, // input 102
            93, // input 103
            94, // input 104
            INVALID_INPUT, // input 105

            // Coluna M
            95, // input 106
            96, // input 107
            97, // input 108
            98, // input 109
            99, // input 110
            100, // input 111
            101, // input 112
            102, // input 113

            // Coluna N
            103, // input 114
            104, // input 115
            105, // input 116
            106, // input 117
            107, // input 118
            108, // input 119
            109, // input 120
            INVALID_INPUT, // input 121

            // Coluna O
            110, // input 122
            111, // input 123
            112, // input 124
            113, // input 125
            114, // input 126
            115, // input 127
            116, // input 128
            INVALID_INPUT, // input 129

            // Coluna P
            117, // input 130
            118, // input 131
            119, // input 132
            120, // input 133
            121, // input 134
            122, // input 135
            INVALID_INPUT, // input 136
            INVALID_INPUT, // input 137
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

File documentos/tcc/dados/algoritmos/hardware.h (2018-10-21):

#ifndef MESA_HARDWARE_H
#define MESA_HARDWARE_H

/////////////////////////////////////////////////////////////////
// bibliotecas
/////////////////////////////////////////////////////////////////
// nativas
// usuário
#include <plomodefs.h>
/////////////////////////////////////////////////////////////////
// definições
/////////////////////////////////////////////////////////////////

typedef enum tagGPIO
{
    GPIO_STRIP_DOUT = (uint8_t)16,
    GPIO_SPI_SCK = (uint8_t)14,
    GPIO_SPI_MISO = (uint8_t)12,
    GPIO_SPI_MOSI = (uint8_t)13,
    GPIO_SPI_SS = (uint8_t)15,
    GPIO_LEDS_DOUT = (uint8_t)2,
    GPIO_PROGRAM = (uint8_t)0,
    GPIO_LEFTOVER_SENSOR = (uint8_t)4,
    GPIO_POWER_SENSOR = (uint8_t)5
} GPIO;

/////////////////////////////////////////////////////////////////
// dados personalizados, enumerações
/////////////////////////////////////////////////////////////////

/////////////////////////////////////////////////////////////////
// variáveis globais
/////////////////////////////////////////////////////////////////

/////////////////////////////////////////////////////////////////
// macros
/////////////////////////////////////////////////////////////////

/////////////////////////////////////////////////////////////////
// protótipo das funções públicas
/////////////////////////////////////////////////////////////////
void init_gpio();

#endif //MESA_HARDWARE_H

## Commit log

2018-08-07 todo, cad
2018-08-07 arquivos IC
    [prototipo-placa-perfurada-eagle.sch]
2018-08-07 arquivos engenharia e sociedade ii
    [calculos.ods]
2018-08-07 criado controlador.prjpcb
    [controlador.PrjPcb]
2018-08-07 criado registradores.pcbdoc
    [registradores.PcbDoc]
2018-08-07 criado super.pcbdoc
    [super.PcbDoc]
2018-08-07 criado registradores.schdoc
    [registradores.SchDoc]
2018-08-07 criado super.schdoc
    [super.SchDoc]
2018-08-07 organizacao workspace
    [registradores.PrjPcb, registradores.SchDoc, super.PrjPcb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]
2018-08-14 arquivos cad - maristela
2018-08-25 Reorganização (divisão dos diretórios)
    [calculos.ods, prototipo-placa-perfurada-eagle.sch, registradores.PcbDoc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]
2018-08-25 entrada alimentação
    [alimentacao.SchDoc]
2018-08-27 Proteção entrada, net ties
    [alimentacao.SchDoc]
2018-08-27 Template conexão
    [registradores.SchDoc]
2018-08-28 Removido regulador 3V3 (montado somente na Super)
    [alimentacao.SchDoc]
2018-08-28 Registradores (páginas, net labels)
    [registradores-ABCD.SchDoc, registradores-EFGH.SchDoc, registradores-I.SchDoc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]
2018-08-29 Removida proteção alimentação (sugestão professor)
    [alimentacao.SchDoc]
2018-08-30 Conexões, Designators
    [alimentacao.SchDoc, registradores-ABCD.SchDoc, registradores-EFGH.SchDoc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]
2018-08-30 Posicionamento conectores, CIs
    [registradores.PcbDoc]
2018-08-30 leds e sensores
    [calculos.xlsx]
2018-08-30 removidos os conectores de saída (alimentação)
    a conexão será por cabos para não ter que ter trilhas > 100mil
    [alimentacao.SchDoc]
2018-08-30 Designators devido a remoção dosconectores de alimentação (saída)
    [registradores-ABCD.SchDoc, registradores-EFGH.SchDoc, registradores-I.SchDoc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]
2018-08-31 trilhas, trilhas
    [registradores.PcbDoc]
2018-09-02 Re-endereçamento das conexões de entrada (sensores)
    [registradores-ABCD.SchDoc, registradores-EFGH.SchDoc, registradores-I.SchDoc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]
2018-09-02 Retirados os resistores 0R para o terra
    [registradores-ABCD.SchDoc, registradores-EFGH.SchDoc]
2018-09-02 Soldar resistores 0R da última placa de cada coluna
2018-09-02 Pre finalização
    [registradores.PcbDoc]
2018-09-03 Pré finalização (1 trilha)
    [alimentacao.SchDoc, registradores-ABCD.SchDoc, registradores-EFGH.SchDoc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]
2018-09-04 Transferida a Net Tie para "Mecânica", teardrops, regra do furo de fixação
    [alimentacao.SchDoc, registradores.PcbDoc, registradores.PrjPcb]
2018-09-04 Conferencia net list
    [registradores.PrjPcb]
2018-09-05 Gerber REV20180903
2018-09-05 Movida planilha de calculos para docs/
    [calculos.xlsx]
2018-09-06 REV20180906: polygon conn style: 20mil
    [registradores.PcbDoc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]
2018-09-06 Lista empresas orçamento Registradores
    [orcamento.xlsx]
2018-09-07 Digicart na frente
    [orcamento.xlsx]
2018-09-11 Criação dos capacitores e LEDs, regulador 3V3
    [leds.SchDoc, super.PrjPcb, super.SchDoc]
2018-09-12 Gravação, Baker clamp, divisor resistivo
    [super.SchDoc]
2018-09-18 Planilha de cálculos
    [calculos.xlsx]
2018-09-18 Breakout ESP12, correção FTDI (RTS)
    [super.SchDoc]
2018-09-21 Teclado AD, Manual Flash
    [super.SchDoc]
2018-09-21 Logic-level shifters
    [leds.SchDoc]
2018-09-22 Alimentação, capacitores
    Entrada potência, cap desacoplamento, tensão capacitores
    [super.SchDoc]
2018-09-22 LEDs e lever-shifter
    [leds.SchDoc]
2018-09-22 Conversor nível
    [calculos.xlsx]
2018-09-22 Sensores, shift-register
    [leds.SchDoc, registrador.SchDoc, sensores.SchDoc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]
2018-09-24 Anotações (designators), regra "no source" (?), cap desacoplamento, test points
    [leds.SchDoc, registrador.SchDoc, sensores.SchDoc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]
2018-10-08 Conectores, resistores, BOM
    [registrador.SchDoc, registradores-BOM.xlsx, super-BOM.xlsx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]
2018-10-17 Distâncias LEDs
2018-10-24 Recarga do timer na inicialização
2018-10-25 removido o nivel atual do sensor
2018-10-27 Pré-sempiternal
    [super.PcbDoc, super.PrjPcb, super.SchDoc]
2018-10-27 tearsdrop, poligono, sempiternal
    [sempiternal.PcbDoc, super.PcbDoc, super.PrjPcb]
2018-11-06 SUPER-1-2-3 REV20181104
    [SUPER1.PcbDoc, SUPER2.PcbDoc, SUPER3.PcbDoc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]
2018-11-18 revisão teórica - sensor
2018-11-25 matriz, seletor de cores, interface, shift-register
2018-11-26 PCI controlador
    [calculos.xlsx]
2018-11-26 falta resumo
    [calculos.xlsx]
